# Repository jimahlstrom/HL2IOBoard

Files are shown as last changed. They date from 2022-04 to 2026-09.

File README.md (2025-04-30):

# IO Board for the Hermes Lite 2 by N2ADR
**January 6, 2024**

**Please click the left button "-  ----" above for a navigation menu.**

**Register names are now fixed, but there may be additions. Further documentation is coming, stay tuned.
Please provide feedback, especially if you see a problem.**

This project is a 5 by 10 cm printed circuit board and related firmware. The board mounts in the same box as the Hermes Lite 2.
It mounts above the N2ADR filter board if one is installed.
The filter board and the IO board are independent of each other.
The PC running the SDR software sends the transmit frequency to the board.
The microcontroller on the board then uses the board's switches to control an amplifier, switch antenns or transverters, etc.
There are a variety of IO resources available and there will be different microcontroller software for each application.
The IO board is meant to be a general purpose solution to control hardware attached to the HL2.

The IO board could also be connected to the I2C bus on a single board computer to provide station control.

The board has a Pico microcontroller and IO resources including
5 volt gates, low side switches, a fan controller, and a UART. There are two SMA connectors for a separate Rx input and a Pure Signal input.
The board plugs into the [Hermes Lite 2](http://www.hermeslite.com) main board and replaces the 2x20
jumper that connects to the N2ADR filter board.
The board sits directly above the filter board (if any) as shown in the photos below.

To use the board it will be necessary to choose which switches you need and solder wire jumpers from the switches to the DB9 connector.
Then you must write or download firmware for the Pico that will operate the switches based on the transmit frequency.

#### IO board mounted above the filter board
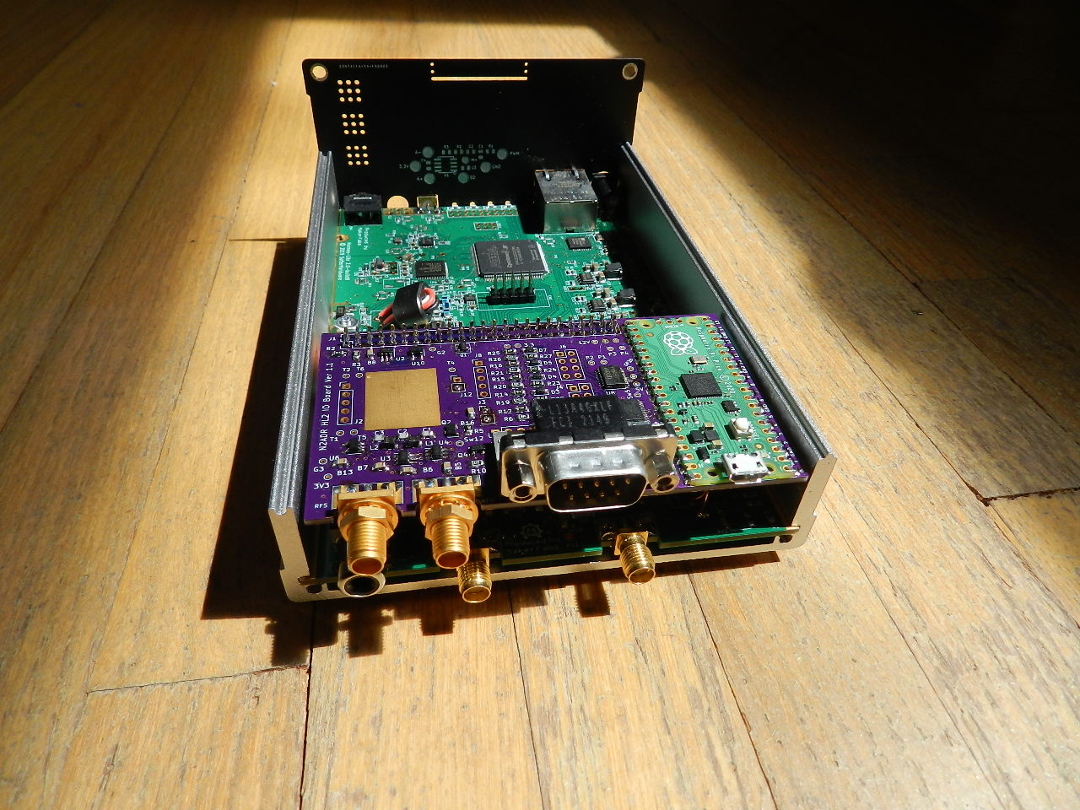
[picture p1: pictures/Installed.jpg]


#### Top view of the board
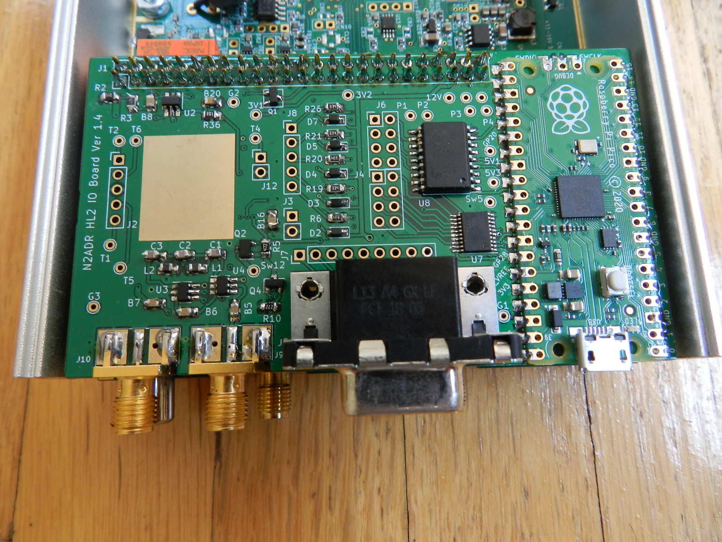
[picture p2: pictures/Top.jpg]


#### Bottom view of the board
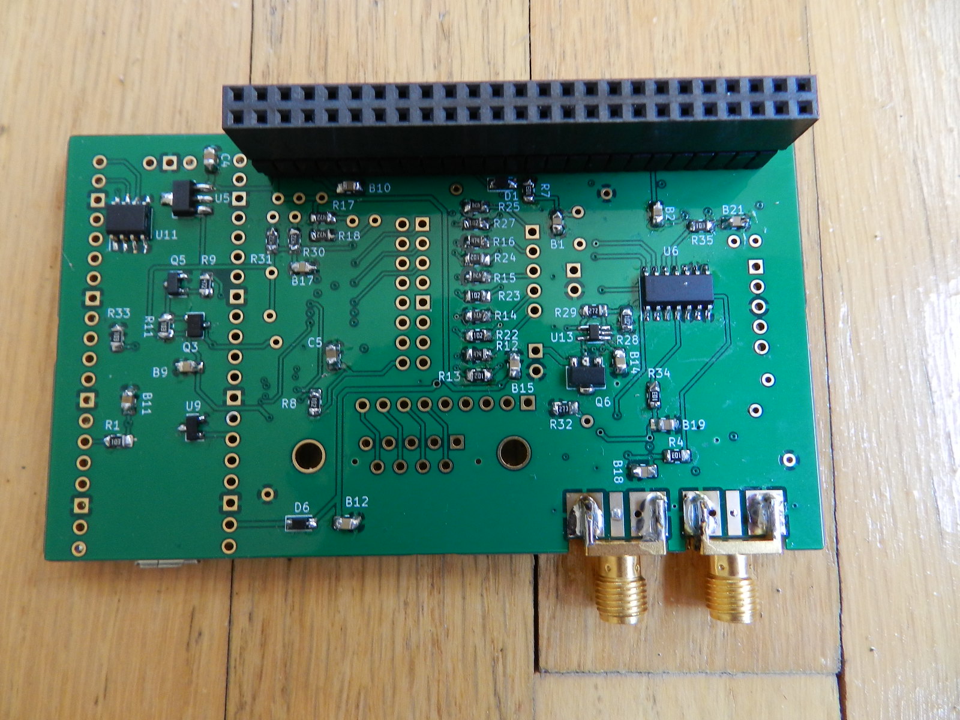
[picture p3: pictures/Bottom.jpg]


## Modification to the HL2 Main Board
The HL2 main board must be modified by adding three extra header pins. In the picture below, look at the normal 20 pin
header at the back edge of the board. Following that, two holes are skipped, and then a 1x3 header is added. This changes the
20 pin header to a 25 pin header with two unused pins. The extra pins provide 3.3 volts, ground and VSUP.
VSUP is the 12 volt HL2 input supply taken after the fuse.
It is convenient to place the 2x20 pin header across the existing pins and the three added pins to provide
alignment when soldering. The IO board has a 2x25 pin header. When installed, this connects the HL2 to the filter board as usual.

For the three-pin header you need the same size as the 1x20 header on the main HL2 board. The pin pitch is 2.54 mm.
On my HL2, the total height is 11.43 mm with 3.05 mm below the PCB. The pins are square and 0.64 mm on a side.
But my HL2 is an old one, so check what size your pins are. The exact height is not too critical.

#### Added three-pin header
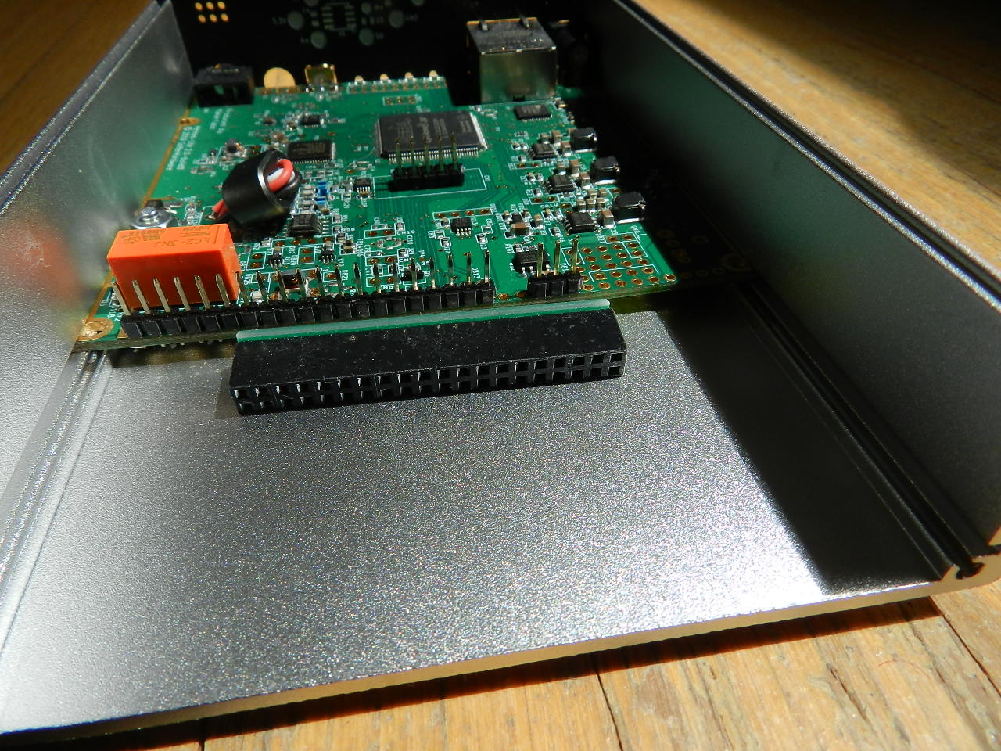
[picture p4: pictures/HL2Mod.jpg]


## Initial Testing of the IO Board
Please test the IO board when you get it.
First program the Pico with the test program.
Power off the HL2 and connect a USB cable to the IO Board.
Push the button on the Pico and then plug the USB cable into your PC.
The Pico will appear as a flash drive on the PC. Then copy the file n2adr_test/build/main.uf2 to the Pico. The Pico will reboot and the Pico LED will flash slowly.

Now apply power to the HL2. Use an oscilloscope to see the test signals.
  * Look for pulses of 1,2,3,4,5,6,7 milliseconds on J4 pins 1 to 7.
  * Look for 3.0 volts DC on J4 pin 8.
  * Look for 0.5 * supply voltage at J3 pin 1.
  * Look for a 5.0 volt 500 Hz square wave at Sw5.
  * Look for a supply voltage 250 Hz square wave at Sw12.

Connector J6 has MOSFETs that short the pin to ground.
To test, connect a DC voltage of 3.3 to 16 volts to one end of a resister of a few thousand ohms.
Connect the other end to an oscilloscpe, and use this end to probe J6 pins 1 to 7.
You should see the same signal as on J4 but with reverse polarity.

The test program can generate a test pattern for the antenna tuner protocol. Write a "1" to REG_ANTENNA_TUNER. SDR authors can use this to help write code for this feature. 

## Design of the IO Board Hardware
The IO board is a four-layer PCB. Rather large parts are used, with none smaller than 0805 (2012 metric). It is designed to be easy to solder at home. It is only necessary to mount the parts you plan to use.

Please refer to the [schematic](KiCad/HL2IOBoard.pdf).
The IO board has two I2C addresses. Address 0x41 register 0 is a read only register that returns the hardware version number
in bits 3 to 0, and 0xF in bits 7 to 4. So for this hardware version, it returns 0xF1. If other IO boards become available,
they will return different version numbers. This is the hardware version and will be returned even if the firmware is not running.
Reading this register can test whether the filter board is installed.

The Pico microcontroller listens to I2C address 0x1D. This is distinct from the filter board I2C address, and the IO board will
not conflict with or control the filter board. The IO board has these resources controlled by the Pico:

 * Eight 5 volt CMOS outputs and eight low-side switches (mosfets to ground). Both are controlled by the same Pico pin,
so they can be used in any combination, but only up to eight total. They are high speed except for output 8. This has an RC filter and is intended for
optional zero to five volt PWM DC output. The DC output can be programmed to change according to the band in use, and is used to
change bands in external amplifiers. If not needed, output 8 can still be an output, but at slow speed.
 * Five logic inputs that are protected, and work from plus 3.3 to 20 volts.
 * A source of switched 12 volt power.
 * A source of switched 5 volt power.
 * A variable DC voltage from zero to about 12 volts. This is intended to drive a fan.
 * A logic input that reads the state of EXTTR from the HL2.
 * An SMA receive input.
 * Control for a switched high pass filter in the receive input.
 * An SMA Pure Signal input.
 * Pico GPIO 5 is unused.
 * Pico GPIO 26, 27 and 28 are unused. They can be used for 3.3 volt logic or for ADC inputs. The ADC reference is 3.00 volts.
 * Any Pico pins can be used directly at 3.3 volt logic.

These resources can be used for various purposes. The Pico has two UARTs. Output 1 and Input 1 can be used for UART Tx and Rx.
Note that the signal voltages are zero and five volts. This is common for communication between microcontrollers.
But the standard RS232 levels are more like plus and minus eight volts, so a connection to a PC will require an interface IC.

A "low-side switch" is a mosfet to ground. They are commonly used to switch relays. But they can also implement a wired-or bus
such as a one-wire bus or an I2C bus. The Icom AH-4 antenna tuner can be controlled this way. The switches are implemented
in a TBD62381AFWG,EL integrated circuit. This has an absolute maximum rating of 50 volts and 500 ma per channel.

**These low-side switches are NOT protected against inductive loads. Always place a diode across relay coils and any other inductive load.**

There is a 15x18 mm bare copper area for prototyping. There is a 1x5 header J2 and a 1x2 header J12 to plug in a perf board for additional area.

The board has a DB9 connector and the pins are wired to a 1x9 pin header. The outputs go to two 2x4 headers, and the inputs go to a 1x5 header.
Other IO goes to small pads. The headers are not installed. Wire everything up as desired with hookup
wire to the pads and to the DB9 pads. Of course, you can add headers if desired.

### Table of IO Resources

|Software Pin Name |Usage|Connector Reference|
|---|-----|---|
|GPIO00_HPF|Control HPF in Rx path||
|GPIO01_Sw12|Switched VSUP (usually 12 volts)|Sw12|
|GPIO02_RF3|Control Pure Signal input||
|GPIO03_INTTR|Control HL2 T/R relay||
|GPIO04_Fan|Zero to 11.5 fan voltage|J3|
|GPIO05_xxx|not connected||
|GPIO06_In5|Protected logic input|J8 pin 5|
|GPIO07_In4|Protected logic input|J8 pin 4|
|GPIO08_Out8|5V logic ; low side switch|J4 pin 8 ; J6 pin 8|
|GPIO09_Out7|5V logic ; low side switch|J4 pin 7 ; J6 pin 7|
|GPIO10_Out5|5V logic ; low side switch|J4 pin 5 ; J6 pin 5|
|GPIO11_Out4|5V logic ; low side switch|J4 pin 4 ; J6 pin 4|
|GPIO12_Sw5|Switched 5 volts|Sw5|
|GPIO13_EXTTR|Logic input EXTTR, High for Rx, low for Tx||
|GPIO14_I2C1_SDA|HL2 I2C bus||
|GPIO15_I2C1_SCL|HL2 I2C bus||
|GPIO16_Out1|5V logic ; low side switch|J4 pin 1 ; J6 pin 1|
|GPIO17_In1|Protected logic input|J8 pin 1|
|GPIO18_In2|Protected logic input|J8 pin 2|
|GPIO19_Out2|5V logic ; low side switch|J4 pin 2 ; J6 pin 2|
|GPIO20_Out3|5V logic ; low side switch|J4 pin 3 ; J6 pin 3|
|GPIO21_In3|Protected logic input|J8 pin 3|
|GPIO22_Out6|5V logic ; low side switch|J4 pin 6 ; J6 pin 6|
|GPIO25_LED|Pico on-board LED||
|GPIO26_ADC0|not connected||
|GPIO27_ADC1|not connected||
|GPIO28_ADC2|not connected||

## IO Board Pico Firmware
### Installing Firmware
Firmwares for the Pico are in subdirectories of HL2IOBoard. Look in the source files to see what they do.

- n2adr_test   Test program to toggle the 5 volt outputs.
- n2adr_basic  Very basic example.
- n2adr_lib    Library of useful subroutines used in the above.
- n1adj_hr50   Control the [Hardrock-50](https://hobbypcb.com/products/hardrock-50-hf-power-amp-kit) amplifier.

To create your own firmware, install the Pico SDK and create a directory for your code.
You may want to clone my github project to get you started.
Export the location of your SDK: export PICO_SDK_PATH=/home/jim/etc/pico-sdk.
Copy the file pico-sdk/external/pico_sdk_import.cmake to your directory.
Copy my CMakeLists.txt and main.c to your directory and edit them as desired.
Make a "build" subdirectory.
Change directories to the build directory and enter "cmake .." and "make".
See the Pico documentation for more detail.
Be careful with i2c_slave_handler(), as it is an interrupt service routine. Return quickly and do not put printf's here! Just set a flag and look for it in the loop at the end of main().

To install the firmware, power off the HL2 and connect a USB cable to the IO Board.
Push the button on the Pico and then plug the USB cable into your PC.
The Pico will appear as a flash drive on the PC. Then copy the file build/main.uf2 to the Pico. 

There is an LED on the Pico. When the firmware is running, it flashes slowly. When the Pico receives I2C traffic directed to its address, it flashes faster.

### Firmware Design

The Pico listens to I2C address 0x1D and you can read and write to registers at this I2C address. Writes always send a one-byte address and one byte of data. Since the address is one byte, the data item is stored in a 256 byte array named "Registers".
All registers are initialized to zero at power on and after a software reset.
You can write to any register, not just the ones in the table below.
So a write to register REG_ANTENNA_TUNER (equal to 7) looks like this:

Registers[REG_ANTENNA_TUNER] = datum;

Reads always send a one byte address and return four bytes of data.
A read from register REG_ANTENNA_TUNER returns Registers[REG_ANTENNA_TUNER] and the next three registers.

There are some exceptions to this general pattern and all are noted below.

The Pico is an I2C slave device, so reads and writes result in a call to the interrupt service routine
in i2c_slave_handler.c. This routine must return fast to avoid hanging the bus. So a typical program would
not alter i2c_slave_handler.c. It would have a polling loop in main.c to check for changes in any registers
it cares about and would perform needed actions there.

#### Frequency Codes

The files n2adr_lib/frequency_code.c and frequency_code.py contain functions to convert a frequency in hertz to a one-byte code,
and to convert a code back to a frequency. The code is a useful one-byte approximation of the frequency
which is sufficient to recognize the band and to select antennas.
The codes are monotonic in frequency. The special code zero means the frequency was not entered and is unspecified.
A table of all the codes is at [frequencycodes.html](http://james.ahlstrom.name/frequencycodes.html).
Run the Python file "python frequency_code.py" to print your own table of codes.

#### Band Codes

A band code is a single frequency code for each band.
The band code is chosen to be as close to the band frequency as possible. All other frequency codes are assigned to the closest band code.
A table of band codes is in hl2ioboard.h.
You can use the band code to select antennas, or you can use the frequency code directly.

The band code is convenient because some bands have multiple frequency codes. And since all frequency codes resolve to the
closest band code, there are no gaps in coverage. If you tune outside the band, the closest band antenna is chosen.

#### Global Variables

These global variables are set in i2c_slave_handler() when data is received:

  * extern uint64_t new_tx_freq;
  * extern uint8_t new_tx_fcode;

The Tx frequency and Tx frequency code are set when the Tx frequency changes.

  * extern bool rx_freq_changed;
  * extern uint8_t rx_freq_high;
  * extern uint8_t rx_freq_low;

These are set when any of the twelve Rx frequencies change. If all Rx frequencies are zero, rx_freq_high and low are both zero.

  * extern uint8_t Registers[256];

This is the array of all register data.

  * extern uint8_t firmware_version_major;
  * extern uint8_t firmware_version_minor;

You must set the version in your main routine so it can be returned to software.

#### Library Functions

The directory n2adr_lib contains utility functions to make writing Pico software easier.

  * void configure_led_flasher(void)

Call this once near the start of your Pico program. It controls flashing the Pico LED.

  * void configure_pins(bool use_uart1, bool use_pwm4a)

This sets the configuration of the Pico GPIO pins, and you must call this once near the start of your program.
If use_uart1, J8 pin 1 and J4 pin 1 are UART pins; otherwise they are regular logic.
If use_pwm4a, J4 pin 8 is used for a variable 0 to 5 volt band voltage; otherwise it is regular logic.

  * uint8_t hertz2fcode(uint64_t hertz)
  * uint64_t fcode2hertz(uint8_t code)

These functions convert between a 5-byte frequency and a 1-byte frequency code. They are in frequencycode.c.
The file frequencycode.py is the same code in Python, and it is not used here. It is included for convenience.

  * uint8_t fcode2band(uint8_t fcode)

This converts a frequency code to a band code. A band code is a single frequency code for each band. See below.

  * void ft817_band_volts(uint8_t band_code)
  * void xiegu_band_volts(uint8_t band_code)

These are used to generate a zero to five volt band voltage on J4 pin 8.

  * i2c_slave_handler.c

This contains the I2C interrupt handler that is called for I2C reads and writes. Since it must return quickly,
it mostly sets registers and global variables that you can test in a loop in your Pico program.
When it receives the Tx frequency, it sets new_tx_freq to the frequency and new_tx_fcode to the corresponding frequency code.
It also uses firmware_version_major and firmware_version_minor, and you must set these in your Pico program.

  * icom_ah4.c

This contains code to control the Icom AH4 antenna tuner. It is untested.

#### Table of I2C Registers

When you write code, please use the register names shown. The names are in i2c_registers.h.

|Register|Name|Description|
|---|----|---|
|0|REG_TX_FREQ_BYTE4|Most significant byte of the 5-byte Tx frequency in Hertz|
|1|REG_TX_FREQ_BYTE3|Next Tx frequency byte|
|2|REG_TX_FREQ_BYTE2|Next Tx frequency byte|
|3|REG_TX_FREQ_BYTE1|Next Tx frequency byte|
|4|REG_TX_FREQ_BYTE0|The least significant byte of the Tx frequency.|

The transmit frequency is a five-byte integer number in hertz. You can send BYTE1 to BYTE4 in any order.
When BYTE0 is sent, the Pico will update the global 64-bit integer new_tx_freq and the 8-bit frequency code new_tx_fcode.
This happens in an interrupt service routine in n2adr_lib/i2c_slave_handler.c.
Use a polling routine in your main.c to look for changes. See the example in n2adr_basic.
If a transverter is in use, the Tx frequency includes the transverter offset.

|Register|Name|Description|
|---|----|---|
|5|REG_CONTROL|Write 1 to reset all the registers to zero.|
|6|REG_INPUT_PINS|Read only. The input pin bits: In5, In4, In3, In2, In1, Exttr|
|7|REG_ANTENNA_TUNER|Control an antenna tuner|

A write to register REG_ANTENNA_TUNER is a command to the tuner. I am modeling this on the Icom AH-4 but I want it to work in general.
See the code in n2adr_lib/icom_ah4.c.
A write of 1 starts a tune request.
A write of 2 is a bypass command. Other tuners may have more commands. The Pico will talk to the ATU and change the register to higher numbers to indicate progress.
The PC must read this register while tuning progresses. If the register reads as 0xEE the PC must send RF to the ATU, and stop RF when 0xEE stops.
A final value of zero indicates a successful tune. Values of 0xF0 and higher indicate that tuning failed.
Note that the IO board can not initiate RF and so the need for 0xEE.
SDR software is not required to implement this command. In the future there may be an external program to do this.

|Register|Name|Description|
|---|----|---|
|8|REG_FAULT|Read only. Zero for no fault. The meaning of non-zero codes is not currently defined.|
|9|REG_FIRMWARE_MAJOR|Read only. Firmware major version|
|10|REG_FIRMWARE_MINOR|Read only. Firmware minor version|
|11|REG_RF_INPUTS|The receive input usage, 0, 1 or 2.|

REG_RF_INPUTS determines how the SMA receive input J9 and the Pure Signal input J10 are used.
Mode 0 means that J9 is not used, and the usual HL2 input is the receive input.
In mode 0 the Pure Signal input J10 is mixed with the receive signal.
For modes 1 and 2, J9 is used instead of the usual HL2 receive input.
Mode 1 means that J9 is used for the receive signal and the Pure Signal input is not available.
Mode 2 means that for receive, J9 is used for the receive signal;
and that for transmit, the Pure Signal input is passed to the HL2 instead of a receive signal.

|Register|Name|Description|
|---|----|---|
|12|REG_FAN_SPEED|The fan voltage as a number from 0 to 255|
|13|REG_FCODE_RX1|The frequency code for the first receiver RX1|
|14-24|REG_FCODE_RX2 to RX12|The frequency code for receiver RX2 to RX12|

The HL2 can have from one to twelve independent receivers. SDR software can use this feature
to scan multiple bands for digital or CW signals. Choosing an antenna requires knowing all the Rx frequencies.
The Rx frequencies are sent as a one-byte frequency code to registers 13 to 24 with names REG_FCODE_RX1 to RX12.
The HL2 always has RX1, but if it is unspecified (zero) it is the same as the Tx frequency.
If any Rx frequency is changed, the global boolean rx_freq_changed is set to true.
If a transverter is in use, the Rx frequency includes the transverter offset.

|Register|Name|Description|
|---|----|---|
|25|REG_ADC0_MSB|The most significant byte of ADC0|
|26|REG_ADC0_LSB|The least significant byte of ADC0|
|27|REG_ADC1_MSB|The most significant byte of ADC1|
|28|REG_ADC1_LSB|The least significant byte of ADC1|
|29|REG_ADC2_MSB|The most significant byte of ADC2|
|30|REG_ADC2_LSB|The least significant byte of ADC2|

The Pico has one 12-bit ADC that can read from ADC0, ADC1 and ADC2 on pins GPIO26, GPIO27 and GPIO28.
Always read the most significant byte first because that triggers the conversion.
A read from ADC0 returns the value of ADC0 and ADC1 in the four byte response.
A read from ADC1 returns the value of ADC1 and ADC2.
Reading the two values in quick succession can be used to calculate SWR from forward and reverse power.

|Register|Name|Description|
|---|----|---|
|31|REG_ANTENNA|Choose among multiple antennas|

Normally, the antenna choice is calculated by the Pico based on the Tx and Rx frequencies.
But there may be multiple antennas available for a single band.
The high four bits of REG_ANTENNA is the Tx antenna, and the low four bits is the Rx antenna for the current band.
A zero means the first (default) antenna.

|Register|Name|Description|
|---|----|---|
|32|REG_OP_MODE|Set the operating Mode|

||Mode|Value|Mode|Value|Mode|Value|Mode|Value|
|---|---|---|---|---|---|---|---|---|
||LSB|0|USB|1|DSB|2|CWL|3|
||CWU|4|FM|5|AM|6|DIGU|7|
||SPEC|8|DIGL|9|SAM|10|DRM|11|
||AM_LSB|12|AM_USB|13|

Operating mode values are based on Thetis internal definitions.
Note that value zero does not mean "unspecified".

|Register|Name|Description|
|---|----|---|
|167|REG_STATUS|Read or write to Sw5 and Sw12. Read the In1 configuration.|
|168|REG_IN_PINS|Same as REG_INPUT_PINS plus Out1 and Out8 configuration.|
|169|REG_OUT_PINS|Read or write to GPIO Out8 to Out1 directly.|
|170|GPIO_DIRECT_BASE|Map this register to GPIO 0|
|171-198||GPIO 1 to 28|

A read or write to registers GPIO_DIRECT_BASE to GPIO_DIRECT_BASE + 28 reads or writes to the Pico GPIO pins 0 to 28.
This supports using Steve's hermeslite.py or similar to control the Pico registers directly.
A user could write a program to switch antennas without adding C code to the Pico.
Since the SDR program writes Tx and Rx frequencies to the Pico, a third party program could read them back to select the antenna.
For C programmers, it would still be easier to write the code into the Pico.

The other registers add further support. Bits are numbered from 7 to zero and the most significant bit is 7.

  * REG_STATUS

Bit 0 is Sw5, bit 1 is Sw12, bit 2 is 1 if In1 is configured as a UART.

  * REG_IN_PINS

This is read-only. It is the same as REG_INPUT_PINS, and adds two bits. Bit 6 is 1 if Out1 is configured as UART.
Bit 7 is 1 if Out8 is configured as band volts.

  * REG_OUT_PINS

This reads and writes Out1 to Out8 directly. Bit 0 is Out1 and bit 7 is Out8.

|Register|Name|Description|
|---|----|---|
|200-255||Reserved for SDR authors. If you use them, please document them.|

## Modifications to SDR PC Software

The IO board connects to the I2C interface in the Hermes Lite 2.
The [HL2 protocol](https://github.com/softerhardware/Hermes-Lite2/wiki/Protocol)
provides a way to send and receive I2C messages from host SDR software to the IO board to control its operation.
Quisk uses the ACK bit with I2C commands. As described in the protocol, these commands should
be sent at intervals so they don't disrupt normal protocol commands.

Since the PC can read and write the I2C bus to communicate with the IO board, it would be possible for SDR software
authors (Quisk, Spark, Power SDR, etc.) to write extensive logic to control IO. This is NOT the desired result. Instead
users should write new Pico firmware to provide the services they require. It is easy to write firmware for the Pico.
Ideally, an owner of a given power amp, for example HR50, would write a custom firmware and provide a wiring diagram for that amp.

**Do NOT ask authors to modify SDR software! Write new firmware instead!**

### Reset

The IO board registers are static and may have old data.
When your SDR program starts, write 1 to REG_CONTROL to set all registers back to zero.

### Transmit Frequency

The only required SDR modification is sending the transmit frequency.
SDR software must send the transmit frequency to provide band information to power amps, transverters and loop antennas.
You can wait for the band to change, and then just send a frequency in the band. For example, if the
user presses the 40 meter button, send 7.0 MHz. This is enough to determine the band, but not enough to tune a loop antenna.
You can send the exact Tx frequency, but since the user is probably doing a lot of tuning, it is best to limit the I2C
traffic. Quisk sends the Tx frequency at a maximum rate of once every 0.5 seconds, and only if it changes. The frequency
data in registers BYTE1 to BYTE4 are static, and are only used when register BYTE0 is written. So you don't need to re-send them unless
they change.

### Receive Frequencies

You may need to send the twelve receive frequencies if your SDR software supports multiple receivers.
The Pico will use this to select a receive antenna, probably by finding the highest frequency and
setting low pass filters to that band. If all Rx frequencies are zero, the Rx band is the same as Tx.

### RF Receive Input

The mode control REG_RF_INPUTS is 0, 1 or 2, and is a user setting. There needs to be an option to set this.

### Fan Control

The fan speed control can be an internal calculation based on temperature, as is currently the case for the fan control
in the HL2 gateware. I don't see the need for a user option for this. Quisk does not implement the fan.

## IO Board Control Software

The software directory contains the Python program n2adr_ioboard.pyw which can be used to control the IO board.
It uses Steve's hermeslite.py software, and a copy is included. To use it, copy the two files to a convenient directory.
You will need to install the netifaces package as follows:

python -m pip install netifaces

Then run the program:

python n2adr_ioboard.pyw

#### Control Program
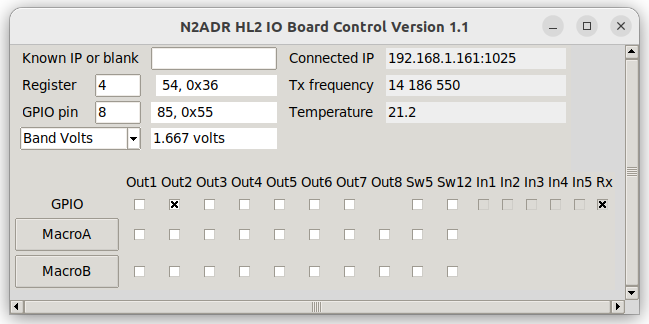
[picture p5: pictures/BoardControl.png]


#### Reduced to a Tool Bar


The program will report the IO board status. You can change the status from the program, and this
may reduce the need to modify SDR programs. It provides a way to control the IO board from Python
rather that write code for the Pico.

Normally the program will search for the HL2. If you need to select one of several HL2's or if searching doesn't work,
enter the IP address and press Enter.

Some fields just report status. Click on the fan voltage or band voltage to change the values.
Click on the GPIO boxes to change the values.
The Macro buttons copy their values to the GPIO row all at once.

The N2ADR control program is not "finished" (does any program ever get finished?) and I invite
a discussion about what it should do.

**End of Documentation**

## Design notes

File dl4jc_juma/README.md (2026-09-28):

# JUMA firmware for the Hermes Lite 2 IO board

Band switching and status readback for a **JUMA PA-100D** (and its RS-928
clone) from a [Hermes Lite 2](http://www.hermeslite.com) through N2ADR's
[IO board](https://github.com/jimahlstrom/HL2IOBoard). The SDR software sends
the transmit frequency to the board over I2C, the Pico turns it into a `=Bn`
band command on the serial port, and the PA's status comes back into I2C
registers the host can read.

This is the same path M0HPF's `m0hpf_spe` firmware takes for an SPE Expert —
Pico UART, a MAX3232 for RS-232 levels, the amplifier's own command set. Only
the commands differ. The parser and the band table are the ones the ESP32
firmware in this repository uses, not a copy, so a corrected band edge is
corrected in both.

> **No warranty.** This switches the band filters of an amplifier, and the
> wrong filter can destroy the output stage. Before the first serious use,
> check the wiring with the PA's built-in RS-232 loopback test and rehearse the
> band switching in STANDBY.

## What you need

| For | |
|---|---|
| Building the firmware | the Pico SDK, ARM's own toolchain (**not** Homebrew's `arm-none-eabi-gcc`, it ships without newlib), and a built `n2adr_lib` from the HL2IOBoard project |
| The hardware | an IO board with a Pico, a **MAX3232** level shifter, and three wires to the amplifier |
| The window | Python 3.8 or newer with **Tk 8.6 or newer**, and `pyserial` only for the USB route |
| Packaging the window | `pyinstaller`, and `pillow` if you want to redraw the icon |

**Tk 8.6 is not a formality.** Apple still ships Tk 8.5 with `/usr/bin/python3`,
and on current macOS it lays this window out correctly and then paints neither
the labels nor the meters — you get a window with three checkboxes in it and
nothing else. `juma_gui.py` checks the version and says so; the packaged
application carries its own Tk and cannot run into it at all.

On Debian and Ubuntu, `python3-tk`. On Fedora, `python3-tkinter`. On macOS,
either a Homebrew `python3` with `python-tk`, or the packaged application.

## What the JUMA needs that the SPE does not

Three properties of the JUMA protocol shape the firmware:

- **It only speaks when asked.** The SPE polls the transceiver; the JUMA
  answers `=R` and is silent otherwise. The Pico is the master here and polls.
- **Remote mode times out.** 5 s after the last command the PA leaves remote
  mode and falls back to STANDBY. The 500 ms `=R` poll is what keeps it alive —
  it is not there for the display.
- **`=Bn` is a *manual* band selection.** It moves the PA from A to M, and a
  band change can knock it out of OPERATE.

Because of the last point the firmware leaves OPERATE alone by default: it
follows the band and touches nothing else. If you want it held in OPERATE, ask
for it — see `JUMA_MODE_HOLD_OPERATE` below.

## Hardware

An IO board, a Pico, and a **MAX3232** level shifter — the PA has true RS-232
levels, and TTL on its input destroys it. The small blue "HW-027" board M0HPF
uses is one option; any MAX3232 breakout works.

**MAX232 is the wrong part**: 5 V only, and its receiver output swings to 5 V.

The plan below puts a **standard RS-232 DTE pinout on the board's own Sub-D
connector**, so a plain Sub-D-to-jack cable goes straight from the board to the
amplifier and nothing is wired inside the box.

### The whole signal chain

```
                      TTL side                      RS-232 side       cable
                      ────────                      ───────────       ─────

 TX   Pico GP16 ──┬─► 74HCT541 ─► J4.1 ══► T1IN            (MAX3232)
                  └──────────────────────► T1IN    T1OUT ══► J7.3 = Sub-D 3 ──► tip
 RX   Pico GP17 ◄─┬── 1K ◄─ divider ◄─ J8.1 ◄══ R1OUT
                  └◄─────────────────────────── R1OUT    R1IN  ◄══ J7.2 = Sub-D 2 ◄── ring

      5 V module:  5V1 pad ═══════════════════► VCC
      3.3 V module: Pico pin 36 or 3V1 pad ═══► VCC
      both:        G1/G2/G3 pad ═════════════► GND   ═══► J7.5 = Sub-D 5 ─── sleeve
```

For each direction take **one** of the two lines: through the board (a 5 V
module) or straight to the Pico pin (a 3.3 V module). Left of the MAX3232
everything is TTL, right of it true RS-232, and the Sub-D ends up with the
pinout of a normal serial port — so the cable to the amplifier is an ordinary
one with nothing clever in it.

### Board side, either way

`configure_pins(true, false)` is what turns J4 pin 1 and J8 pin 1 into the UART,
so those two are not available as a switch output and a logic input — whether or
not you use them for the shifter.

The firmware switches **Sw5** on at start-up, so a 5 V shifter fed from Sw5
comes up with the board rather than looking like a dead amplifier. Wired to 5V1
or to 3.3 V this changes nothing.

Ground: `G1`, `G2` and `G3` are the pads meant for it. M0HPF's instructions use
J12 pin 2, which is ground as well.

### Two ways to wire the TTL side

The board's TTL side is 5 V: J4 pin 1 is the Pico's TX through a 74HCT541
buffer, and J8 pin 1 is a protected input — a divider straight out of the
schematic:

```
J8 pin 1 ──┬── 330K ──┬── 1K ── GPIO17
           │          └── Schottky to +3V3 (clamp)
          470K
           │
          GND
```

The Pico therefore sees `Vin × 470/(330+470) = Vin × 0.59`. Which of the two
routes below you take depends on what your MAX3232 module wants.

#### A 5 V module: J4 pin 1 and J8 pin 1

The straightforward route, the one `m0hpf_spe` uses. A 5 V receiver output
arrives at the Pico as **2.9 V** — a clean logic high — and the buffered output
gives the module the 5 V TTL it expects.

| MAX3232 | IO board |
|---|---|
| `T1IN` — TTL input (`TX`, `TXD`, `<-`) | **J4 pin 1** |
| `R1OUT` — TTL output (`RX`, `RXD`, `->`) | **J8 pin 1** |
| **+** | **5V1** or **5V3** |
| **−** | **G1**, **G2** or **G3** |

One thing to keep an eye on at 115200: the divider's source impedance is
330K∥470K ≈ 194 kΩ, and with the clamp diode and stray capacitance (~15 pF)
that is a time constant of roughly 3 µs against a bit time of 8.7 µs. It works,
but without much to spare — and it explains why the SPE and Hardrock firmwares
never meet this: at 19200 a bit lasts 52 µs. `REG_JUMA_BADLINES` measures it.
If it climbs steadily, replace **R25 (470K)** and **R26 (330K)** with the same
ratio two decades lower, 4.7K and 3.3K: same division, same protection, time
constant down to about 30 ns.

#### A 3.3 V module: straight to the Pico's pins

Going round the board's own input and output needs a reason, so here it is,
twice over. Both come out of the schematic, not out of preference.

**The level does not survive the divider.** In1 divides by 330K/(330K+470K) =
0.59. A 5 V receiver output arrives as 2.9 V, a clean high — but a 3.3 V one
arrives as **1.9 V**, below the RP2040's specified input high threshold. The
Schmitt trigger may well take it; it is not designed to.

**And at 115200 the divider is tight even when the level is right.** Its source
impedance is 330K∥470K ≈ 194 kΩ, and with the clamp diode and stray capacitance
(~15 pF) that is a time constant of roughly 3 µs against a bit time of 8.7 µs.
That is why the SPE and Hardrock firmwares in this project never meet it: at
19200 a bit lasts 52 µs and 3 µs is nothing. At 115200 it is a quarter of the
eye.

Wired straight to the pin, both problems go at once. The full 3.3 V swing
arrives, and the divider network — still hanging off GP17 through R27, 1 kΩ —
now charges its 15 pF through that 1 kΩ instead of 194 kΩ: about 15 ns. The
parasitic load is 3.3 V across roughly 470 kΩ, some 7 µA.

The Pico is mounted with through-hole pads for every pin (`RPi_Pico_SMD_TH`), so
this is a wire, not a rework. Nothing on the board is modified and the firmware
does not change — it is still UART0 on GPIO16/17. A 5 V module has neither
problem and should use J4 pin 1 and J8 pin 1 as every other firmware here does.

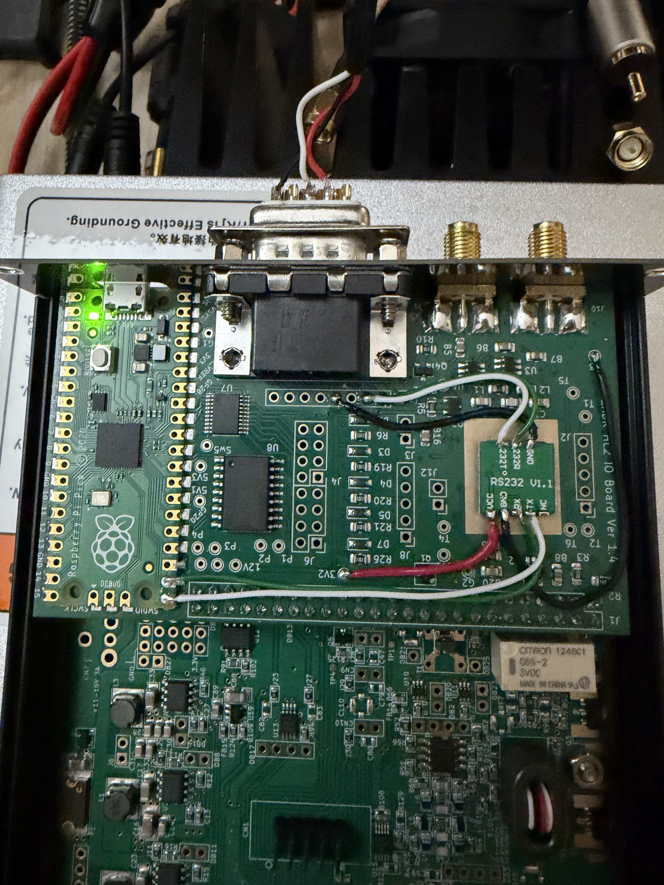
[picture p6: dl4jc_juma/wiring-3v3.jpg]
A 3.3 V module wired this way


Built that way it looks like this: the shifter sits on the free copper in the
middle, red from its `VCC` to the **3V2** pad, the three RS-232 wires off to the
Sub-D on the left, and the two TTL wires down to the Pico's own pins. Nothing is
soldered to J4 or J8 at all.

| MAX3232 | Pico pin | |
|---|---|---|
| `T1IN` — TTL input (`TX`, `TXD`, `<-`) | **21** (GP16) | 3.3 V, ahead of the 74HCT541 |
| `R1OUT` — TTL output (`RX`, `RXD`, `->`) | **22** (GP17) | 3.3 V, past the divider |
| **+** | **36** (3V3 OUT) | or the board's **3V1** / **3V2** pad |
| **−** | GND | **G1** / **G2** / **G3**, or Pico pin 38 |

GP16 is safe to tap: its only other nodes are `U7.8` and `U8.7`, and both are
*inputs* of driver ICs — the 74HCT541 that feeds J4 pin 1 and the TBD62381 low
side switch that feeds J6 pin 1. They never drive back, so one Pico output ends
up driving three inputs. GP17 has exactly one other node, `R27`, the 1 kΩ into
the protection network.

That does have a consequence. The 541's two output enables are hard-wired to
ground, so it is never off, and the TBD62381 input is driven unconditionally:

- **J4 pin 1** carries the transmit data as 5 V logic, and **J6 pin 1**
  switches its MOSFET with every serial bit. Unconnected both are harmless — but
  a relay on J6 pin 1 would chatter at 115200.
- **J8 pin 1** must stay unconnected too: anything driven into it would fight
  the module for GP17.

### Sub-D pinout on the board

Wire the three RS-232 signals to **J7**, the 1x9 header, whose pins go 1:1 to
the Sub-D **J5**. So J7 pin *n* is Sub-D pin *n*.

| Sub-D / J7 pin | Signal | Direction | From |
|---|---|---|---|
| **3** | TxD | board → PA | `T1OUT`, the driver output (`RS232T`, `<-`) |
| **2** | RxD | PA → board | `R1IN`, the receiver input (`RS232R`, `->`) |
| **5** | GND | — | G1 / G2 / G3 |

That is the normal DTE assignment, the same as a PC serial port. **The board's
Sub-D is male** (`DSUB-9_Male_Horizontal` in the schematic), so the cable needs a
**female** Sub-D.

> This deliberately differs from `m0hpf_spe`, which puts the output on pin 2 and
> the input on pin 3. That suits the cable the SPE expects; here the point is a
> connector that behaves the way every RS-232 port does, so the cable is an
> ordinary one.

### The cable

Sub-D 9 female → 3.5 mm stereo jack plug, three wires:

| Sub-D | | JUMA **PA-100D** | **RS-928** |
|---|---|---|---|
| pin 3 | TxD, into the PA | **tip** | **ring** |
| pin 2 | RxD, out of the PA | **ring** | **tip** |
| pin 5 | GND | **sleeve** | **sleeve** |

**The RS-928 has tip and ring the other way round** — that is the one wiring
trap on the clone. Sleeve stays ground on both.

Screened cable, screen on pin 5. Keep it short and away from the coax: this runs
beside a transmitter.

### Which pin on the module is which?

Breakout boards label these differently, and one of the labels is not
trustworthy. On the RS-232 side it is unambiguous: `RS232T` is the driver output
`T1OUT`, `RS232R` the receiver input `R1IN`. On the TTL side a pin marked `TX`
is usually the driver *input* — named from the point of view of the
microcontroller you attach, so it goes to the Pico's TX. Some boards name it
from their own point of view instead, and then it is the other way round.

Getting that wrong puts the Pico's GP16 output against the module's `R1OUT`
output. Two measurements settle it without risk:

1. **Module unpowered**, ohmmeter from each RS-232 pin to GND. The MAX3232's
   receiver input has about 5 kΩ to ground internally, so the pin reading
   **3–7 kΩ** is `R1IN` (`RS232R`). The high-impedance one is `T1OUT`
   (`RS232T`).
2. **Module on 3.3 V, nothing else attached.** Tie the TTL pin you believe is
   the input to GND and measure `T1OUT` against ground: about **+5.5 V**. Tie it
   to 3.3 V instead: about **−5.5 V**, because the driver inverts. If it does
   that, it is the driver input and belongs on GP16.

For the first try a **1 kΩ in series** in the GP16 line costs nothing at 115200
into a high-impedance input, and limits a wrong guess to a few milliamps.

### The whole thing as one table

Seven wires on the board, three in the cable. `→` is the direction the data
travels.

**TTL side** — pick one column for your module.

| MAX3232 module | 3.3 V module | 5 V module |
|---|---|---|
| `T1IN` — TTL **input** (`TX`, `TXD`, `TTL-IN`, `<-`) | **Pico pin 21** (GP16) | **J4 pin 1** |
| `R1OUT` — TTL **output** (`RX`, `RXD`, `TTL-OUT`, `->`) | **Pico pin 22** (GP17) | **J8 pin 1** |
| **+** | **3V2** pad (or Pico pin 36) | **5V1** pad (or 5V3) |
| **−** | **G1** / **G2** / **G3** pad | **G1** / **G2** / **G3** pad |

**RS-232 side** — the same either way. J7 is the 1x9 header; its pin *n* is
Sub-D pin *n* on J5.

| MAX3232 module | Board | Sub-D pin | Signal |
|---|---|---|---|
| `T1OUT` — RS-232 **output** (`RS232T`, `<-`) | **J7 pin 3** | 3 | TxD, board → PA |
| `R1IN` — RS-232 **input** (`RS232R`, `->`) | **J7 pin 2** | 2 | RxD, PA → board |
| **−** | **J7 pin 5** | 5 | GND |

**Cable** — Sub-D 9 **female** (the board's is male) to a 3.5 mm stereo plug.

| Sub-D pin | | PA-100D | RS-928 |
|---|---|---|---|
| 3 | TxD, into the PA | **tip** | **ring** |
| 2 | RxD, out of the PA | **ring** | **tip** |
| 5 | GND | **sleeve** | **sleeve** |

**Leave unconnected**

| | Why |
|---|---|
| **J4 pin 1**, **J6 pin 1** | on a 3.3 V module these still carry the transmit data — 5 V logic and a MOSFET switching at 115200 |
| **J8 pin 1** | on a 3.3 V module it would fight the module for GP17 |
| **Sw5** | the firmware switches it on; only of interest if a 5 V module is fed from there |

**Not part of this** — PTT. The PA is keyed from the HL2 to its own PTT jack,
or through a low-side switch on J6 that the host drives via `REG_OUT_PINS`. See
below.

### Before the first transmission

1. Amplifier in **STANDBY**, no RF.
2. Run the PA's built-in **RS-232 loopback test** (its own menu) with the cable
   plugged in. That checks the cable and the shifter without the Pico having to
   be right.
3. Flash a `JUMA_DEBUG` image (see below) and watch the USB port. A status line
   every 500 ms means the whole chain works. Rubbish instead of readable lines is
   a baud rate or a swapped tip/ring.
4. Read `REG_JUMA_LINK` and `REG_JUMA_BADLINES`. Link 1 and bad lines that stay
   put is what a healthy link looks like.
5. Only then rehearse the band switching, still in STANDBY, and check that the
   band on the PA's display follows the SDR.

### If bad lines keep climbing

`REG_JUMA_BADLINES` is the number to watch, and a steadily climbing one on a
5 V module points at the input divider — see above for the two resistors that
fix it. On a 3.3 V module wired straight to the Pico's pins the divider is out
of the path, so look elsewhere: a swapped tip and ring, a missing ground, or the
cable running alongside the coax.

The JUMA's baud rate is not adjustable, so 115200 is not negotiable either.

### PTT

This firmware does serial control only. The PA is still keyed the normal way —
from the HL2 to the PA's own PTT jack, or through one of the board's low-side
switches on J6 driven by the host via `REG_OUT_PINS`. Nothing here asserts PTT,
and nothing here needs to: the band is set between transmissions.

## Building and installing

### Toolchain

**Do not use Homebrew's `arm-none-eabi-gcc`.** That formula is a freestanding
compiler with no newlib — it has no `libc.a`, and the SDK's very first link
fails with `cannot find -lc`. Take ARM's own build instead:

```sh
cd ~
curl -fLO https://developer.arm.com/-/media/Files/downloads/gnu/14.2.rel1/binrel/arm-gnu-toolchain-14.2.rel1-darwin-arm64-arm-none-eabi.tar.xz
tar xf arm-gnu-toolchain-14.2.rel1-darwin-arm64-arm-none-eabi.tar.xz
ln -s ~/arm-gnu-toolchain-14.2.rel1-darwin-arm64-arm-none-eabi ~/arm-none-eabi
```

The Homebrew cask `gcc-arm-embedded` is the same toolchain, but it installs a
`.pkg` and wants an administrator password. The tarball does not.

### SDK and board library

```sh
git clone -b master --depth 1 https://github.com/raspberrypi/pico-sdk.git ~/pico-sdk
cd ~/pico-sdk && git submodule update --init --depth 1 lib/tinyusb   # for USB stdio

export PICO_SDK_PATH=~/pico-sdk
export PICO_TOOLCHAIN_PATH=~/arm-none-eabi

git clone --depth 1 https://github.com/jimahlstrom/HL2IOBoard        # next to this repo
cd HL2IOBoard/n2adr_lib && mkdir -p build && cd build && cmake .. && make
```

### This firmware

```sh
cd .../esp32-juma/hl2io/juma_pa
mkdir -p build && cd build
cmake ..            # add -DHL2IOBOARD=/path/to/HL2IOBoard if it is not the sibling
make
```

The first run fetches `picotool`, which the SDK builds for itself — that is
normal and takes a minute.

Then power off the HL2, hold the button on the Pico while plugging in USB, and
copy `build/main.uf2` to the drive that appears.

Built here with SDK 2.3.1 and the toolchain above: no warnings, 63.8 kB of
flash and 5.8 kB of RAM.

### Which image to build

Every mode bit can be written at runtime, over I2C or over the USB console, so
the only thing that really needs its own image is the trace. The options below
just decide what a board comes up with, which is what matters when nothing on
the host knows the registers.

| Build | For |
|---|---|
| `cmake ..` | out of the box: follows the band, holds the PA in OPERATE, and says once a second on USB what it and the amplifier are doing |
| `… -DJUMA_HOLD_OPERATE=OFF` | leave a STANDBY standing — for a board that is only meant to watch and follow |
| `… -DJUMA_PROXY=ON -DJUMA_TELEMETRY=OFF` | the USB port is the PA's serial port from power-up, for software that already speaks JUMA |
| `… -DJUMA_DEBUG=ON` as well | the bench: every line, every command, every state change |

| Option | Default | |
|---|---|---|
| `JUMA_TELEMETRY` | **ON** | one status line per second on USB. On by default because it answers "is this thing running" with a terminal and nothing else, which is the first question anybody has — and because `juma_gui.py` reads that line over USB |
| `JUMA_HOLD_OPERATE` | **ON** | put the PA back into OPERATE when it drops to STANDBY — three tries, 5 s apart, never while an alarm is latched, and the counter is reset by every band command, because a band change knocking it out is expected |
| `JUMA_PROXY` | OFF | the USB port carries the PA's serial traffic verbatim. It suppresses the telemetry line, and everything typed at the port reaches the amplifier, so it is something to ask for rather than to be given |
| `JUMA_DEBUG` | OFF | the trace, and leave it off together with `JUMA_PROXY` — a trace line is something the PA would never say |

The same defaults are restored when the host resets the board (a write of 1 to
`REG_CONTROL`), along with the firmware's own retry counters and the frequency it
was following — after such a reset no band command goes out until a new frequency
arrives.

### The USB console

Type into it with any terminal; USB CDC ignores the baud rate.

```sh
pio device monitor -p /dev/cu.usbmodem*        # or: screen /dev/cu.usbmodem* 115200
```

| What you type | |
|---|---|
| `=R`, `=O`, `=C`, `=G2`, … | goes to the PA. `=Bn` only with band following off; `=A` switches following off as it goes |
| `mode=0E` | set `REG_JUMA_MODE` |
| `mode+04` / `mode-08` | set or clear those bits, leaving the rest of the byte alone |
| `bootsel` | reboot into the bootloader. The button needs a RESET to be sampled, and plugging in USB does not reset a Pico already powered from the radio — so with the HL2 switched on the button does nothing and this is the way in |
| `reg=51:02` | write any register — `REG_JUMA_SET_GAIN` = 2 here |

`mode+` and `mode-` are what a program uses: switching the telemetry feed on
should not force it to decide, blindly, what happens to the OPERATE hold.

Anything longer than the PA's own commands is refused rather than truncated —
half of a mistyped command is worse than none of it.

With no terminal attached, printing costs nothing: the SDK discards the output as
soon as it sees the port is not open. A terminal that is attached and then stops
reading does cost something, so these builds lower
`PICO_STDIO_USB_STDOUT_TIMEOUT_US` from 500 ms to **10 ms** — a stalled reader
loses output rather than costing the PA its remote mode.

## What it does

- **Follows the transmit frequency.** `new_tx_freq` from the I2C handler goes
  through the shared band table, and `=Bn` goes out once the frequency has held
  still for 150 ms. No band command is ever sent while either the HL2 (EXTTR)
  or the PA (status field 3) says transmit.
- **Stays off bands the PA has no filter for.** 6 m, 60 m, out-of-band: no
  command goes out at all, and the PA keeps the band it had. Same when the HL2
  has not sent a frequency yet — it is not given a guessed default.
- **Keeps the PA on M while it is doing the selecting.** If the PA reports A it
  gets a `=Bn` for the band it is already on, which moves it to M and changes
  nothing else. Three attempts, then it gives up and says so, so a choice made
  at the front panel is not overridden for ever.
- **Polls every 500 ms** and publishes the 13 status fields into I2C registers.
- **Keeps the band it last set** when the host stops sending. There is no
  "connection lost" on this bus — a write to `REG_CONTROL` clears the frequency,
  and the PA is then left where it is rather than moved somewhere. Write
  `JUMA_CMD_AUTO_BAND` to hand band selection back to the PA.
- **Leaves OPERATE alone**, unless asked to hold it. Even then it will not
  argue with an alarm — a protective shutdown stays shut down until somebody
  clears it deliberately.

## I2C registers

The board's own registers are unchanged (see the
[HL2IOBoard README](https://github.com/jimahlstrom/HL2IOBoard#table-of-i2c-registers)).
This firmware adds a block at 0x40, clear of the upstream range, and defines
`REG_FAULT`. Names are in `juma_regs.h`. A read returns four bytes from the
address given, so related values sit next to each other.

| Reg | Name | |
|---|---|---|
| 0x40 | `REG_JUMA_MODE` | rw — standing behaviour, see below |
| 0x41 | `REG_JUMA_CMD` | rw — one-shot command, cleared once sent |
| 0x42 | `REG_JUMA_LINK` | 1 = the values below are fresh |
| 0x43 | `REG_JUMA_FLAGS` | state bits, see below |
| 0x44 | `REG_JUMA_BAND` | band the PA reports, 1 (160 m) … 9 (10 m), 10 = unknown |
| 0x45 | `REG_JUMA_WANT_BAND` | band this firmware wants, 0 = none or not covered |
| 0x46 | `REG_JUMA_GAIN` | attenuator 1…4 (G1 = 6 dB … G4 = 0 dB) |
| 0x47 | `REG_JUMA_ALARMS` | alarm bits as the PA reports them |
| 0x48 | `REG_JUMA_SWR` | VSWR × 10 — 14 is 1.4 |
| 0x49 | `REG_JUMA_VOLTS` | supply volts × 10 |
| 0x4A | `REG_JUMA_AMPS` | current, amps × 10 |
| 0x4B | `REG_JUMA_TEMP` | temperature, two's complement, scale per `FLAGS` bit 3 |
| 0x4C | `REG_JUMA_WATTS_MSB` | output power in watts, 16 bit |
| 0x4D | `REG_JUMA_WATTS_LSB` | |
| 0x4E | `REG_JUMA_FAN` | 0 off, 1 slow, 2 medium, 3 fast |
| 0x4F | `REG_JUMA_REPLIES` | status replies, low byte — counts up while the link lives |
| 0x50 | `REG_JUMA_BADLINES` | lines that were no status reply, low byte |
| 0x51 | `REG_JUMA_SET_GAIN` | rw — write 1…4 for `=Gn`, cleared once sent |
| 0x52 | `REG_JUMA_SET_BAND` | rw — write 1…9 for `=Bn`, cleared once sent; only while `NO_BAND` is set |
| 0x53 | `REG_JUMA_LOST` | bytes dropped by a full receive buffer, low byte |
| 0x54–0x55 | `REG_JUMA_VOLTS100_*` | supply volts × 100, 16 bit — for a display that wants 13.66 V, not 13.6 |
| 0x56–0x57 | `REG_JUMA_AMPS100_*` | current × 100, 16 bit |
| 0x58–0x59 | `REG_JUMA_WATTS10_*` | output power × 10, 16 bit |
| 0x5A–0x5B | `REG_JUMA_SWR100_*` | VSWR × 100, 16 bit |
| 0x5C | `REG_JUMA_BANNER_IDX` | rw — which character of the PA's power-up banner to look at; 0 asks for its length |
| 0x5D | `REG_JUMA_BANNER_CH` | that character, or the length at index 0 |
| 0x5F | `REG_JUMA_SNAP` | wo — write anything to take a snapshot, see below |
| 0x60–0x7B | snapshot | seven stamped groups of four, see below |

`REG_JUMA_MODE`, all bits clear at power-on and that is the intended normal
case:

| Bit | |
|---|---|
| 0 `JUMA_MODE_NO_BAND` | do **not** send `=Bn` on a frequency change |
| 1 `JUMA_MODE_HOLD_OPERATE` | put the PA back into OPERATE when it drops to STANDBY — three attempts, 5 s apart, never while an alarm is latched |
| 2 `JUMA_MODE_TELEMETRY` | one status line per second on the USB port, see below |
| 3 `JUMA_MODE_PROXY` | the USB port carries the PA's serial traffic verbatim |

`REG_JUMA_CMD` — write, and the firmware clears it once the command has gone
out to the PA. The two power-off codes sit far from the small numbers on
purpose, so a host walking through register values cannot switch the amplifier
off by accident.

| Code | | |
|---|---|---|
| 1 | `JUMA_CMD_OPERATE` | `=O` |
| 2 | `JUMA_CMD_STANDBY` | `=S`, and clears the OPERATE hold |
| 3 | `JUMA_CMD_AUTO_BAND` | `=A`, and sets `NO_BAND` — the PA selects for itself from here. Clear bit 0 of `REG_JUMA_MODE` to take over again |
| 4 | `JUMA_CMD_CLR_ALARM` | `=C` |
| 0xA0 | `JUMA_CMD_POWER_OFF` | `=P0` — switches the PA off, state discarded |
| 0xA1 | `JUMA_CMD_POWER_SAVE` | `=P1` — switches the PA off, state saved |

`REG_JUMA_FLAGS`: bit 0 OPERATE · 1 the PA selects bands itself · 2 the PA says
transmit · 3 temperature in °C, else °F · 4 band following is on · 5 EXTTR from
the HL2 says transmit.

`REG_JUMA_SET_BAND` is refused, with `JUMA_FAULT_BAD_CMD`, while band following
is on: a follower and a host both moving the filter would be a filter that moves
on its own. Switch `JUMA_MODE_NO_BAND` on first, then set the band.

`REG_FAULT` (register 8) as a bit field: bit 0 no status reply from the PA ·
1 an alarm is latched · 2 a register was written with a value it cannot take.

The measurements always hold the last values received, whether or not the link
is still alive. `REG_JUMA_LINK` is what says how far to trust them; a
`REG_JUMA_REPLIES` that has stopped counting is the other sign.

Alarm bits, from the PA: 0 high SWR · 1 over-current · 2 high temperature ·
3 high voltage · 4 low voltage pre-limit · 5 low voltage final limit.

## Being found by the SDR software

The board only follows the band if the SDR software sends it the transmit
frequency, and some software will not do that until it has recognised the
board. deskHPSDR looks for the PCA9536 at I2C **0x41** and expects four bytes
of `0xF1`; an N2ADR IO board answers that in hardware, with or without firmware
running. Failing that it reads **register 33** from the Pico at 0x1D and expects
**0xEF**, and that is the path for a board built without the PCA9536 — the
comment beside that code says it is there

> so you can use N2ADRs firmware code base for your own projects without buying
> the IO Board for the HL2

So this firmware answers register 33 with `0xEF`. On a real IO board it changes
nothing, because 0x41 has already done the job; it is there for the home-built
case. Register 34 is read afterwards as a low-pass filter bitmask and stays
zero, which deskHPSDR shows as "OFF". That is correct and not a gap: the
low-pass filter board is switched by the HL2's own gateware, and the board
documentation is explicit that "the IO board will not conflict with or control
the filter board". The Pico cannot read its state, so it reports none rather
than deriving a plausible-looking guess and passing it off as a measurement.

deskHPSDR also has **Radio → HL2 Force IO Board**, which skips detection
altogether.

### If the band does not follow

Check which frequency the software is actually sending. deskHPSDR sends
`vfo[txvfo]` — the **transmit** VFO, not the one being listened to. In split, or
after changing band on the receiving VFO alone, the transmit frequency does not
move, so neither does the filter, and everything downstream is behaving
correctly while appearing not to.

That is worth knowing before suspecting anything else: it cost an evening here.
The register held one unchanging value through 150 s of watching with not a
single failed read, and the reason was on screen the whole time — 14.074 above,
7.170 below.

## Never two commands in a row

This is the one thing to know about the HL2's I2C bridge, and it cost two days
to find: **commands sent back to back stop it.** Not too many commands — too
close together.

Measured with `tools/stress_bridge.py`, same 26 commands a second both times,
one variable changed:

| Shape | Result |
|---|---|
| one at a time | 30 minutes, **47 355 commands**, not a blink |
| bursts of 24 | dead after **19 454 commands**, 15.3 minutes |

When it goes, it goes completely: SDA is held low, no register write arrives,
and the bridge stops answering on **both** command addresses — `0x3d` for the
expansion bus and `0x3c` for the internal clock bus. So it is not the
`i2c_bus2` state machine, it is the command path itself. The radio still answers
discovery, so from the network it looks alive.

Nothing gets it back but a power cycle of the radio. Clocking the bus free from
the Pico does release SDA — the firmware does this, and `rec=` in the telemetry
counts it — but the master never resumes, and SDA is pulled down again within
the minute. It was tried, it is measured, and it is not a cure.

What this means for anything talking to the board:

- **A window polls with one command per tick.** `Hl2Link.poll()` advances a
  snapshot by exactly one command and hands back a reading when a whole set has
  arrived; `juma_gui.py` ticks it every 150 ms.
- **A script that needs an answer now pays for it in time.** `read_status()`
  drives `poll()` with `Hl2Link.PACE` between commands and takes about a second.
  `alive()` is one command, for the common case of only wanting to know whether
  the radio is there.
- **Nothing in `juma_link.py` sends two in a row any more**, including the paths
  that used to: the old register-by-register read, the banner reader, and the
  connection check that ran on every start.

It also explains the earlier history here. A window polling in bursts of eight
killed the bus in 31 minutes; the same window at one command per 150 ms ran for
6 h 33 before the last bursts left in it — a connect-time snapshot — caught up
with it.

## One program at a time on the bridge

The HL2's I2C bridge serves one caller. While SDR software holds the radio's
data stream, a second program gets no answers at all: discovery still works,
`ping` still works, and every command packet goes unanswered. The same applies
between two copies of the window, or a window and a script.

That is a property of the radio, not of this firmware, and it has a practical
consequence worth stating plainly: **the band switching does not depend on any
of it.** The firmware follows the frequency, holds OPERATE and handles alarms
on its own, with no host involved. What the bridge is needed for is watching and
hand control — and while the radio is transmitting for somebody else, that has
to go over the Pico's USB port instead. The window says so when it happens,
rather than showing a timeout.

## Reading it without being lied to

The HL2's I2C bridge drops a command that arrives while it is busy. The gateware
says so plainly — `i2c_bus2.v`, `// Missed` — and then `cmd_resp_data` still holds
the **previous** read's four bytes. Worse, `hermeslite_core.v` does not even wire
up the bridge's acknowledge line (`.cmd_ack() // No need for ack`), so the host
has no way of being told.

Measured against a real HL2: about **one round in 25** came back shifted. A
temperature that was really a reply counter, an alarm that was really a band
number. Waiting longer does not help — 0.2 s gave one bad round in 25, 0.35 s
gave none, 0.5 s gave one again. The drops are random, not a timing threshold.

So the data carries its own proof. Write anything to `REG_JUMA_SNAP`; the
firmware copies the current values into seven groups of four and stamps each
group's first byte with

```
stamp = (generation << 3) | group number
```

The host reads the groups and checks that every one carries its own number, that
all generations agree, and that the generation has moved on since last time.
Both halves are needed: the generation catches a group left over from an earlier
snapshot, the group number catches a dropped read handing back a *different*
group of the same snapshot — which a single shared tag would wave through. That
was not theory; the first design had one tag and a test with simulated drops
caught it.

| Group | | | |
|---|---|---|---|
| 0x60 | stamp | link | flags | band |
| 0x64 | stamp | want band | gain | alarms |
| 0x68 | stamp | volts ×100 MSB | LSB | temp |
| 0x6C | stamp | amps ×100 MSB | LSB | fan |
| 0x70 | stamp | watts ×10 MSB | LSB | mode |
| 0x74 | stamp | VSWR ×100 MSB | LSB | fault |
| 0x78 | stamp | replies | bad lines | lost bytes |

Payloads are written before the stamps. The I2C interrupt can serve a read in
the middle of that, and then the group still carries its old stamp — which is
exactly the mismatch the host is watching for. The other way round would hand
out a group that looks coherent and is not.

`hl2io/tools/juma_link.py` does the checking and reads again on a mismatch.

Over an hour of continuous use: **3152 rounds, 97 of them retried** — 3.1 %,
which agrees with the one-in-25 seen in the short runs, and not one wrong value
reached the display. Under a simulated one-in-40 drop rate the tests deliver 25
of 25 rounds with none wrong, and under one-in-2 they report failure rather than
guessing.

The same hour is worth reading for what it says about the *other* link: **not a
single unparseable line from the PA and not a single lost byte**, at 115200 over
a shifter wired straight to the Pico's pins. The divider that would have sat in
that path is discussed under the wiring, and this is the measurement that says
avoiding it was worth the two extra wires.

## The one rule this firmware has to keep

**Never disable interrupts, and never write flash.**

The Pico is an I2C **slave** on the radio's expansion bus. A slave that cannot
answer in time does not simply fall behind — the hardware pulls SCL low and
holds it, which is exactly what I2C asks it to do. It means "wait", and the
master must. The line comes back up when the interrupt handler runs.

So anything that keeps that handler from running hands the whole bus a brake:

    save_and_disable_interrupts()   flash_range_erase()   flash_range_program()
    critical sections, long ISRs, anything busy-waiting with interrupts masked

And the master on the other end has nothing to get out with. The gateware drops
whatever arrives while it is busy (`i2c_bus2.v`, `// Missed`), does not even wire
up the bridge's acknowledge line (`hermeslite_core.v`, `.cmd_ack() // No need for
ack`), and has neither a timeout nor a bus recovery. Measured here: once that
master stops, it stays stopped for **hours** — 7.7 of them in one case — and only
a power cycle of the radio brings it back. The filter board sits on the same bus
with its own address, so its relays stop switching too. From the outside the
whole radio looks broken.

A flash write cost tens of milliseconds of that, which is why the mode is no
longer kept (below). As of this writing the firmware holds the rule: `sleep_ms(1)`
paces the loop and nothing masks an interrupt anywhere. `printf` to the USB port
can block the main loop for up to 10 ms, but interrupts stay on and the I2C
handler keeps running, so that is fine.

Worth checking before adding anything that touches flash, timing or a critical
section:

    grep -n 'save_and_disable_interrupts\|critical_section\|flash_range' main.cpp

Empty is the correct answer.

## The mode is not kept

`REG_JUMA_MODE` comes up as the compiled `JUMA_MODE_AT_BOOT` and stays in RAM. A
host that wants something else writes it after every start; a host reset
(`REG_CONTROL` = 1) puts the compiled value back.

It used to be written to the last flash sector, and that is out for one reason:
an erase runs with interrupts off for tens of milliseconds, and during that the
Pico cannot serve its I2C slave, so the RP2040 holds SCL low. The HL2's master
has no timeout and no bus recovery — `i2c_bus2.v`, and `hermeslite_core.v` does
not even wire up the acknowledge line — and the filter board sits on that same
expansion bus with its own address (`HL2IOBoard/README.md`: the Pico's 0x1D is
"distinct from the filter board I2C address"). One erase in the wrong moment can
take the whole bus down, filter relays included. Seen here: nothing on the
expansion bus answered any more, and only a power cycle of the HL2 brought it
back - the SDR software, the Pico and the PA were all innocent and all looked
guilty.

A mode that survives a power cycle is a convenience. A wedged I2C bus costs the
station. So the OPERATE hold, the proxy and the telemetry feed are build options
again, or something the host sets each time.

## Telemetry on the USB port

With `JUMA_MODE_TELEMETRY` set — by `cmake -DJUMA_TELEMETRY=ON ..`, or over I2C
at any time, in any image — the firmware puts one line per second on the USB
serial port:

```
JUMA up=312 link=1 mode=06 fault=00 want=5 rep=624 bad=0 lost=0 wr=91 idle=0 sda=1 scl=1 slow=0 clow=0 rec=0 raw=O:A:T:C:5:1:1.0:14.09:8.1:27.2:26:0:0
```

Space separated `key=value`, so a program reads it with a `split()`. The fields
before `raw=` are the firmware's own view:

| | |
|---|---|
| `up` | seconds since the board started |
| `link` | 1 while the status is fresh |
| `mode` | `REG_JUMA_MODE`, hex |
| `fault` | `REG_FAULT`, hex |
| `want` | the band the firmware wants, 0 = none or not covered |
| `rep` | status replies received |
| `bad` | lines that were no status reply |
| `lost` | bytes dropped by a full receive buffer |

Everything after `raw=` is **the PA's own status line**, with the blanks taken
out and nothing else changed. No value is rescaled on the way, so nothing is
lost to rounding — and it can be fed straight back into `jumaParseStatus()`, the
same parser both firmwares here use. `tests/run.sh` checks that removing the
blanks changes none of the 13 fields.

A consumer in Python is then about four lines:

```python
import serial
pa = serial.Serial('/dev/ttyACM0')
for line in pa:
    if line.startswith(b'JUMA '):
        f = dict(kv.split(b'=', 1) for kv in line.split()[1:])
        print(f[b'raw'].split(b':'))      # the 13 fields, as the PA sent them
```

USB CDC ignores the baud rate. The write blocks while a host is attached but not
reading, so this build lowers `PICO_STDIO_USB_STDOUT_TIMEOUT_US` from its default
500 ms to **10 ms**: a stalled reader loses output rather than costing the PA its
remote mode.

### Controlling it from the PC

The same three-line loop can go the other way. The SDR software already reaches
the board through the HL2's I2C bridge — that is how the transmit frequency
arrives — so anything that can speak to the HL2 (Steve's `hermeslite.py` and the
like) can write these registers too:

| Want to | Write |
|---|---|
| OPERATE / STANDBY | `REG_JUMA_CMD` = 1 / 2 |
| clear an alarm | `REG_JUMA_CMD` = 4 |
| hand band selection back to the PA | `REG_JUMA_CMD` = 3 |
| set the attenuator | `REG_JUMA_SET_GAIN` = 1…4 |
| pick a band by hand | `REG_JUMA_MODE` bit 0, then `REG_JUMA_SET_BAND` |
| hold OPERATE, switch the feed on | `REG_JUMA_MODE` = 0x02 / 0x04 |

Reading back is a single I2C read from 0x42 onward — four registers at a time,
which is why values that belong together sit next to each other.

`hl2io/tools/` has that written already.

| | |
|---|---|
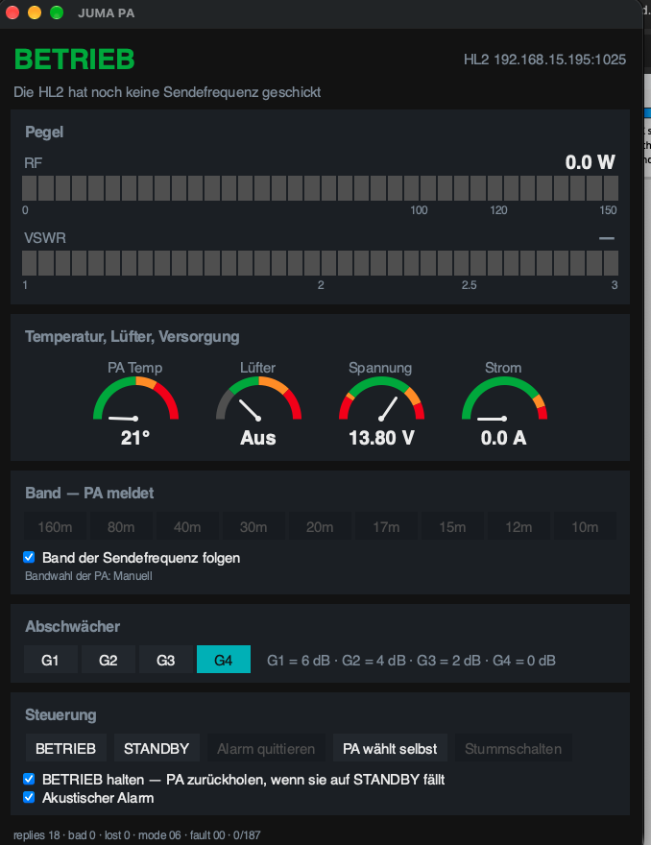
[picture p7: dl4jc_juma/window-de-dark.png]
German, dark
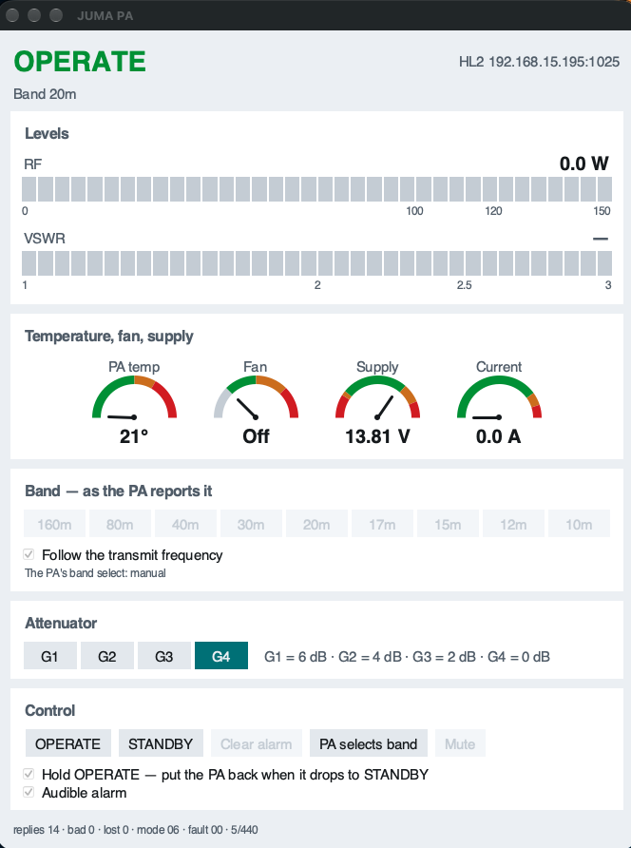
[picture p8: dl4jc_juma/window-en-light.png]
English, light
|  |  |

| | |
|---|---|
| `juma_gui.py` | the window above |
| `juma_link.py` | both routes behind one interface — `Hl2Link` over the HL2's I2C bridge (standard library only), `UsbLink` over the Pico (pyserial) |
| `juma_config.py` | remembers the connection, the language and the theme |
| `juma_theme.py` | the palettes, wording and the two meter widgets |
| `test_juma_link.py` | 44 checks against a fake HL2 and a fake Pico, no hardware needed |
| `make_icon.py` | draws the icon into every shape the three systems want |
| `make_app.py` | packs it into something you can double-click |

```sh
python3 hl2io/tools/juma_gui.py                     # find the HL2 on the network
python3 hl2io/tools/juma_gui.py --hl2 192.168.1.50
python3 hl2io/tools/juma_gui.py --usb /dev/cu.usbmodem11433301
```

Started with no arguments it tries, in order: what worked last time, a
broadcast, a knock on every address of the local /24, and then it asks. Several
radios are told apart by the MAC and gateware version out of their discovery
reply and offered as a list — picking the first of two would be picking at
random.

The colours, the zone boundaries and the wording are the ESP32 dashboard's, not
new ones: the same amplifier should not need a second set of colours learned.
German and English, light and dark, an alarm banner with a tone that repeats
every 5 s until it is silenced or the alarm goes.

### One click

```sh
cd hl2io/tools
python3 -m venv .venv
.venv/bin/pip install pyinstaller pyserial
.venv/bin/python make_app.py
```

Gives a `JUMA PA.app` on macOS, a folder with an `install.sh` for the
application menu on Linux, and a folder with a shortcut script on Windows.
PyInstaller does not cross-compile, so each is built on its own system —
`.github/workflows/juma-pa-app.yml` does all three on GitHub runners.

About 28 MB, because it carries its own Python and Tk. A shell script pointing
at the system Python would have been 316 kB and was tried first; it fails on
macOS for two reasons. The permission for the local network is tied to the
signed executable, and in a script bundle that is `python3`, not the
application — so it never appears under Privacy & Security and is never asked
about. And the Python it finds may be Apple's, with the Tk 8.5 that cannot draw
the window.

Started from an icon there is no terminal, so the window keeps a log:
`~/Library/Logs/JUMA-PA.log` on macOS, `~/.local/state/juma-pa.log` on Linux,
`%LOCALAPPDATA%\JUMA PA\juma-pa.log` on Windows. It names the Python and Tk
version, every connection attempt, and any exception with its traceback. Two
bugs in this code were found that way and no other.

The HL2 route reaches the Pico with command address **0x3d**, which the gateware
routes to the expansion I2C bus (`i2c_bus2.v`: `en_i2c2_next = cmd_addr ==
6'h3d`); 0x3c would be the internal clock bus. The device byte is `0x80 | 0x1D`,
the 0x80 telling the HL2 to finish with a stop. A read returns four bytes, the
first in `response_data` bits 7:0.

Which route to prefer: **USB** conflicts with nothing and carries the PA's own
status line, so the readings keep their full precision instead of the registers'
tenths. The **HL2** route needs no second cable, but its command packets go to
the same port the SDR software uses — expect the odd missed answer while the
radio is streaming.

## Notes

- The JUMA's serial port runs at **115200 8N1**, not the 19200 the SPE and
  Hardrock firmwares use.
- The line terminator is `\n\r` — LF before CR. On a PA-100D the replies
  measure three terminator bytes, `0D 0A 0D`; every CR and LF ends a line here
  and empty lines are dropped, so the surplus byte does not matter.
- Status field 13 is **hexadecimal**. Read as decimal it decodes wrongly from
  `0x0A` on. `tests/run.sh` in this repository checks exactly that.
- There is no inverted-TTL shortcut as there is in the ESP32 build: the RP2040
  UART cannot invert its signals, so the MAX3232 is not optional.
- The full protocol description is in the
  [main README](../../README.md#the-pas-protocol).

## Questions

For the board, the [Hermes-Lite group](https://groups.google.com/g/hermes-lite).
For the JUMA side, the issues of this repository.

Written by **DL4JC**, <mail@dl4jc.de>, on a PA-100D and a Hermes Lite 2.
---

## Where the parser and the band table came from

`juma_status.*` and `bands.*` started life in an ESP32 firmware for the same
amplifier and are free of Arduino, so they came across unchanged. They belong to
this project now and are edited here like everything else; `tests/run.sh` covers
them on the host, no hardware needed.

One thing worth knowing before touching a band edge: they describe the
**amplifier**, not this board, so the other controller carries the same table. A
correction made in only one of them leaves the two disagreeing about what band
the PA is on. Nothing checks that for you.

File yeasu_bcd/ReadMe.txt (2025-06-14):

This folder and software is an adaptation of software written by Jim Ahlstrom, N2ADR
for the Hermes Lite 2 IO board designed by Jim Ahlstrom, N2DDR.
Both are Copyright (c) 2022-2023 James C. Ahlstrom <jahlstr@gmail.com>.
And is licensed under the MIT license. See MIT.txt.

This adaptation is written by Dalton Williams, W5EIM to output BCD band code data
from the Hermes Lite 2 IO board to control amplifiers or tuners using the Yaesu
BCD band code protocol.

You should review the main.c file to understand how it works. Some knowledge of C++
is helpful but the code is well documented and explains how the BCD code is created.

The output is found on the J4 solder pads as follows:
     BCD Code A is on the J4 Pad 1 
     BCD Code B is on the J4 Pad 2 
     BCD Code C is on the J4 Pad 3 
     BCD Code D is on the J4 Pad 4
Solder jumper wires to the DB9 solder pads as appropriate for your equipment.

It is not necessary for you to compile the code.  You can simply copy the included
main.uf2 file to you IO board using these steps: 

     1. Power off the Hermes Lite 2 (HL2).
     2. Connect a USB cable to the I/O board's USB socket.
     3. Push and hold the button on the Pico microcontroller.
     4. Plug the USB cable into your PC while holding the Pico button. 
        The Pico will appear as a flash drive on your computer.
     5. Copy the main.uf2 file to the Pico drive.
     6. The Pico will reboot automatically after the file transfer.
     7. The Pico's LED should flash slowly indicating it is running correctly.
     8. You can then safely unplug the USB cable.
     9. Power on the HL2. 

If you wish to make modifications to the code, I used a Raspberry Pi 5, Pico SDK 
and pico development environment.

A description on how-to setup the pi pico development environment on a Raspberry Pi is here:
https://learn.arm.com/learning-paths/embedded-and-microcontrollers/rpi_pico/sdk/

After downloading the install script, follow the "Raspberry PIOS" instructions.

After you have verified the installation you can execute the following:
wget https://github.com/jimahlstrom/HL2IOBoard/archive/refs/heads/main.zip

Unzip:
unzip main.zip

Rename folder:
mv HL2IOBoard-main HL2IOBoard

Goto the w5eim_bcd folder:
cd /HL2IOBoard/yeasu_bcd

Delete the build folder
Create a new empty build folder

Goto build folder:
cd /HL2IOBoard/yeasu_bcd/build

Build application:
cmake ..
make

Copy main.uf2 to pico: [instructions above]

If you need help you can contact me by looking up my email address on QRZ
Best Wishes and 73
Dalton W5EIM

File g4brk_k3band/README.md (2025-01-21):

# IO Board K3 Band Data Emulation by G4BRK

This firmware provides binary band data in Elecraft K3 format to the IO Board ACC connector (DB-9).

// Pin details and wiring:
// K3 signal  HL2 GPIO      HL2IO    HL2 ACC
// band0 out  GPIO16_Out1   J4  1    1
// band1 out  GPIO19_Out2   J4  2    2
// band2 out  GPIO20_Out3   J4  3    3
// band3 out  GPIO11_Out4   J4  4    4
// digout0    GPIO10_Out5   J6  5    5
// Keyout-lp  GPIO22_Out6   J6  6    6

## Getting Started

### Wire your IO board signals to the ACC connector

* Solder a jumper from GND      to J7 pin 1.        GND is available at test point G2 or at the SMA connector J9
* Solder a jumper from J4 pin 1 to J7 pin 2.
* Solder a jumper from J4 pin 2 to J7 pin 3.
* Solder a jumper from J4 pin 3 to J7 pin 4.
* Solder a jumper from J4 pin 4 to J7 pin 5.
* Solder a jumper from J6 pin 5 to J7 pin 6.
* Solder a jumper from J6 pin 6 to J7 pin 7.

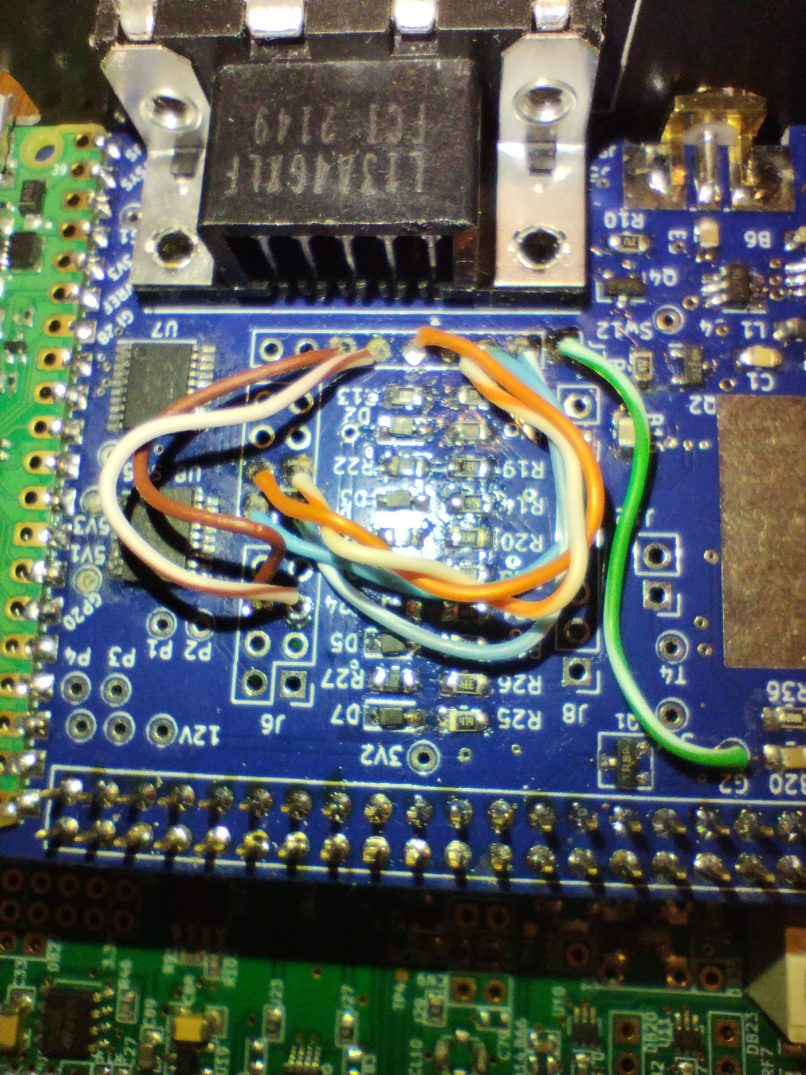
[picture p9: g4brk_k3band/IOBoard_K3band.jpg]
IO board wiring


### Install this firmware
* Power off the HL2 and connect a USB cable to the IO Board.
* Push the button on the Pico and then plug the USB cable into your PC.
* The Pico will appear as a flash drive on the PC. Then download the file [build/main.uf2](build/main.uf2) and copy it to the Pico.
* After the file is copied, the Pico will no longer show up as an external drive.
* Disconnect from the PC and power on the HL2.

For more detail, see the instructions in [Installing Firmware section of the main README](../README.md#installing-firmware).

### Wire up a cable

You need a DB-9 female connector to plug into the ACC socket. This differs from the K3 which needs a DB-15(HD) socket.  
A cable will need to be made up to suit your application.

## Operating 

Band data will be available on the ACC socket according to the TX frequency set in the SDR software.
This can be used to control an amplifier, select antenna by band, etc.

## Code modification

See [Installing Firmware section of the main README](../README.md#installing-firmware).

To debug using printf statements, install minicom, then connect to the pico using the
same USB lead as used for programming.

sudo apt install minicom

minicom -b 115200 -o -D /dev/ttyACM0

your tty port may vary!

## Questions?

Please post questions, issues, etc. to the [Hermes-Lite group](https://groups.google.com/g/hermes-lite).

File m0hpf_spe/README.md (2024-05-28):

# IO Board SPE Expert Amp Firmware by M0HPF

This firmware uses the SPE Expert amplifier serial interface(DB-15) to do band changes.
The firmware is inspired from the N1ADJ Hardrock-50 firmware.
The firmware requires a small pcb called Hw-027 which contains MAX3232 chip to convert TTL signal to RS232 signal and vice-versa so that the IO board firmware can communicate with SPE Expert Amp directly.

## Getting Started

### Wire your IO board for serial input/output
* Solder a jumper from J4 pin 1 to TTL-IN(i.e <- marked on TTL side of HW-027 board).
* Solder a jumper from J8 pin 1 to TTL-OUT(i.e -> marked on TTL side of HW-027 board).
* Solder a jumper from J12 pin 2 to Negative pin of HW-027 board on either RS232 side or TTL side.
* Solder a jumper from 5V1 of the IO Board to Positive pin of HW-027 board on either RS232 side or TTL side.
* Solder a jumper from RS232-Out(i.e <- marked on RTS232 side of HW-027 board) to J7 pin 2.  
* Solder a jumper from RS232-IN(i.e -> marked on RTS232 side of HW-027 board) to J7 pin 3.
* Solder a jumper from Negative pin of HW-027 board on either RS232 side or TTL side to J7 pin 5.

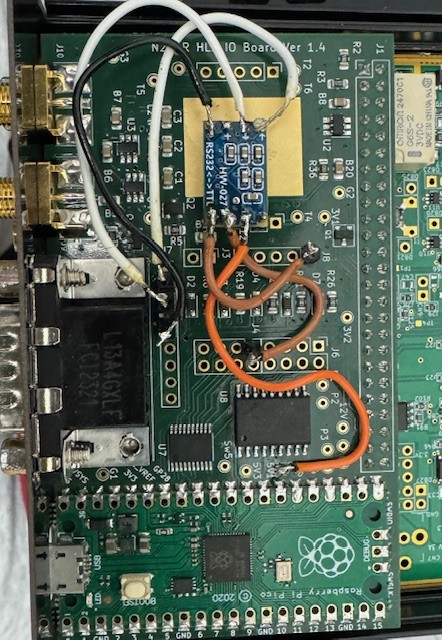
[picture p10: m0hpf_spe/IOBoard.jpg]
IO board wiring

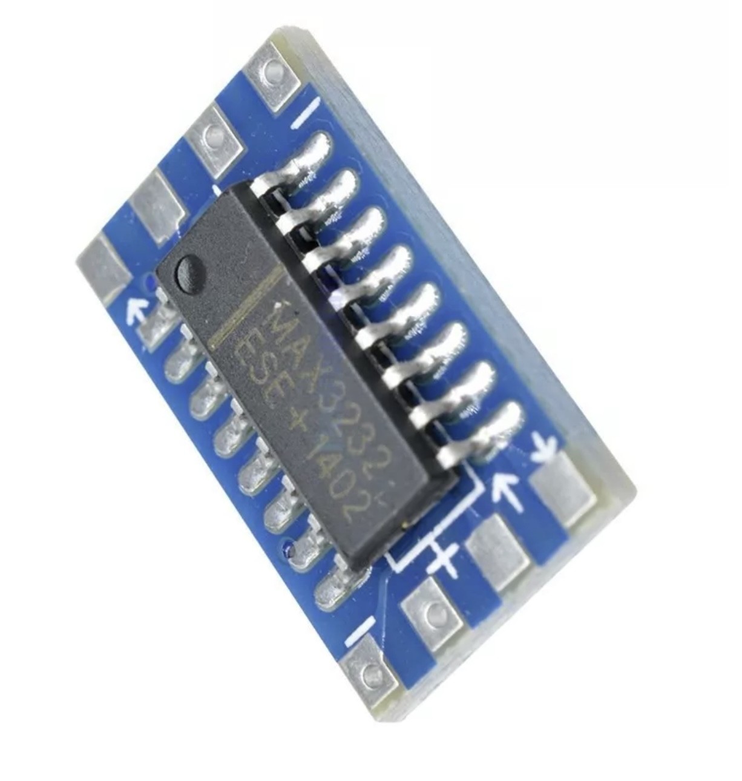
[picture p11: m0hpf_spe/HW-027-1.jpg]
HW-027 - 1

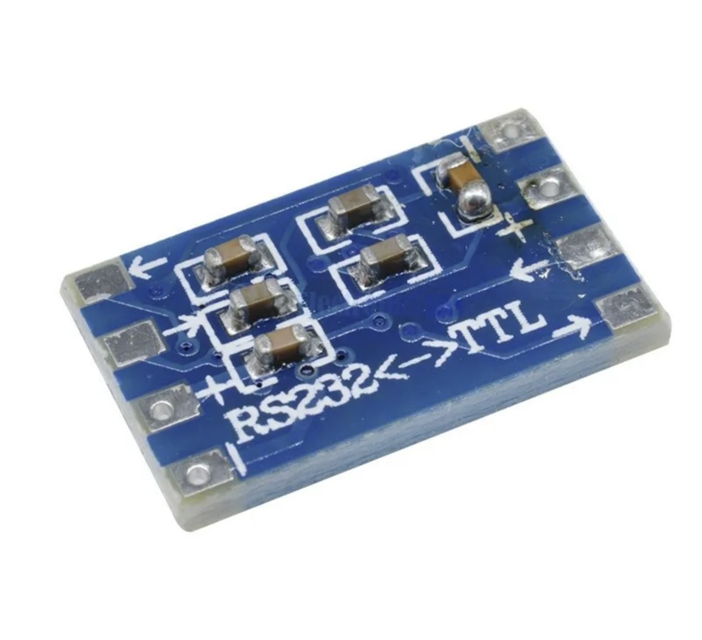
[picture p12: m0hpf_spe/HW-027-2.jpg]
HW-027 - 2


### Install this firmware
* Power off the HL2 and connect a USB cable to the IO Board.
* Push the button on the Pico and then plug the USB cable into your PC.
* The Pico will appear as a flash drive on the PC. Then download the file [build/main.uf2](build/main.uf2) and copy it to the Pico.
* After the file is copied, the Pico will no longer show up as an external drive.
* Disconnect from the PC and power on the HL2.

For more detail, see the instructions in [Installing Firmware section of the main README](../README.md#installing-firmware).

### Amplifier setup
The SPE amplifier CAT is set to either FLEX or YAESU [FTxxxx 2007+] and Baud rate to 19200.

### Wire up a cable
You need a DB-15 male to DB-9 female cable with tconnection as follows
* DB-15 pin 1 to DB-9 pin 2
* DB-15 pin 9 to DB-9 pin 3
* DB-15 pin 4 to DB-9 pin 5

If you are not building the cable you could use SPE Expert to Yaesu CAT control cable , essentially its the same pin connections mentioned in the manual of SPE Expert for interfacing Yaesu rigs. 

## Operating
Once the cable is hooked between the IO Board and the SPE Expert Amp, changing frequencies in SDR software that supports the IO Board should cause the amplifier to change bands. As you switch band in your software either Thetis or piHPSDR (latest compile from source), you should see the amplifier change bands as well.

## Questions?
Please post questions, issues, etc. to the [Hermes-Lite group](https://groups.google.com/g/hermes-lite).

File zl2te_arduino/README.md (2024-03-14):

# Arduino code conversion from Pico SDK

This firmware is the modification of the original Pico SDK firmware so that it will compile and install from the Arduino IDE. It is assumed that the user will have the Pico extension to the Arduino environment installed and is familiar with how to compile and upload. If this is not the case, there is plenty of information available on the internet and I recommend that you set it up and become familiar with it before proceeding.

## The General Concept

Apart from the i2c_slave_handler.c there is very little to change in the code. The Arduino IDE adds all the .ino files in the sketchbook directory into a single file and builds that so it is simply a matter of changing the name of the files xxx.c to xxx.ino, commenting out the hl2ioboard.h and i2c_registers.h includes and placing these slightly modified files into the sketchbook folder. Full details follow:

## The firmware example used

This is almostidentical to that used by Jim N2ADR in his n2adr_test example and uses the same libraries. There is a slight difference where Jim only switches 3 filters to show how to do the operation whereas this Arduino example switches five filters.

### The hardware and wiring required

The filter to be switched is a 1 KW capable home brew filter built as an outboard unit with four of its possible six filters installed. Ten metres is covered with an external 10 metre roofing filter in line so the ten metre position is simply a bridge although the future plan is to build the filter into that position. The 160 metre filter is not installed. The relays are activated by grounding the matching pin on the DB_9M plug on the front of the filter. The DB_9M plug connects to the DB_9M plug on the N2ADR IO Board via a DB_9F to DB_9F cable which is broken by inserting a ULN2003 to isolate the Pico IO Board and provide the drive current for the filter switching relays.

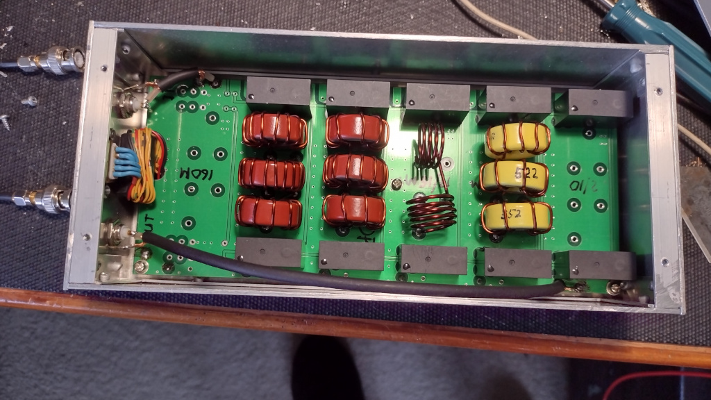
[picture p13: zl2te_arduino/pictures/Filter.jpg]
My outboard LP Filter


The picture below shows the DB9_F to DB9_F lead with the small cast aluminium box containing the ULN2003 and the 12 volt input which is used to power the filter switching relays in the filoter box. At present the I/O lines are connected one to one so each filter switch is driven by one output from J4 on the IO Board but my future plan is to use a 3 of 8 decoder to use 3 IO lines to switch up to 8 filters which will free up enough pins on J7 (the DB9 connector) to allow me to add facilities like RS232 output as well as tuner start and tune complete signals.

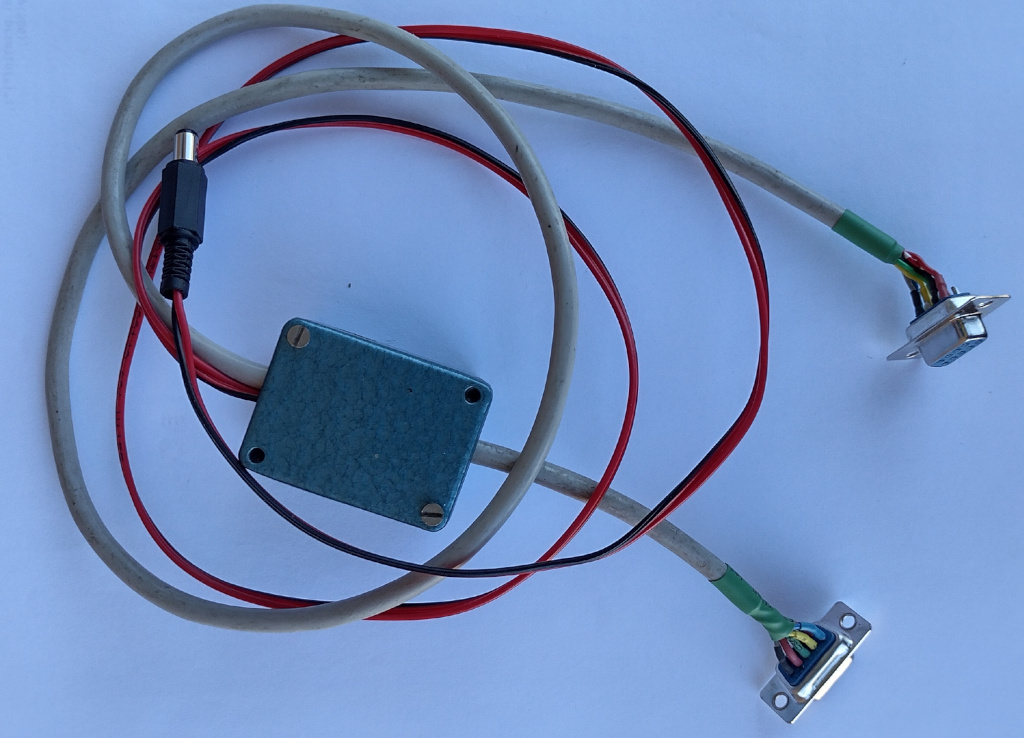
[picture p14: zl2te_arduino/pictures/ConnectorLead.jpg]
My Filter interconnecting Lead


### Wiring on the HL2IOBoard

As this board is highly experimantal I did not wish to hard wire the connections as these are expected to be altered several times while I test various scenarios so I elected to solder low profile header sockets into J4 and J7 (the DB9 connector) and joined them with short jumpers cut from the matching pin headers. I am using the 50mm case for my HL2 installation which gives me plenty of room above the HL2 IO Board for clearance of the headers. Shown below is a view of the board showing the header setup.

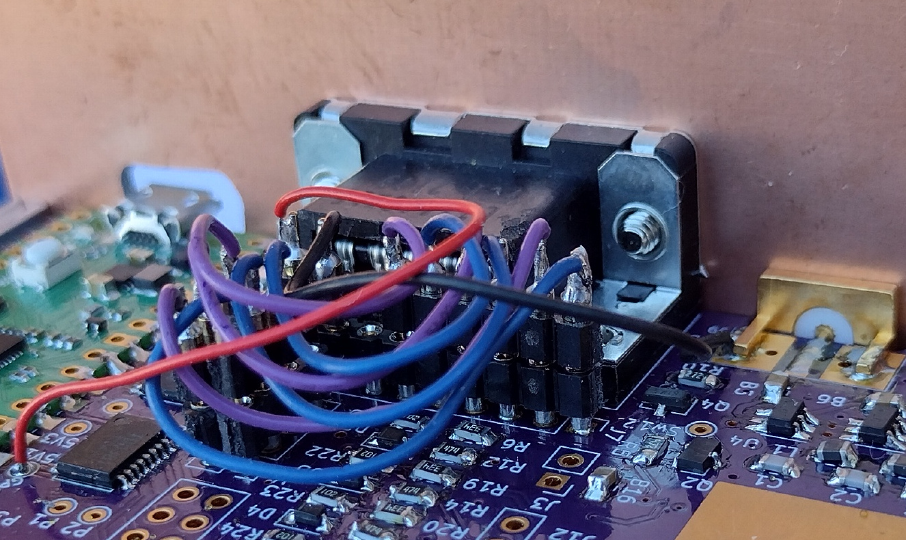
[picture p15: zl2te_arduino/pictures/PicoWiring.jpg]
My HL2IOBoard inter-wiring


Using the header pin jumpers:
* jumper from J4 pin 1 to J7 pin 1.
* jumper from J4 pin 2 to J7 pin 2.
* jumper from J4 pin 3 to J7 pin 3.
* jumper from J4 pin 4 to J7 pin 4.
* jumper from J4 pin 5 to J7 pin 5.
* jumper from J4 pin 6 to J7 pin 6.
* Solder a wire from +5V on the Pico board to J7 pin 9. (Not used in this case but done to provide 5 volts to peripherals in future experiments)

:warning: Note:

I have used J4 pin 6 for filter switching. This had been previously assigned to the IcomAh4 START line. To avoid a clash, the IcomAh4 START line has now been assigned to GPIO09_Out7.

## Converting the files:

It is a Quirk of the Arduino IDE that software must be compiled from a folder within the sketchbook directory and that the "main" code name must be the same as this directory within the sketchbook directory so in this case I have Jim's n2adr_basic/main.c file to my zl2te_arduino directory and renamed it to zl2te_arduino.ino - Note that all .c or .cpp files are renamed to .ino for the Arduino IDE environment.

### Included files:

The CMakeLists.txt files tell the SDK compiler which files to include and also references the library files. The ones used in the n2adr_basic example are ...
* main.c
* hl2ioboard.h
* i2cregisters.h
and from the library:
* configure_pins.c
* led_flasher.c
* i2c_slave_handler.c
* ft817_band_volts.c
* icom_ah4.c
* frequency_code.c
* fcode2bcode.c

In the arduino IDE, rather than having a C Make List file you simply place the files to be used into the sketchbook sub directory that you have created for the project and at compile time they will be picked up by the compiler and compiled as though they were a single file. This means that many #include s will be redundant and are best commented out or deleted and I will go through this file by file as this document proceeds. The final file list in the sketchbook sub directory will be like this ...

* main.c                  becomes	 zl2te_arduino.ino
* hl2ioboard.h            remains	 hl2ioboard.h
* i2cregisters.h          remains	 i2cregisters.h
* configure_pins.c        becomes	 configure_pins.c
* fcode2bcode.c           becomes	 fcode2bcode.c
* frequency_code.c        becomes	 frequency_code.c
* ft817_band_volts.c      becomes	 ft817_band_volts.c
* i2c_slave_handler.c     becomes	 i2c_slave_handler.c
* icom_ah4.c              becomes	 icom_ah4.c
* led_flasher.c           becomes	 led_flasher.c

The picture below shows how this file arrangement will appear in the Arduino IDE

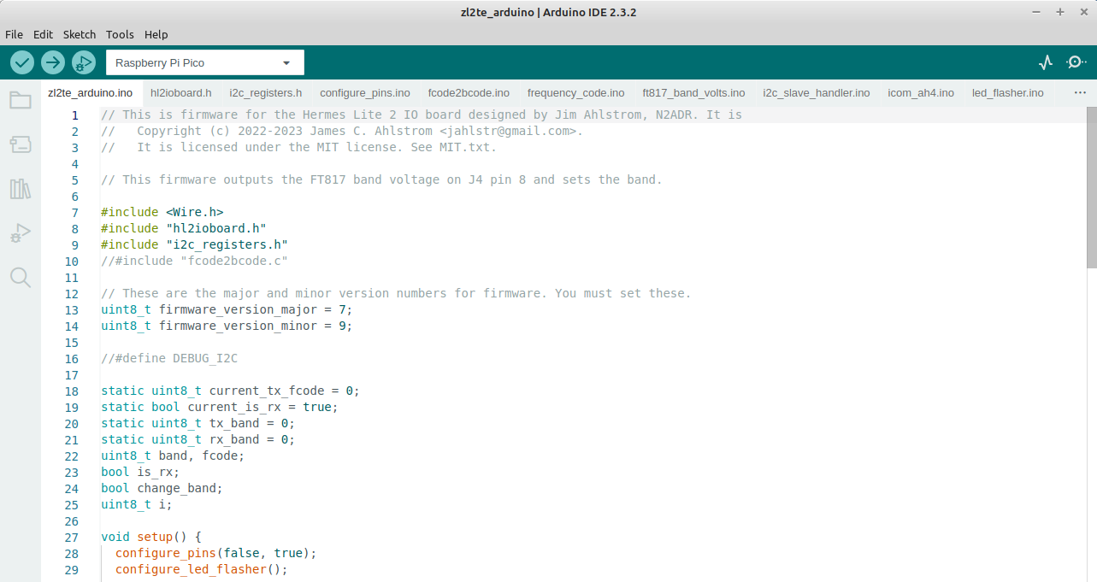
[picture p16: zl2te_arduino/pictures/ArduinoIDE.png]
Arduino IDE source files


### Changes to the source files
#### 1. zl2te_arduino.ino (was old main.c)
This file has the most extensive changes in function as the Pico SDK I2C functions are completely replaced by the wire library which needs to be included and its callback functions declared but in terms of lines of code it is fairly minimal. It works pretty much the same as the SDK except that the events and their stop procedures are more transparent with the wire library handling all this.
No changes to the functionality of main.c were made in the zl2te_arduino.ino code but some re arranging to accomodate using the wire library and the format that Arduino IDE uses for its layout took place.
For the Arduino IDE the format of the code is like this:
<pre>
#includes and globals

void setup() {
  // put your setup code here, to run once:
}

void loop() {
  // put your main code here, to run repeatedly:
}
</pre>
In the global space wire.h was added
#include <Wire.h>
and a debug was created to monitor the traffic on the I2C port to the HL2 which can be commented out on the final compile. All the debug stuff is enclosed in #ifdef's and is in addition to Jim's main.c code.

All the initialisation code was shifted into the "void setup()" space but is mostly unchanged from the original. stdio is not used as the Arduino IDE has built in print functions etc. and the wire library needs to be invoked along with the function callbacks to deal with the i2c traffic.

The running code that is contained in the "while (1) {	// Wait for something to happen" statement is shifted into the "void loop() {" procedure in the Arduino IDE and is unchanged from the original apart from the fact that I have expanded the "switch (band) {  // Set some GPIO pins according to the band" statement to accomodate 6 bands for my purposes rather than the original 3 bands that Jim used in his example.

#### 2.hl2ioboard.h
Changes were quite minimal here and simply consisted of commenting out 3 lines associated with the Pico SDK i2c handling which has been replaced by the Arduino IDE wire library. I have also declared a 30 character buffer to hold my debug messages which probably shouild have been enclosed in an #ifdef DEBUG_I2C

#### 3. i2c_registers.h
No changes occurred in this file

#### 4. configure_pins.ino
The only changes in this file are for the conversion of Pico SDK i2c initialisation where lines 16 & 17 are changed:<br/>
<pre>
from
    gpio_init(GPIO14_I2C1_SDA);	gpio_set_function(GPIO14_I2C1_SDA, GPIO_FUNC_I2C);
    gpio_init(GPIO15_I2C1_SCL);	gpio_set_function(GPIO15_I2C1_SCL, GPIO_FUNC_I2C);
to
    Wire1.setSDA(GPIO14_I2C1_SDA);
    Wire1.setSCL(GPIO15_I2C1_SCL);
and lines 18 & 19 are commented out
    // i2c_init(i2c1, I2C1_BAUDRATE);
    // i2c_slave_init(i2c1, I2C1_ADDRESS, &i2c_slave_handler);
</pre>
#### 5. fcode2bcode.ino
Simply commenting out the redundant #include "hl2ioboard.h" in line 8 is all that is required here.

#### 6. frequency_code.ino
No changes to this file at all.

#### 7. ft817_band_volts.ino
Commenting out #include "hl2ioboard.h" and #include "i2c_registers.h" in lines 8 & 9 is all that is required on this file.

#### 8. i2c_slave_handler.ino
This file is the most complex as it receives the i2c signals and processes them. The original SDK code used the raw data from i2c interrupts which are hidden in the wire library and requires some code changes.

The first signal sent in from the i2c master (the HL2) to the slave (IO Board) is an event to describe what kind of event it is which is processed in a switch ... case statement as in this psuedo code ...
<pre>
switch (event) {
    case I2C_SLAVE_RECEIVE: // master has written data and this slave receives it
        Process this data;
    case I2C_SLAVE_REQUEST: // master is requesting data
        Process this data;
    case I2C_SLAVE_FINISH: // master has signalled Stop or Restart
        Stop the I2C_SLAVE_RECEIVE or I2C_SLAVE_REQUEST procedure
</pre>
The above code is handled by callback functions declared in zl2te_arduino.ino as "receiveEvent" and "requestEvent" and these replace I2C_SLAVE_RECEIVE and I2C_SLAVE_REQUEST respectively. There is no need to handle I2C_SLAVE_FINISH as this is built into the wire library.

The code inside the "receiveEvent" callback function handles the incoming data from the HL2 i2c master a little differently from the I2C_SLAVE_RECEIVE which handles each incoming byte one by one whereas the wire library keeps reading data in a stream until the (hidden) stop is sent. This requires a buffer to hold the stream which is declared as "uint8_t inward[6];". The first character received into the buffer will be the Control Register and subsequent bytes, the data to be processed referred to the control register. The HL2 master will only send either one or two bytes with the first byte being the control register and if there is a second byte, the data. In the case of a single byte, the control register is being nominated for a "requestEvent" and the callback can be terminated at that point. The receiveEvent also receives a byte count of the bytes being sent from the master and this can be used to discriminate between a receiveEvent requiring further processing and setting a the control register for a requestEvent. The "inward[6]" buffer really only needs to be 3 bytes long but when experimenting initially I made the buffer bigger in case the HL2 was sending control register plus 4 data bytes which is not the case but I left the buffer size at 6 as memory is not an issue with the Pico.

In addition in the early stages I was debugging and created a buffer to hold the string sent from the HL2 and display it as the callback and the data received formatted as a decimal number. I have put all these in a #ifdef DEBUG_I2C to remove them on final compile by commenting out the line "#define DEBUG_I2C" in zl2te_arduino.ino in order to skip all this. You can remove all these statements from the code if you do not wish to have the debug facility available.

The callbacks process the commands from the HL2 in exactly the same manner as Jim does in his n2adr_basic software and there are no changes to the code around this.

#### 9. icom_ah4.ino
Commenting out #include "hl2ioboard.h" and #include "i2c_registers.h" in lines 13 & 14 is all that is required on this file.

#### 10. led_flasher.ino
Commenting out #include "hl2ioboard.h" on line 7 is the only change required on this file.

### Installing the firmware
The firmware needs to be compiled for a Raspberry Pi Pico in the Arduino IDE which means that the files used need to be in your sketchbook directory. The easiest way to achieve this is to clone the repository (git clone https://github.com/jimahlstrom/HL2IOBoard.git) into a suitable directory - maybe a "Programs" directory and copy the directory "zl2te_arduino" into your sketchbook. There is no need to stay with the name zl2te_arduino but if you change it then you need to rename the zl2te_arduino.ino to the same name as the parent directory.<br />
If you are a linux user, make sure that you are a member of the dialout and tty groups.

* Power off the HL2 and connect a USB cable to the IO Board.
* Plug the USB cable into your PC.
* The Pico will appear as a USB connection on the Arduino which needs to be selected as the port.
* Compile the code and check for errors and if clean upload. It should automatically make the Pico appear as a flash drive and upload the code but in some cases you may need to unplug the USB cable, push the button on the Pico and plug the cable back in.
* Disconnect from the PC and power on the HL2.

#### This is what a good compile looke like.
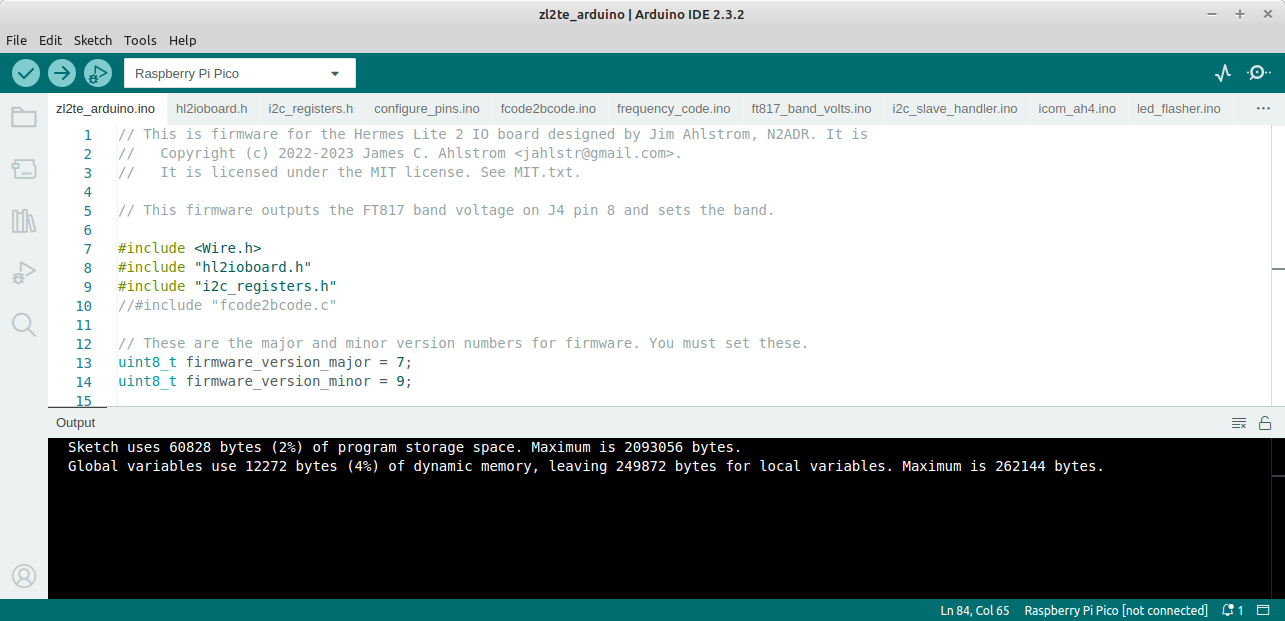
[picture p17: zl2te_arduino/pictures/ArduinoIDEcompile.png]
Arduino IDE good compile

### Post installation testing
Check that when switching bands the correct voltage occurs on the associated pin on J4. Yo can see from the code in the zl2te_arduino.ino file which pin belongs to which band. The same test can be applied to the band voltage on J4 pin 8. This will prove that everything is working and you can customize from there.

## Looking ahead
It is unlikely that the basic environment is what you will be looking for in your final installation but this at least is a foundation to build your code on. In my case I will be writing code to talk to my antenna tuner which at present has a single input line to prime it to start tuning on the arrival or more than 1 watt signal and when it has stopped tuning I stop the spot button. Very manual, so using the potential of the IO board I may send serial commands like frequency in use and receive back responses including the L and C used and tune finished. The potential is big here and I am looking at monitoring for my linear and perhaps sending data to an external application for remote access as I run my HL2 on remote mode all the time even on my home QTH

## Questions?

Please post questions, issues, etc. to the [Hermes-Lite group](https://groups.google.com/g/hermes-lite).

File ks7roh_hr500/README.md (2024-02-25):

# IO Board Hardrock-500 Firmware by KS7ROH

This firmware uses the [Hardrock-500](https://sites.google.com/site/hobbypcbhardrock500/hardrock-500-power-amplifier-project) amplifier serial interface to do band changes, facilitate PTT, and to trigger the built-in antenna tuner. The HR-500 serial protocol is described in Chapter 6 of the [Hardrock-500 Manual](https://drive.google.com/file/d/1avSVrf3zBE5ctz3W49rhoNwpsqH4gvXD/view). The IO Board antenna tuning protocol is described in the [main README](../README.md#table-of-i2c-registers).

This firmware is based on the work of N1ADJ and N2ADR. 

## Getting Started

### Wire your IO board for serial input/output and PTT

* Solder a jumper from J4 pin 1 to J7 pin 2.
* Solder a jumper from J8 pin 1 to J7 pin 3.
* Solder a jumper from J12 pin 2 to J7 pin 5.
* Solder a jumper from J6 pin 5 to J7 pin 4.

The Hardrock-50 shuts off its serial port while it's in transmit mode, which means there's no way to find out when it's done tuning. initially N1ADJ used a timed transmit approach, but that had to allow for the longest possible tune cycle, so the transmitter stayed on longer than necessay. On the HR-50 mailing list, Patrick AC1KM suggested that it might be possible to use the transmitter's SWR reporting to monitor tuning state and Jim N2ADR suggested wiring that makes that possible. with the following connections, the firmware can monitor forward and reverse power and detect when tuning is complete. The only downside is that there aren't dedicated pads on the board, so you have to solder directly to pins on the 50-pin header and the Pico daughterboard. If you don't feel comfortable doing that, you can omit those connections. Tuning will still work, but the transmitter will stay on for a fixed period rather than shutting off when SWR has stopped changing.

NOTE: The Hardrock-500 does not shut off its serial port when transmitting but the above method is still used to gauge the status of the tuner as it is very effective and the programming was already completed by N1ADJ.

### SWR monitoring connections

* Solder a jumper from J1 pin 37 to U1 pin 31.
* Solder a jumper from J1 pin 39 to U1 pin 32.

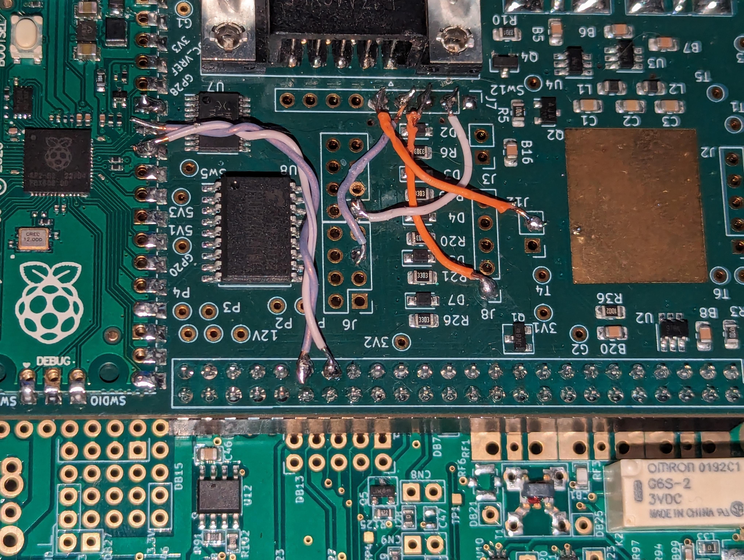
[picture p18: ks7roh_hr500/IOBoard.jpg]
IO board wiring


### Install this firmware
* Power off the HL2 and connect a USB cable to the IO Board.
* Push the button on the Pico and then plug the USB cable into your PC.
* The Pico will appear as a flash drive on the PC. Then download the file [build/main.uf2](build/main.uf2) and copy it to the Pico.
* After the file is copied, the Pico will no longer show up as an external drive.
* Disconnect from the PC and power on the HL2.

For more detail, see the instructions in [Installing Firmware section of the main README](../README.md#installing-firmware).

### Amplifier setup

In the amplifier setup menu, set option `4. Transceiver` to `None` and option `2. ACC Baud Rate` to 19200.

### Wire up a cable

You need a DB-9 male to DB-9 female cable with pins 2, 3, 4 and 5 connected straight through, that is pin 2 to pin 2, pin 3 to pin 3, pin 4 to pin 4, and pin 5 to pin 5.

## Operating

Once the cable is connected between the IO Board and the HR-500, changing frequencies in SDR software that supports the IO Board should cause the amplifier to change bands. As you switch band in your software, you should see the amplifier change bands as well. It does _not_ trigger the antenna tuner&mdash;you must do that manually if needed.

As far as I'm aware, the only software that implements the antenna tuning protocol is [Reid's HL2-specific Thetis fork](https://github.com/mi0bot/OpenHPSDR-Thetis/releases), starting in version v2.10.3.4-beta1. To trigger automatic tuning, click the `TUNE` button while pressing the `Ctrl` key. (Be sure the `Setup|General|Ant/Filters|Antenna|Disable on Tune Pwr <35W` box is checked, or transmit may stop before tuning is complete.)

## Questions?

Please post questions, issues, etc. to the [Hermes-Lite group](https://groups.google.com/g/hermes-lite).

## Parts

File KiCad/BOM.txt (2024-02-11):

Capacitor C4
Value 0.33u, 0805_2012Metric
Part Number AVX, 08055C334K4T2A
Substitute X7R, 10%, 16 V

Capacitor (18) B9 B1 B8 B7 B6 B10 B15 B17 B12 B5 B2 B11 B14 B16 B18 B21 B20 B19
Value 100n, 0805_2012Metric
Part Number AVX, 08055C104JAT2A
Substitute X7R 50 volt

Capacitor C1 C3
Value 1500p, 0805_2012Metric
Part Number AVX, 08055A152JAT2A
Substitute C0G 50 volt

Capacitor C2
Value 680p, 0805_2012Metric
Part Number AVX, 08055A681JAT2A
Substitute C0G 50 volt

Capacitor C5
Value 1u, 0805_2012Metric
Part Number AVX, 0805YC105KAT2A
Substitute X7R, 10%, 16 V

Connector J10 J9
Value 142-0701-851, BNCEDGE
Manufacturer Cinch
Substitute SMA end launch; consider panel mount

Connector J5
Value LD09P13A4GX00LF, DSUB-9 Male Horizontal
Manufacturer Amphenol

Connector J1
Value Conn_02x25_Odd_Even, Socket 2x25, 2.54 mm
55mm enclosure:	13.59 mm insulation height
		Oupiin 2047-2X25G00S3U
		Samtec ESW-125-48-G-D
40mm enclosure:	11.05 mm insulation height
		Oupiin 2047-2X25G00S1U
		Samtec ESW-125-12-G-D
Insulation height determines back panel hole height.

Diode D6
Value B0530WS-7-F, SOD-323
Manufacturer Diodes Incorporated
Substitute schottky rectifier, minimum 10 V, 300 ma

Diode D2 D3 D4 D5 D7 D1
Value RB751V40T1G, SOD-323
Manufacturer ON Semiconductor
Substitute schottky switching diode, low forward drop, low reverse leakage, minimum 20 V, 5 ma

IC U1
Value Pico, RPi_Pico_SMD_TH

IC U6
Value MC74HCT04ADR2G, SO-14_3.9x8.65mm_P1.27mm

IC U11
Value PCA9536DR, SOIC-8_3.9x4.9mm_P1.27mm

IC U9
Value LM4040DIM3X-3.0/NOPB, SOT-23

IC U2 U3 U4
Value MASWSS0179TR-3000, SOT-23-6

IC U13
Value TLV9351IDCKR, SOT-353_SC-70-5

IC U5
Value AS78L05RTR-E1, SOT-89-3
Substitute MC78L05ACHT1G or similar

IC U8
Value TBD62381AFWG,EL, SOIC-18 7.5mm wide

IC U7
Value 74HCT541PW,118, TSSOP-20_4.4x6.5mm_P0.65mm

Inductor L1 L2
Value 1.8u, 0805_2012Metric
Part Number TDK, MLF2012A1R8JT000
Substitute ferrite inductor low power, good Q

Resistor R7 R11 R33 R1 R34 R4 R35 R36
Value 10K, 0805_2012Metric
Part Number Yageo, RC0805JR-0710KL
Substitute resistor 5%

Resistor R8 R13 R22 R23 R24 R27 R28
Value 1K, 0805_2012Metric
Part Number Yageo, RC0805JR-071KL
Substitute resistor 5%

Resistor R32
Value 27K, 0805_2012Metric
Part Number Yageo, RC0805JR-0727KL
Substitute resistor 5%

Resistor R10 R29
Value 2K7, 0805_2012Metric
Part Number Yageo, RC0805JR-072K7L
Substitute resistor 5%

Resistor R6 R19 R20 R21 R26
Value 330K, 0805_2012Metric
Part Number Yageo, RC0805JR-07330KL
Substitute resistor 5%

Resistor R3
Value 470, 0805_2012Metric
Part Number Yageo, RC0805JR-07470RL
Substitute resistor 5%

Resistor R12 R14 R15 R16 R25
Value 470K, 0805_2012Metric
Part Number Yageo, RC0805JR-07470KL
Substitute resistor 5%

Resistor R5 R17 R18 R9 R30 R31
Value 4K7, 0805_2012Metric
Part Number Yageo, RC0805JR-074K7L
Substitute resistor 5%

Resistor R2
Value 51, 0805_2012Metric
Part Number Yageo, RC0805JR-0751RL
Substitute resistor 5%

Transistor Q4 Q5
Value BC847C-13-F, SOT-23
Manufacturer Diodes Incorporated
Substitute NPN, minimum 20 V, 10 ma

Transistor Q2 Q3
Value SSM3J374R,LF, SOT-23
Manufacturer Toshiba
Substitute MOSFET, P-ch, minimum 20 V, 300 ma

Transistor Q6
Value FCX491ATA, SOT-89-3
Manufacturer Diodes Incorporated
Substitute NPN, minimum 20 V, 300 ma

Transistor Q1
Value NUD3160LT1G, SOT23_3
Manufacturer On Semiconductor
Substitute DRDC3105F-7

Connectors J2, J3, J4, J6, J7, J8, J12
These pin headers are not installed.

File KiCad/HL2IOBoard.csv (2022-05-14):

Reference | Quantity | Value | Footprint | Datasheet | P/N
G1 P1 T1 G2 P2 T2 G3 P3 P4 T4 Sw5 T5 T6 Sw12 3V1 3V2 5V1 5V3 12V1 12V2 12V3 | 21 | TestPoint | TestPoint:TestPoint_THTPad_D1.5mm_Drill0.7mm | ~
B1 B2 B5 B6 B7 B8 B9 B10 B11 B12 B14 B15 B16 B17 B18 B19 B20 B21 | 18 | 100n | Capacitor_SMD:C_0805_2012Metric_Pad1.18x1.45mm_HandSolder | ~
C1 C2 C3 | 3 | 1500p | Capacitor_SMD:C_0805_2012Metric_Pad1.18x1.45mm_HandSolder | ~
C4 | 1 | 0.33u | Capacitor_SMD:C_0805_2012Metric_Pad1.18x1.45mm_HandSolder | ~ | 08055C333K4T2A
C5 | 1 | 1u | Capacitor_SMD:C_0805_2012Metric_Pad1.18x1.45mm_HandSolder | ~ | 0805YC105KAT2A
D1 D2 D3 D4 D5 D7 | 6 | RB751V40T1G | Diode_SMD:D_SOD-323_HandSoldering | www.st.com/resource/en/datasheet/bat48.pdf
D6 | 1 | B0530WS-7-F | Diode_SMD:D_SOD-323_HandSoldering | www.st.com/resource/en/datasheet/bat48.pdf
J1 | 1 | Conn_02x25_Odd_Even | Connector_PinHeader_2.54mm:PinHeader_2x25_P2.54mm_Vertical | ~ | 2047-2X25G00S3U
J9 J10 | 2 | 142-0701-871 | Local:BNCEDGE | ~
J12 | 1 | Conn_02x01 | Connector_PinHeader_2.54mm:PinHeader_1x02_P2.54mm_Vertical | ~ | DNI
J3 | 1 | FAN | Connector_PinHeader_2.54mm:PinHeader_1x02_P2.54mm_Vertical | ~ | DNI
J4 J6 | 2 | Conn_02x04_Odd_Even | Connector_PinHeader_2.54mm:PinHeader_2x04_P2.54mm_Vertical | ~ | DNI
J5 | 1 | LD09P13A4GX00LF | Connector_Dsub:DSUB-9_Male_Horizontal_P2.77x2.84mm_EdgePinOffset9.90mm_Housed_MountingHolesOffset11.32mm | ~
J7 | 1 | Conn_01x09 | Connector_PinHeader_2.54mm:PinHeader_1x09_P2.54mm_Vertical | ~ | DNI
J2 J8 | 2 | Conn_01x05 | Connector_PinHeader_2.54mm:PinHeader_1x05_P2.54mm_Vertical | ~ | DNI
L1 L2 | 2 | 1.8u | Inductor_SMD:L_0805_2012Metric_Pad1.15x1.40mm_HandSolder | ~ | LBM2016T1R8J
Q1 | 1 | NUD3160LT1G | hermeslite:SOT23_3
Q2 Q3 | 2 | SSM3J374R,LF | Package_TO_SOT_SMD:SOT-23 | https://www.infineon.com/dgdl/irlml6402pbf.pdf?fileId=5546d462533600a401535668d5c2263c
Q4 Q5 | 2 | BC847C-13-F | Package_TO_SOT_SMD:SOT-23 | http://www.infineon.com/dgdl/Infineon-BC847SERIES_BC848SERIES_BC849SERIES_BC850SERIES-DS-v01_01-en.pdf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
Q6 | 1 | FCX491ATA | Package_TO_SOT_SMD:SOT-89-3 | http://cache.nxp.com/documents/data_sheet/BCP56_BCX56_BC56PA.pdf?pspll=1
R10 R29 | 2 | 2K7 | Resistor_SMD:R_0805_2012Metric_Pad1.20x1.40mm_HandSolder | ~
R12 R14 R15 R16 R25 | 5 | 470K | Resistor_SMD:R_0805_2012Metric_Pad1.20x1.40mm_HandSolder | ~
R2 | 1 | 51 | Resistor_SMD:R_0805_2012Metric_Pad1.20x1.40mm_HandSolder | ~
R3 | 1 | 470 | Resistor_SMD:R_0805_2012Metric_Pad1.20x1.40mm_HandSolder | ~
R32 | 1 | 27K | Resistor_SMD:R_0805_2012Metric_Pad1.20x1.40mm_HandSolder | ~
R5 R9 R17 R18 R30 R31 | 6 | 4K7 | Resistor_SMD:R_0805_2012Metric_Pad1.20x1.40mm_HandSolder | ~
R6 R19 R20 R21 R26 | 5 | 330K | Resistor_SMD:R_0805_2012Metric_Pad1.20x1.40mm_HandSolder | ~
R1 R4 R7 R11 R33 R34 R35 R36 | 8 | 10K | Resistor_SMD:R_0805_2012Metric_Pad1.20x1.40mm_HandSolder | ~
R8 R13 R22 R23 R24 R27 R28 | 7 | 1K | Resistor_SMD:R_0805_2012Metric_Pad1.20x1.40mm_HandSolder | ~
U1 | 1 | Pico | Local:RPi_Pico_SMD_TH
U11 | 1 | PCA9536D | Package_SO:SOIC-8_3.9x4.9mm_P1.27mm | http://www.nxp.com/documents/data_sheet/PCA9536.pdf
U13 | 1 | TLV9351IDCKR | Package_TO_SOT_SMD:SOT-353_SC-70-5_Handsoldering | http://www.ti.com/lit/ds/symlink/lmv324.pdf
U2 U3 U4 | 3 | MASWSS0179TR-3000 | Package_TO_SOT_SMD:SOT-23-6_Handsoldering
U5 | 1 | AS78L05RTR-E1 | Package_TO_SOT_SMD:SOT-89-3_Handsoldering | https://www.onsemi.com/pub/Collateral/MC78M00-D.PDF
U6 | 1 | MC74HCT04ADR2G | Package_SO:SO-14_3.9x8.65mm_P1.27mm | http://www.ti.com/lit/gpn/sn74HC14
U7 | 1 | 74HCT541PW,118 | Package_SO:TSSOP-20_4.4x6.5mm_P0.65mm
U8 | 1 | TBD62381AFNG,EL | Package_SO:SSOP-18_4.4x6.5mm_P0.65mm
U9 | 1 | LM4040DIM3X-3.0/NOPB | Package_TO_SOT_SMD:SOT-23 | http://www.ti.com/lit/ds/symlink/lm4040-n.pdf

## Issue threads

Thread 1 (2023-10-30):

IO Board Firmware Sharing

jancona, 2023-10-30:
Hi,
I've been working on some firmware mods for my own use that might also be useful to others. Has you thought about the model for sharing firmware?

So far, I've cloned this repo, then copied and renamed n2adr_basic. All my changes are in my subdirectory, but I use functions from n2adr_lib. When I'm ready to share my firmware, I could:

* Send a pull request to this repo, which you could review and merge (or not).
* Just publish it to my fork and post info about it to the HL2 mailing list, wiki, etc.
* Something else?

Do you have any thoughts or preferences about this?

Thanks,

Jim
N1ADJ

jimahlstrom, 2023-11-01:
Hello Jim,

I think you should have a subdirectory next to n2adr_basic for your code.
So a pull request seems best, although if our gits are different in other
places there may be a problem. I am not sure if I can pull just a single
directory. Or a zipfile with your directory works too.

Jim
N2ADR

On Mon, Oct 30, 2023 at 11:06 AM Jim Ancona ***@***.***>
wrote:

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

jancona, 2023-11-01:
I can control which files are in the pull request. My firmware is to control the Hardrock-50 amplifier, so I'll put all my changes in a directory named `n1adj_hr50`, if that sounds good to you.

I still have some cleanup to do, but I should have a PR put together soon.

Jim
N1ADJ

TechMindsYT, 2023-11-01:
@jancona I would most definitely be interested in your FW for the HR50 as I have one on it's way to me now. Where is the best place to keep an eye out for your release? thanks, Matt M0DQW

jancona, 2023-11-01:
@TechMindsYT When it's ready I will submit a pull request and when Jim N2ADR merges it it will show up in this repository.

jimahlstrom, 2023-12-08:
I have a new Quisk version 4.2.27 for the antenna tuner. Please test.

Jim
N2ADR

On Mon, Oct 30, 2023 at 11:06 AM Jim Ancona ***@***.***>
wrote:

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

Closed 2023-11-06.

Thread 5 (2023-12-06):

Icom Tuner

fabltd, 2023-12-06:
Hi

I have seen some mentioned of controling an Icom AH4 with this board but I cannot find any example code?

Is there some more examples some where?

Thanks

jimahlstrom, 2023-12-06:
This IO board works with the Hermes-Lite2. It is controlled by the SDR software connected to the HL2.

fabltd, 2023-12-06:
Hi

Yes I realise that. What I want to know is how to connect this to an external antenna Tuner. There is talk but I was asking if there's are any software examples of operating with the Icom Tuner?

jimahlstrom, 2023-12-06:
Please see this thread https://groups.google.com/g/hermes-lite/c/vwYOZGPLUPE/m/cQVS2pyGAQAJ. All discussion of how to use the hardware is on the group https://groups.google.com/g/hermes-lite.

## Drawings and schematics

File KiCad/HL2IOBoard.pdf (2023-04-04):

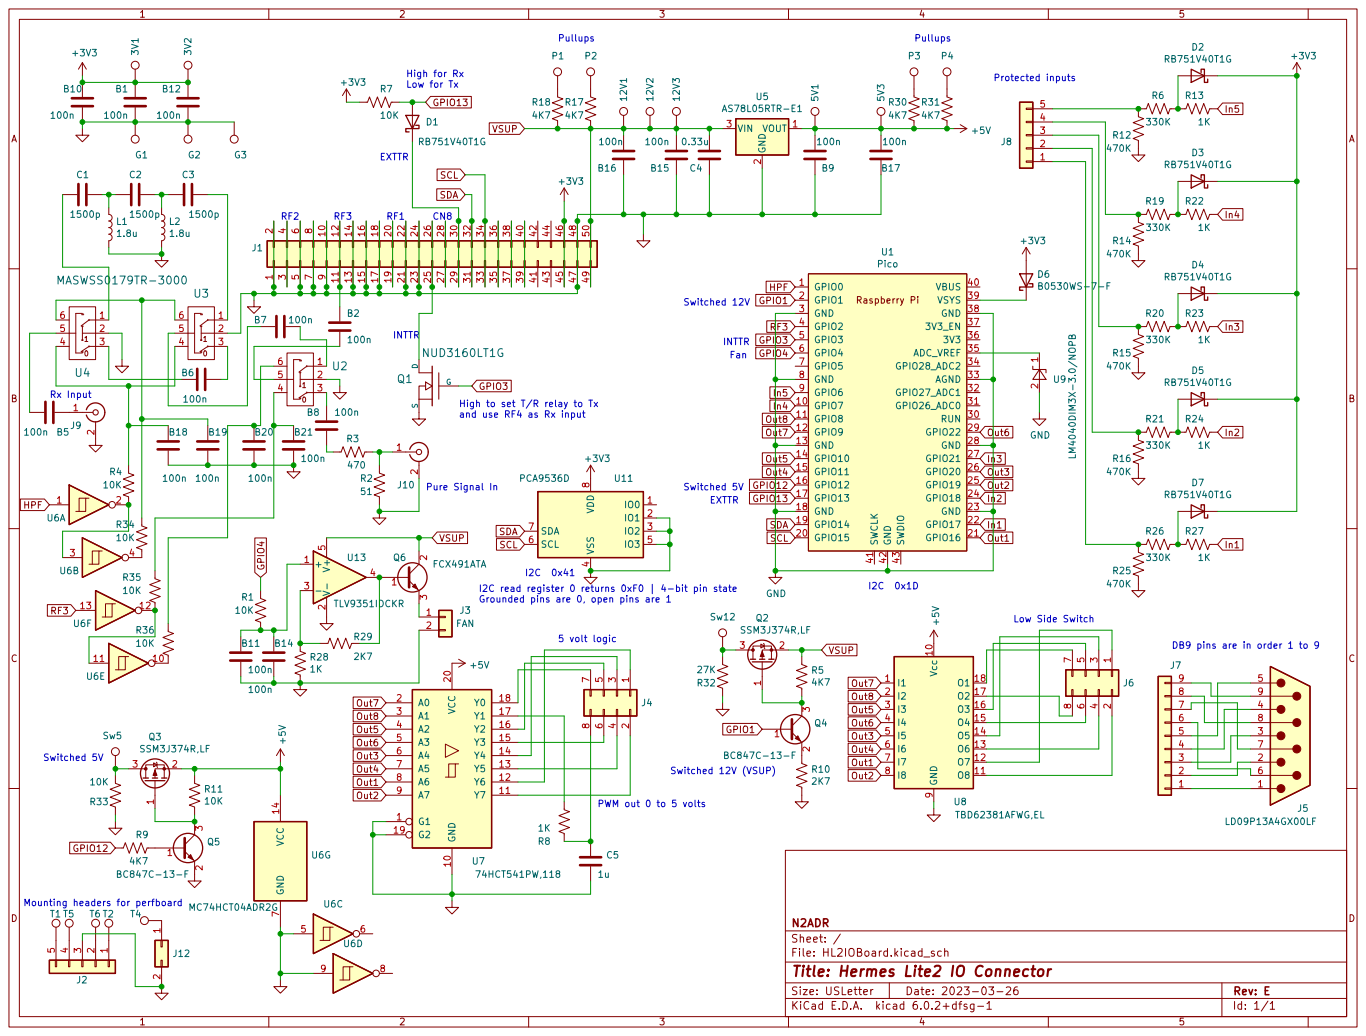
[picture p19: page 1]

I2C 0x41 High to set T/R relay to Tx
and use RF4 as Rx input

In2 Out5 GPIO12 SDA GPIO13 Out4 Pure Signal In

I2C read register 0 returns 0xF0 | 4-bit pin state
Grounded pins are 0, open pins are 1
J3 FAN

Low Side Switch Mounting headers for perfboard

Switched 12V (VSUP) PWM out 0 to 5 volts 5 volt logic

DB9 pins are in order 1 to 9 Switched 5V

Id: 1/1 Title: Hermes Lite2 IO Connector

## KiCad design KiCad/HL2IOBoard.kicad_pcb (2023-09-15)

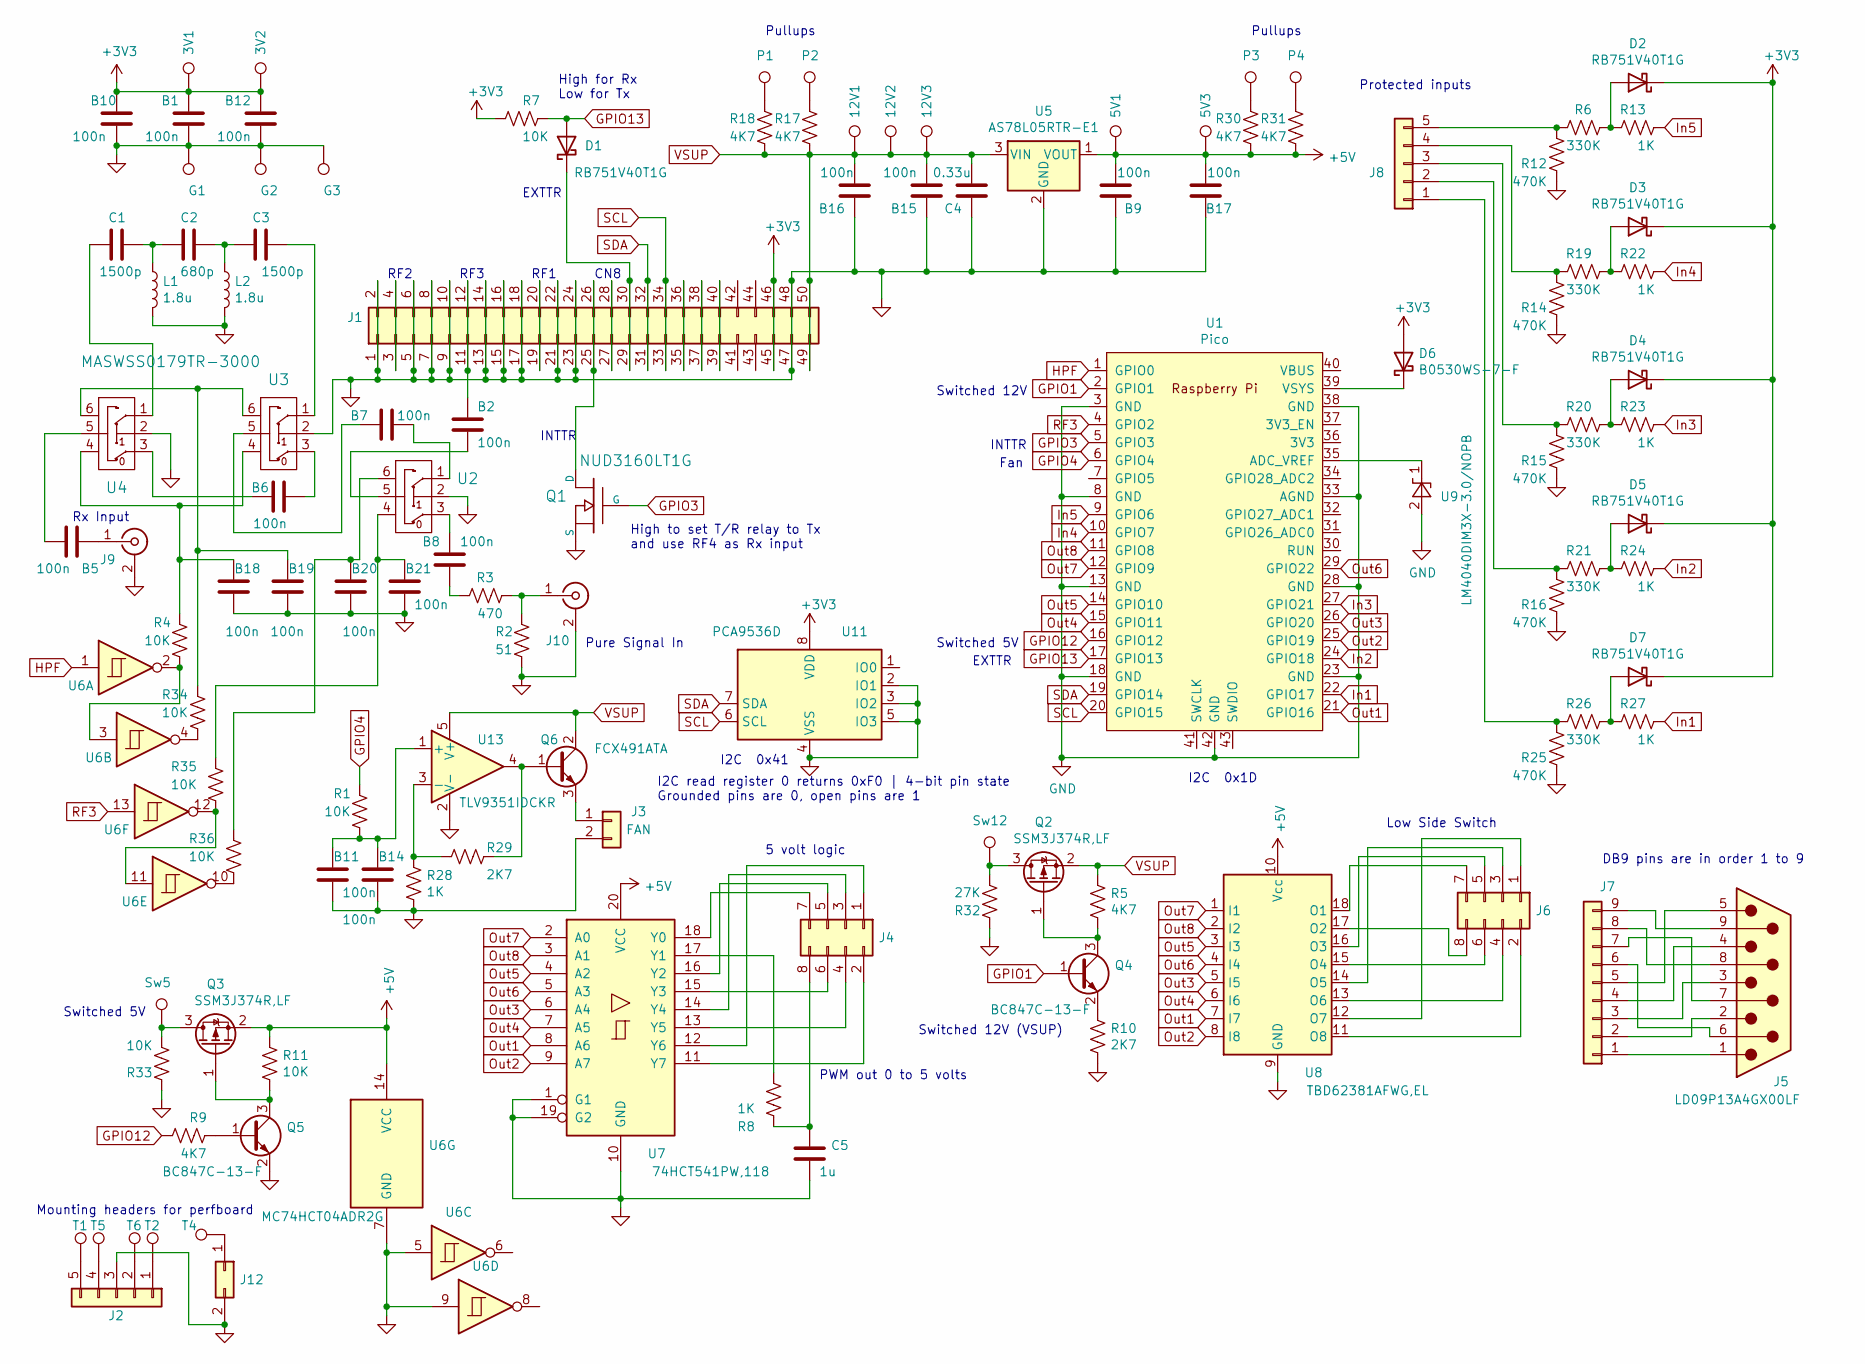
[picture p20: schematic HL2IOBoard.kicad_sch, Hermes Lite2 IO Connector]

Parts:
3V1, 3V2, 5V1, 5V3, 12V1, 12V2, 12V3: TestPoint; TestPoint_THTPad_D1.5mm_Drill0.7mm
B1, B2, B5, B6, B7, B8, B9, B10, B11, B12, B14, B15, B16, B17, B18, B19, B20, B21: 100n; C_0805_2012Metric_Pad1.18x1.45mm_HandSolder
C1, C3: 1500p; C_0805_2012Metric_Pad1.18x1.45mm_HandSolder
C2: 680p; C_0805_2012Metric_Pad1.18x1.45mm_HandSolder
C4: 0.33u; C_0805_2012Metric_Pad1.18x1.45mm_HandSolder
C5: 1u; C_0805_2012Metric_Pad1.18x1.45mm_HandSolder
D1, D2, D3, D4, D5, D7: RB751V40T1G; D_SOD-323_HandSoldering
D6: B0530WS-7-F; D_SOD-323_HandSoldering
G1, G2, G3: TestPoint; TestPoint_THTPad_D1.5mm_Drill0.7mm
J1: Conn_02x25_Odd_Even; PinHeader_2x25_P2.54mm_Vertical
J2, J8: Conn_01x05; PinHeader_1x05_P2.54mm_Vertical
J3: FAN; PinHeader_1x02_P2.54mm_Vertical
J4, J6: Conn_02x04_Odd_Even; PinHeader_2x04_P2.54mm_Vertical
J5: LD09P13A4GX00LF; DSUB-9_Male_Horizontal_P2.77x2.84mm_EdgePinOffset9.90mm_Hou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
J7: Conn_01x09; PinHeader_1x09_P2.54mm_Vertical
J9, J10: 142-0701-851; BNCEDGE
J12: Conn_02x01; PinHeader_1x02_P2.54mm_Vertical
L1, L2: 1.8u; L_0805_2012Metric_Pad1.15x1.40mm_HandSolder
P1, P2, P3, P4: TestPoint; TestPoint_THTPad_D1.5mm_Drill0.7mm
Q1: NUD3160LT1G; SOT23_3
Q2, Q3: SSM3J374R,LF; SOT-23
Q4, Q5: BC847C-13-F; SOT-23
Q6: FCX491ATA; SOT-89-3
R1, R4, R7, R11, R33, R34, R35, R36: 10K; R_0805_2012Metric_Pad1.20x1.40mm_HandSolder
R2: 51; R_0805_2012Metric_Pad1.20x1.40mm_HandSolder
R3: 470; R_0805_2012Metric_Pad1.20x1.40mm_HandSolder
R5, R9, R17, R18, R30, R31: 4K7; R_0805_2012Metric_Pad1.20x1.40mm_HandSolder
R6, R19, R20, R21, R26: 330K; R_0805_2012Metric_Pad1.20x1.40mm_HandSolder
R8, R13, R22, R23, R24, R27, R28: 1K; R_0805_2012Metric_Pad1.20x1.40mm_HandSolder
R10, R29: 2K7; R_0805_2012Metric_Pad1.20x1.40mm_HandSolder
R12, R14, R15, R16, R25: 470K; R_0805_2012Metric_Pad1.20x1.40mm_HandSolder
R32: 27K; R_0805_2012Metric_Pad1.20x1.40mm_HandSolder
Sw5, Sw12: TestPoint; TestPoint_THTPad_D1.5mm_Drill0.7mm
T1, T2, T4, T5, T6: TestPoint; TestPoint_THTPad_D1.5mm_Drill0.7mm
U1: Pico; RPi_Pico_SMD_TH
U2, U3, U4: MASWSS0179TR-3000; SOT-23-6_Handsoldering
U5: AS78L05RTR-E1; SOT-89-3_Handsoldering
U6: MC74HCT04ADR2G; SO-14_3.9x8.65mm_P1.27mm
U7: 74HCT541PW,118; TSSOP-20_4.4x6.5mm_P0.65mm
U8: TBD62381AFWG,EL; SOIC-18W_7.5x11.6mm_P1.27mm
U9: LM4040DIM3X-3.0/NOPB; SOT-23
U11: PCA9536D; SOIC-8_3.9x4.9mm_P1.27mm
U13: TLV9351IDCKR; SOT-353_SC-70-5_Handsoldering

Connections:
+3V3: 3V1.1, 3V2.1, B1.2, B10.1, B12.2, D2.1 (K), D3.1 (K), D4.1 (K), D5.1 (K), D6.2 (A), D7.1 (K), J1.45, J1.46, R7.2, U11.8 (VDD)
+5V: 5V1.1, 5V3.1, B9.2, B17.2, Q3.2 (S), R11.1, R30.2, R31.2, U5.1 (VOUT), U6.14 (VCC), U7.20 (VCC), U8.10 (Vcc)
GND: B1.1, B9.1, B10.2, B11.2, B12.1, B14.2, B15.1, B16.1, B17.1, B18.2, B19.2, B20.2, B21.2, C4.1, C5.2, G1.1, G2.1, G3.1, J1.1, J1.2, J1.5, J1.6, J1.7, J1.8, J1.9, J1.10, J1.13, J1.14, J1.15, J1.16, J1.17, J1.18, J1.21, J1.22, J1.23, J1.24, J1.47, J1.48, J2.3, J3.2, J9.2 (Ext), J10.2 (Ext), J12.2, L1.2, L2.2, Q1.2 (S), Q5.2 (E), R2.2, R10.2, R12.1, R14.1, R15.1, R16.1, R25.1, R28.2, R32.2, R33.2, U1.3 (GND), U1.8 (GND), U1.13 (GND), U1.18 (GND), U1.23 (GND), U1.28 (GND), U1.33 (AGND), U1.38 (GND), U1.42 (GND), U2.2, U3.2, U4.2, U5.2 (GND), U6.5, U6.7 (GND), U6.9, U7.1 (G1), U7.10 (GND), U7.19 (G2), U8.9 (GND), U9.2 (A), U11.2 (IO1), U11.3 (IO2), U11.4 (VSS), U11.5 (IO3), U13.2 (V-)
GPIO1: Q4.1 (B), U1.2 (GPIO1)
GPIO3: Q1.1 (G), U1.5 (GPIO3)
GPIO4: R1.1, U1.6 (GPIO4)
GPIO12: R9.2, U1.16 (GPIO12)
GPIO13: D1.2 (A), R7.1, U1.17 (GPIO13)
HPF: U1.1 (GPIO0), U6.1
In1: R27.2, U1.22 (GPIO17)
In2: R24.2, U1.24 (GPIO18)
In3: R23.2, U1.27 (GPIO21)
In4: R22.2, U1.10 (GPIO7)
In5: R13.2, U1.9 (GPIO6)
unnamed: B2.1, J1.11, J1.12
unnamed: B2.2, U2.5
unnamed: B5.1, J9.1 (In)
unnamed: B5.2, U4.5
unnamed: B6.1, U4.3
unnamed: B6.2, U3.3
unnamed: B7.1, U3.5
unnamed: B7.2, U2.1
unnamed: B8.1, R3.1
unnamed: B8.2, U2.3
unnamed: B11.1, B14.1, R1.2, U13.1 (+)
unnamed: B18.1, R4.1, U3.4, U4.4
unnamed: B19.1, R34.2, U3.6, U4.6
unnamed: B20.1, R36.2, U2.6
unnamed: B21.1, R35.2, U2.4
unnamed: C1.1, C2.2, L1.1
unnamed: C1.2, U4.1
unnamed: C2.1, C3.2, L2.1
unnamed: C3.1, U3.1
unnamed: C5.1, J4.8, R8.1
unnamed: D1.1 (K), J1.29, J1.30
unnamed: D2.2 (A), R6.2, R13.1
unnamed: D3.2 (A), R19.2, R22.1
unnamed: D4.2 (A), R20.2, R23.1
unnamed: D5.2 (A), R21.2, R24.1
unnamed: D6.1 (K), U1.39 (VSYS)
unnamed: D7.2 (A), R26.2, R27.1
unnamed: J1.3, J1.4
unnamed: J1.19, J1.20
unnamed: J1.25, J1.26, Q1.3 (D)
unnamed: J1.27, J1.28
unnamed: J1.35, J1.36
unnamed: J1.37, J1.38
unnamed: J1.39, J1.40
unnamed: J2.1, T2.1
unnamed: J2.2, T6.1
unnamed: J2.4, T5.1
unnamed: J2.5, T1.1
unnamed: J3.1, Q6.3 (E)
unnamed: J4.1, U7.12 (Y6)
unnamed: J4.2, U7.11 (Y7)
unnamed: J4.3, U7.14 (Y4)
unnamed: J4.4, U7.13 (Y5)
unnamed: J4.5, U7.16 (Y2)
unnamed: J4.6, U7.15 (Y3)
unnamed: J4.7, U7.18 (Y0)
unnamed: J5.1, J7.1
unnamed: J5.2, J7.2
unnamed: J5.3, J7.3
unnamed: J5.4, J7.4
unnamed: J5.5, J7.5
unnamed: J5.6, J7.6
unnamed: J5.7, J7.7
unnamed: J5.8, J7.8
unnamed: J5.9, J7.9
unnamed: J6.1, U8.12 (O7)
unnamed: J6.2, U8.11 (O8)
unnamed: J6.3, U8.14 (O5)
unnamed: J6.4, U8.13 (O6)
unnamed: J6.5, U8.16 (O3)
unnamed: J6.6, U8.15 (O4)
unnamed: J6.7, U8.18 (O1)
unnamed: J6.8, U8.17 (O2)
unnamed: J8.1, R25.2, R26.1
unnamed: J8.2, R16.2, R21.1
unnamed: J8.3, R15.2, R20.1
unnamed: J8.4, R14.2, R19.1
unnamed: J8.5, R6.1, R12.2
unnamed: J10.1 (In), R2.1, R3.2
unnamed: J12.1, T4.1
unnamed: P1.1, R18.1
unnamed: P2.1, R17.1
unnamed: P3.1, R30.1
unnamed: P4.1, R31.1
unnamed: Q2.1 (G), Q4.3 (C), R5.2
unnamed: Q2.3 (D), R32.1, Sw12.1
unnamed: Q3.1 (G), Q5.3 (C), R11.2
unnamed: Q3.3 (D), R33.1, Sw5.1
unnamed: Q4.2 (E), R10.1
unnamed: Q5.1 (B), R9.1
unnamed: Q6.1 (B), R29.1, U13.4
unnamed: R4.2, U6.2, U6.3
unnamed: R8.2, U7.17 (Y1)
unnamed: R28.1, R29.2, U13.3 (-)
unnamed: R34.1, U6.4
unnamed: R35.1, U6.11, U6.12
unnamed: R36.1, U6.10
unnamed: U1.35 (ADC_VREF), U9.1 (K)
Out1: U1.21 (GPIO16), U7.8 (A6), U8.7 (I7)
Out2: U1.25 (GPIO19), U7.9 (A7), U8.8 (I8)
Out3: U1.26 (GPIO20), U7.6 (A4), U8.5 (I5)
Out4: U1.15 (GPIO11), U7.7 (A5), U8.6 (I6)
Out5: U1.14 (GPIO10), U7.4 (A2), U8.3 (I3)
Out6: U1.29 (GPIO22), U7.5 (A3), U8.4 (I4)
Out7: U1.12 (GPIO9), U7.2 (A0), U8.1 (I1)
Out8: U1.11 (GPIO8), U7.3 (A1), U8.2 (I2)
RF3: U1.4 (GPIO2), U6.13
SCL: J1.33, J1.34, U1.20 (GPIO15), U11.6 (SCL)
SDA: J1.31, J1.32, U1.19 (GPIO14), U11.7 (SDA)
VSUP: 12V1.1, 12V2.1, 12V3.1, B15.2, B16.2, C4.2, J1.49, J1.50, Q2.2 (S), Q6.2 (C), R5.1, R17.2, R18.2, U5.3 (VIN), U13.5 (V+)

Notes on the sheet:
CN8
Rx Input
Protected inputs
Pure Signal In
PWM out 0 to 5 volts
EXTTR
RF1
INTTR
RF3
High to set T/R relay to Tx and use RF4 as Rx input
Mounting headers for perfboard
Fan
Pullups
I2C 0x41
5 volt logic
Switched 12V
I2C 0x1D
I2C read register 0 returns 0xF0 | 4-bit pin state Grounded pins are 0, open pins are 1
Switched 5V
Switched 12V (VSUP)
Low Side Switch
DB9 pins are in order 1 to 9
RF2
High for Rx Low for Tx

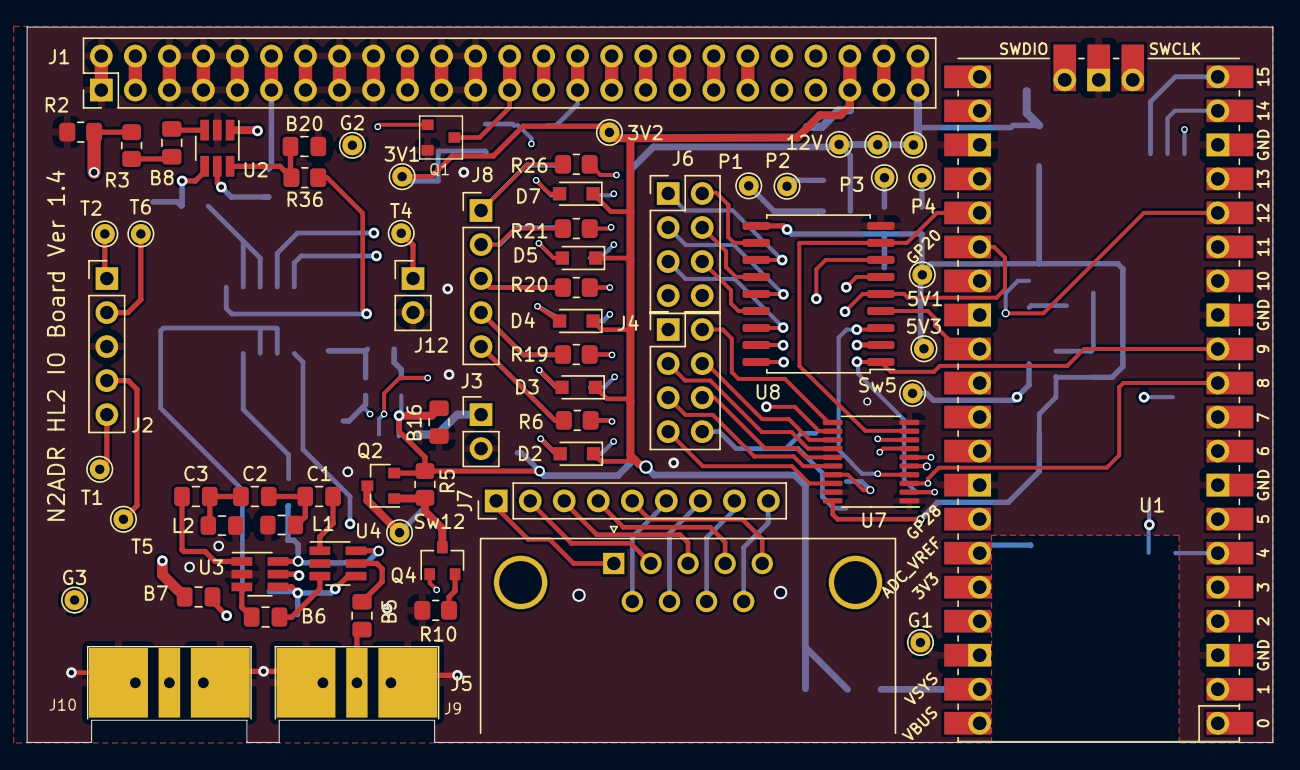
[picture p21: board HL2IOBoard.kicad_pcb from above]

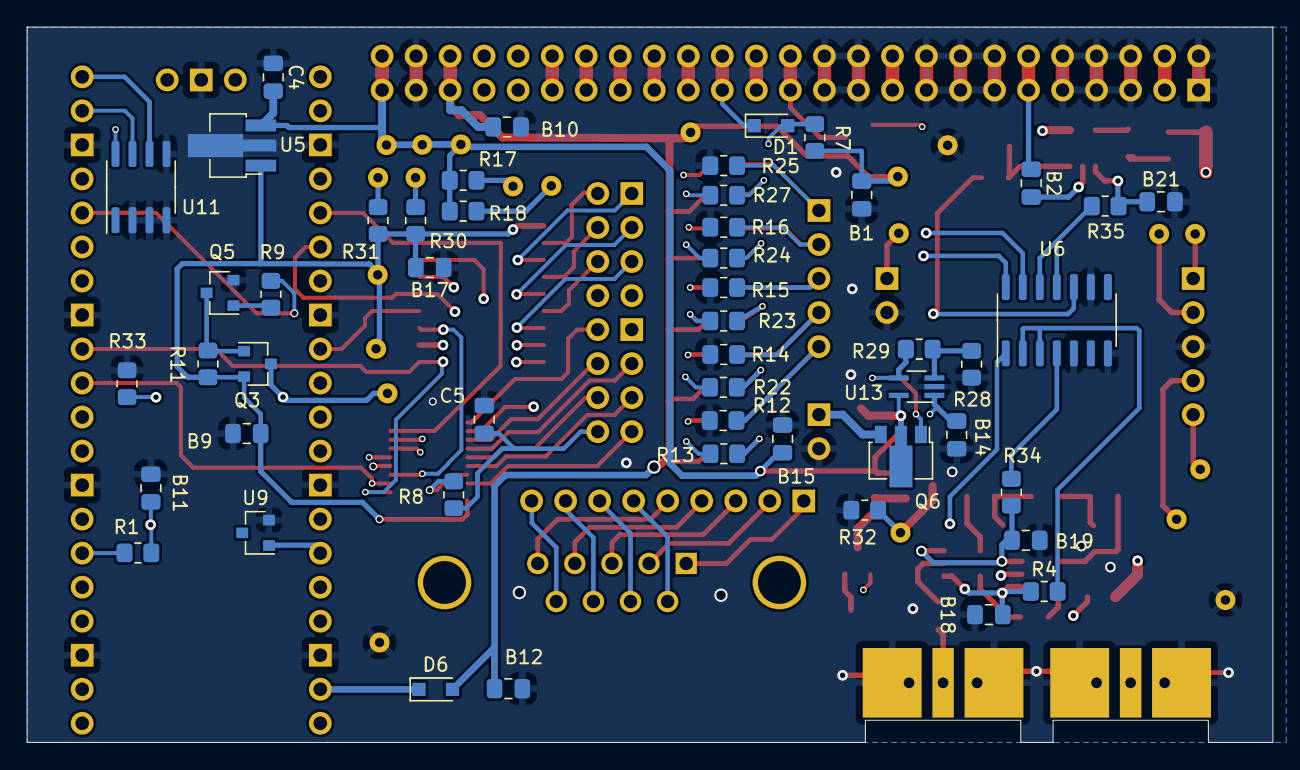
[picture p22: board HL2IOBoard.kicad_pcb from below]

Board: 4 copper layers, 93.0 x 53.4 mm, 117 parts (50 on the bottom side), 114 nets.

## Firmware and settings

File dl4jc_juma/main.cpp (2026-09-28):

// JUMA amplifier firmware for the Hermes Lite 2 IO board by N2ADR.
//
//   Copyright (c) 2022-2023 James C. Ahlstrom <jahlstr@gmail.com>  (the board
//     and its library; this file follows the structure of his examples)
//   Copyright (c) 2026 DL4JC <mail@dl4jc.de>  (the JUMA part)
//   MIT licence, both parts - see MIT.txt in the HL2IOBoard project and
//   LICENSE in this one.
//
// The board sends the transmit frequency to the Pico over I2C. This firmware
// turns that into a JUMA band command over the serial port, and reads the PA's
// status back into I2C registers so the SDR software can see what the
// amplifier is doing.
//
// The path is the same one M0HPF's SPE firmware uses - Pico UART, a MAX3232 to
// get RS-232 levels, and the amplifier's own serial command set. Only the
// commands differ, and the JUMA differs in three ways that shape this file:
//
//   1. It is silent until asked. The SPE polls the transceiver; the JUMA
//      answers '=R' and says nothing otherwise. So we are the master and must
//      poll, not wait.
//   2. Remote mode times out. 5 s after the last command the PA leaves remote
//      mode and drops to STANDBY (manual, annex D). The 500 ms poll is what
//      keeps it alive - it is not just there for the display.
//   3. '=Bn' is a *manual* band selection. It moves the PA from A to M, and it
//      can knock the PA out of OPERATE. See hold_operate() below.
//
// The status parser and the band table are not duplicated here: they are the
// same files the ESP32 firmware in this repository uses, so a corrected band
// edge or a corrected field is corrected for both. tests/run.sh covers them on
// the host.
// The board's library is C, this file is C++ - the parser and the band table
// are shared with the ESP32 firmware and that is C++. So hl2ioboard.h has to
// be declared with C linkage, or its functions would be looked up under
// mangled names and nothing would link. The SDK headers come first, before
// that wrapper: they carry their own linkage guards, and their include guards
// then turn the nested includes inside hl2ioboard.h into no-ops.
#include <hardware/gpio.h>
#include <hardware/i2c.h>
#include <hardware/pwm.h>
#include <hardware/adc.h>
#include <hardware/uart.h>
#include <pico/i2c_slave.h>
#include <pico/binary_info.h>
#include <pico/bootrom.h>
#include <pico/stdlib.h>
#include <stdio.h>
#include <string.h>

extern "C" {
#include <hl2ioboard.h>
}
#include <i2c_registers.h>

#include "juma_regs.h"
#include "juma_status.h"
#include "bands.h"

// The UART on J4 pin 1 (TX) and J8 pin 1 (RX). configure_pins(true, ...)
// switches those pins to the UART, which on the RP2040 is uart0.
#define UART_ID     uart0
#define BAUD_RATE   115200        // the PA-100D speaks 115200 8N1
#define DATA_BITS   8
#define STOP_BITS   1
#define PARITY      UART_PARITY_NONE

// Prints the traffic to the USB serial port and accepts typed commands there.
// Off for normal use. Unlike the other firmwares for this board this is not
// edited in the source but set at configure time:
//     cmake -DJUMA_DEBUG=ON ..
// so the quiet image and the talking one can be built from the same tree.
#ifndef JUMA_DEBUG
#define JUMA_DEBUG  0
#endif

// What REG_JUMA_MODE holds at power-up, and again after the host resets the
// registers. Every register comes up zero, which is right for band following
// but leaves the OPERATE hold off - and on a board with no software that knows
// these registers, nobody is there to switch it on. So it can be built in:
//     cmake -DJUMA_HOLD_OPERATE=ON ..
#ifndef JUMA_MODE_AT_BOOT
#define JUMA_MODE_AT_BOOT 0
#endif

// Major and minor firmware version, returned in REG_FIRMWARE_MAJOR/MINOR.
uint8_t firmware_version_major = 1;
uint8_t firmware_version_minor = 0;

// --- Timing ---------------------------------------------------------------
// Remote mode dies 5 s after the last command, so the poll has to be well
// inside that. The manual suggests about 1 s; 500 ms costs nothing here.
static const uint32_t POLL_INTERVAL_MS = 500;
// After this long without an understood status reply the link counts as dead.
static const uint32_t STALE_AFTER_MS   = 3000;
// Minimum spacing between two commands to the PA.
static const uint32_t CMD_GAP_MS       = 40;
// The frequency must hold still this long before a band command goes out.
// Tuning across a band edge would otherwise fire one command per step - and
// it is also what makes a torn read of the 64-bit new_tx_freq harmless: a
// value that the I2C interrupt was in the middle of writing is replaced on the
// next pass, 1 ms later, and so never survives to become a band command.
static const uint32_t BAND_SETTLE_MS   = 150;
// Do not repeat a band command faster than this.
static const uint32_t BAND_REPEAT_MS   = 1000;
// Spacing and count of the attempts to push the PA back where we want it.
// Bounded, so a choice somebody made at the front panel is not overridden for
// ever - it gives way after three tries and reports through REG_JUMA_FLAGS.
static const uint32_t RETRY_GAP_MS     = 5000;
static const uint8_t  RETRY_MAX        = 3;

static inline uint32_t now_ms(void)
{
	return to_ms_since_boot(get_absolute_time());
}

// --- The mode at power-up -------------------------------------------------
// It is not kept. Storing it meant erasing a flash sector, and an erase runs
// with interrupts off for tens of milliseconds - during which the I2C slave
// cannot be served, so the RP2040 holds SCL low. The HL2's master has no
// timeout and no bus recovery (i2c_bus2.v, and hermeslite_core.v does not even
// wire up the acknowledge line), and the filter board sits on that same
// expansion bus with its own address. One erase in the wrong moment can
// therefore take the whole bus down, filter relays included.
//
// A mode that survives a power cycle is a convenience; a wedged I2C bus costs
// the station. So the mode comes up as JUMA_MODE_AT_BOOT, which is a build
// option, and a host that wants something else writes REG_JUMA_MODE after
// every start.

// --- Is the bus still there? ----------------------------------------------
// The expansion bus has died twice here: no register answered, the band stopped
// following, the filter board stopped switching, and only a power cycle of the
// HL2 brought it back. From the outside those look identical, but they are two
// different faults and only one of them could ever be repaired from this side:
//
//   somebody holds a line down   - a classic jam. SCL or SDA stays low, and the
//                                  cure is to clock SCL until the stuck device
//                                  lets go. This board owns the pins, so it
//                                  could do that.
//   the master's state machine   - the gateware is waiting for something inside
//   has stopped                    itself. The lines are idle and high, nothing
//                                  is held, and no amount of clocking from out
//                                  here resets logic in an FPGA. Only a reset
//                                  of the radio helps.
//
// Telling them apart took a day of guessing, so measure it instead. What this
// reports is facts, not a verdict:
//
//   sda, scl   the pad levels. gpio_get() reads the input whatever the function
//              mux says, so this works while the pins belong to the I2C block.
//              Both high with no traffic is the second case; a line low for
//              hundreds of milliseconds is the first.
//   low        how long SCL has been continuously low, in ms. During traffic at
//              400 kHz it is never more than a couple of microseconds, so
//              anything the 1 ms loop can even see is already wrong.
//   wr, idle   register writes seen, and how long since the last one. Writes are
//              all this can count: IrqHandler fires on a write, and a read by
//              the host leaves no trace here. In principle that makes 'idle'
//              weaker than it looks - a station sitting on one frequency might
//              have nothing to write. Measured on a gateware 74.2 it does not
//              work out that way: the radio rewrites the transmit frequency
//              about 2.5 times a second whether it changed or not, with no
//              software on the bridge at all. So on this radio 'idle' does climb
//              when the bus dies. On another one, check 'wr' moves before
//              trusting it, and read sda/scl either way - those are never
//              ambiguous.
//
// None of it goes into a register. The whole point is to be readable when the
// bus is dead, and that means the USB port.
static volatile uint32_t i2c_writes  = 0;
static volatile uint32_t last_i2c_ms = 0;
static uint32_t scl_low_since = 0;      // 0 = the line is not low
static uint32_t scl_low_ms    = 0;
static uint32_t sda_low_since = 0;
static uint32_t sda_low_ms    = 0;
static uint32_t recoveries    = 0;      // times the bus was clocked free

// Hung on registers the two sides write in normal operation: the gateware puts
// the transmit frequency in REG_TX_FREQ_BYTE0 last, and a host asking for a
// snapshot writes REG_JUMA_SNAP.
static void note_i2c_write(uint8_t reg, uint8_t data)
{
	(void)reg;
	(void)data;
	i2c_writes++;
	last_i2c_ms = now_ms();
}

// Called once per pass. Two GPIO reads, no allocation, no branch worth counting.
//
// Both lines, because the first version watched only SCL and that was the wrong
// one. Caught in the act: with the bus dead for five and a half hours, SDA read
// low in 22 of 25 samples while SCL flickered, so scl_low_ms kept resetting to
// zero and reported nothing wrong. It is SDA that a stuck device holds - it is
// driving a data bit and waiting for a clock edge that never comes.
//
// A millisecond sampler is coarse for a 400 kHz bus, and that is exactly why it
// works: real traffic leaves both lines idle high between transactions, so a
// sample almost always lands on a high. Consecutive lows for more than a few
// milliseconds cannot be traffic.
static void watch_line(bool high, uint32_t *since, uint32_t *ms)
{
	if (high) {
		*since = 0;
		*ms = 0;
	} else {
		if (!*since)
			*since = now_ms();
		*ms = now_ms() - *since;
	}
}

static void watch_bus(void)
{
	watch_line(gpio_get(GPIO15_I2C1_SCL), &scl_low_since, &scl_low_ms);
	watch_line(gpio_get(GPIO14_I2C1_SDA), &sda_low_since, &sda_low_ms);
}

// --- Getting the bus back -------------------------------------------------
// Measured on a dead bus: SDA held low for five and a half hours, SCL free, no
// register write arriving, the Pico otherwise perfectly alive. That is the
// textbook I2C deadlock - some device is driving a data bit and waiting for a
// clock edge that will not come, because the master stopped mid-transaction.
//
// The textbook way out is to be the clock for a moment: pulse SCL until the
// stuck device has shifted its byte out and released SDA, then make a STOP so
// everybody agrees the bus is free again. Nine pulses, because a byte is eight
// bits and the ninth is the acknowledge.
//
// Two things are tried, cheapest first:
//
//   1. Re-initialise our own slave. If the Pico's peripheral is the one stuck
//      mid-byte, nothing outside needs touching at all.
//   2. Clock the bus free, if SDA is still low afterwards.
//
// Open drain: a line is pulled low by driving an output low, and released by
// turning the pin back into an input so the pull-up takes it high. Never drive
// either line high - another device may be holding it down, and two drivers
// fighting is how pins die.
//
// The rule at the top of this file still holds: interrupts stay on throughout.
// The pins leave the I2C block for about 200 us, during which this board cannot
// answer - which costs nothing on a bus that has been dead for minutes.
static const uint32_t RECOVER_AFTER_MS = 30000;  // no write for this long, and
static const uint32_t RECOVER_HELD_MS  = 50;     // a line held this long
static const uint32_t RECOVER_GAP_MS   = 60000;  // and not more often than this
// Once, not ten times. Measured while the bus was deliberately deadlocked:
// clocking it free does release SDA - it went from 0 to 1 every time - and the
// master never resumes, so SDA is pulled down again within the minute.
// Repeating that is noise on a bus that is already gone, from the only code here
// that drives it at all. One attempt still answers the question worth asking,
// which is whether the fault is the held-line kind; 'rec' reaching 1 with sda
// going 0 -> 1 says it is. A diagnosis, not a repair - only a power cycle of the
// radio is the latter.
static const uint8_t  RECOVER_MAX      = 1;

static void scl_pulse(void)
{
	// Release: input, pull-up takes it high. Then drive low. 100 kHz, slow
	// enough for anything on this bus to follow.
	gpio_set_dir(GPIO15_I2C1_SCL, GPIO_IN);
	busy_wait_us(5);
	gpio_put(GPIO15_I2C1_SCL, 0);
	gpio_set_dir(GPIO15_I2C1_SCL, GPIO_OUT);
	busy_wait_us(5);
}

static void bus_recover(void)
{
	// Step 1: our own peripheral, in case it is the one holding the bit.
	i2c_slave_deinit(i2c1);
	i2c_deinit(i2c1);
	i2c_init(i2c1, I2C1_BAUDRATE);
	i2c_slave_init(i2c1, I2C1_ADDRESS, &i2c_slave_handler);
	busy_wait_us(100);
	if (gpio_get(GPIO14_I2C1_SDA))
		goto done;              // that was enough

	// Step 2: be the clock. Pins out of the I2C block, both as open drain.
	gpio_set_function(GPIO15_I2C1_SCL, GPIO_FUNC_SIO);
	gpio_set_function(GPIO14_I2C1_SDA, GPIO_FUNC_SIO);
	gpio_put(GPIO15_I2C1_SCL, 0);
	gpio_put(GPIO14_I2C1_SDA, 0);
	gpio_set_dir(GPIO15_I2C1_SCL, GPIO_IN);
	gpio_set_dir(GPIO14_I2C1_SDA, GPIO_IN);

	for (int i = 0; i < 9 && !gpio_get(GPIO14_I2C1_SDA); i++)
		scl_pulse();

	// STOP: SDA low while SCL is high, then SDA released. Whoever was in the
	// middle of a transfer treats that as the end of one.
	gpio_set_dir(GPIO15_I2C1_SCL, GPIO_IN);
	busy_wait_us(5);
	gpio_set_dir(GPIO14_I2C1_SDA, GPIO_OUT);
	busy_wait_us(5);
	gpio_set_dir(GPIO14_I2C1_SDA, GPIO_IN);
	busy_wait_us(5);

	// And hand the pins back.
	gpio_set_function(GPIO14_I2C1_SDA, GPIO_FUNC_I2C);
	gpio_set_function(GPIO15_I2C1_SCL, GPIO_FUNC_I2C);
	i2c_slave_deinit(i2c1);
	i2c_deinit(i2c1);
	i2c_init(i2c1, I2C1_BAUDRATE);
	i2c_slave_init(i2c1, I2C1_ADDRESS, &i2c_slave_handler);

done:
	recoveries++;
	sda_low_since = scl_low_since = 0;
	sda_low_ms = scl_low_ms = 0;
}

// Defined below, with the rest of the transmit handling.
static bool transmitting(void);

// Bounded, and never while the amplifier is transmitting: driving a bus is not
// something to do in the middle of a transmission, and a fault that only shows
// up on TX would be hidden by fixing it there.
static void maybe_recover(void)
{
	static uint32_t last_try = 0;
	static uint8_t  tries    = 0;

	if (tries >= RECOVER_MAX || transmitting())
		return;
	if (!last_i2c_ms || now_ms() - last_i2c_ms < RECOVER_AFTER_MS)
		return;
	if (sda_low_ms < RECOVER_HELD_MS && scl_low_ms < RECOVER_HELD_MS)
		return;                 // dead, but nothing is being held
	if (last_try && now_ms() - last_try < RECOVER_GAP_MS)
		return;

	last_try = now_ms();
	tries++;
	bus_recover();
}

// --- Receiving ------------------------------------------------------------
// The interrupt handler only moves bytes into a ring buffer; the lines are
// assembled and parsed in the main loop. Parsing in the handler would mean
// doing float conversions with interrupts off, and the board's rule is that
// an interrupt service routine returns quickly.
#define RX_RING 512
static volatile uint8_t  rx_ring[RX_RING];
static volatile uint16_t rx_head = 0, rx_tail = 0;   // head: handler, tail: loop
static volatile uint16_t rx_lost = 0;

static void on_uart_rx(void)
{
	while (uart_is_readable(UART_ID)) {
		uint8_t ch = uart_getc(UART_ID);
		uint16_t next = (uint16_t)((rx_head + 1) % RX_RING);
		if (next == rx_tail) {		// buffer full: drop, and say so
			rx_lost++;
			continue;
		}
		rx_ring[rx_head] = ch;
		rx_head = next;
	}
}

// --- State ----------------------------------------------------------------
static JumaStatus st;			// what the PA last told us
static uint32_t   last_rx_ms   = 0;	// when that was
static uint32_t   replies      = 0;	// understood status replies
static uint32_t   bad_lines    = 0;	// everything else, banner included
static char       line[128];
static uint8_t    line_len     = 0;
static char       banner[48]   = {0};   // what the PA called itself at power-up
static uint8_t    banner_len   = 0;

static uint64_t   tx_freq      = 0;	// transmit frequency we are acting on
static uint32_t   freq_set_at  = 0;	// when it last changed
static uint8_t    want_band    = 0;	// band that frequency asks for

static uint32_t   last_band_cmd = 0;
static uint8_t    force_m_tries = 0;	// attempts to pull the PA from A to M
static uint32_t   last_force_m  = 0;
static uint8_t    operate_tries = 0;	// attempts to get OPERATE back
static uint32_t   last_operate  = 0;

// REG_CONTROL == 1 resets the board to its power-up state. The library does that
// inside the I2C interrupt, so all we do here is note it and act in the loop -
// the register handler has to return quickly.
static volatile bool host_reset = false;

static void on_control_written(uint8_t reg, uint8_t data)
{
	(void)reg;
	if (data == 1)
		host_reset = true;
}

static bool online(void)
{
	return st.valid && (now_ms() - last_rx_ms) < STALE_AFTER_MS;
}

// Either side saying "transmit" is enough. EXTTR from the HL2 leads the RF and
// is the earlier of the two; the PA's own field 3 covers a transmission the
// HL2 knows nothing about, for instance during a tune-up from another rig.
static bool transmitting(void)
{
	return !gpio_get(GPIO13_EXTTR) || (online() && st.tx);
}

// --- Sending --------------------------------------------------------------
// A short queue rather than writing straight to the UART: a band change, an
// '=O' behind it and the running poll would otherwise arrive back to back, and
// the PA wants a gap between commands.
#define QN 8
#define QL 8
static char    q[QN][QL];
static uint8_t q_head = 0, q_tail = 0;
static uint32_t last_tx_ms = 0;
static char    last_sent[QL] = "";

// Commands and replies end with 0x0A 0x0D - LF before CR, not the usual way
// round. The manual writes it as "=[Command][Parameter]\n\r".
static const char *TERM = "\n\r";

static bool enqueue(const char *cmd)
{
	// Refuse rather than truncate. The longest thing the PA takes is '=P0',
	// so anything approaching QL is a typo on the console - and half of a
	// mistyped command is worse than none of it.
	if (strlen(cmd) >= QL)
		return false;
	uint8_t next = (uint8_t)((q_tail + 1) % QN);
	if (next == q_head)
		return false;			// full; the caller retries next pass
	strcpy(q[q_tail], cmd);
	q_tail = next;
	return true;
}

static void pump_queue(void)
{
	if (q_head == q_tail)
		return;
	if (now_ms() - last_tx_ms < CMD_GAP_MS)
		return;
	uart_puts(UART_ID, q[q_head]);
	uart_puts(UART_ID, TERM);
#if JUMA_DEBUG
	printf("-> %s\n", q[q_head]);
#endif
	snprintf(last_sent, sizeof(last_sent), "%s", q[q_head]);
	q_head = (uint8_t)((q_head + 1) % QN);
	last_tx_ms = now_ms();
}

static bool set_band(uint8_t n)
{
	if (n < 1 || n > 9)
		return false;
	char c[4] = { '=', 'B', (char)('0' + n), '\0' };
	return enqueue(c);
}

static bool set_gain(uint8_t n)
{
	if (n < 1 || n > 4)
		return false;
	char c[4] = { '=', 'G', (char)('0' + n), '\0' };
	return enqueue(c);
}
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
int main(void)
{
	uint32_t last_poll = 0;

	stdio_init_all();
	configure_pins(true, false);	// J4 pin 1 and J8 pin 1 become the UART
	configure_led_flasher();

	// Switched 5 V on, so a level shifter fed from Sw5 comes up with the
	// board. configure_pins() leaves it off, and a MAX3232 without power
	// looks exactly like a dead amplifier. If the shifter is wired to the
	// unswitched 5V1 pad instead this changes nothing.
	gpio_put(GPIO12_Sw5, 1);

	uart_init(UART_ID, BAUD_RATE);
	uart_set_hw_flow(UART_ID, false, false);
	uart_set_format(UART_ID, DATA_BITS, STOP_BITS, PARITY);
	uart_set_fifo_enabled(UART_ID, true);

	Registers[REG_JUMA_MODE] = JUMA_MODE_AT_BOOT;

	// Let the SDR software recognise the board, or it will not send the
	// transmit frequency at all and nothing downstream of it can work.
	Registers[REG_LPF_DETECT] = LPF_DETECT_MAGIC;
	Registers[REG_LPF_STATUS] = 0;
	IrqHandler[REG_CONTROL]  = on_control_written;
	// See 'Is the bus still there?' above: the two registers the gateway
	// and a host write in normal operation, used as a sign of life.
	IrqHandler[REG_TX_FREQ_BYTE0] = note_i2c_write;
	IrqHandler[REG_JUMA_SNAP]     = note_i2c_write;

	int UART_IRQ = UART_ID == uart0 ? UART0_IRQ : UART1_IRQ;
	irq_set_exclusive_handler(UART_IRQ, on_uart_rx);
	irq_set_enabled(UART_IRQ, true);
	uart_set_irq_enables(UART_ID, true, false);	// receive only

	while (1) {
		sleep_ms(1);			// this sets the polling frequency

		if (host_reset) {
			host_reset = false;
			// The library has just zeroed every register, new_tx_freq
			// included. Put our default back and start over, so the
			// retry counters do not carry a state that no longer exists.
			Registers[REG_LPF_DETECT] = LPF_DETECT_MAGIC;
			Registers[REG_JUMA_MODE] = JUMA_MODE_AT_BOOT;
			tx_freq = 0;
			want_band = 0;
			force_m_tries = 0;
			operate_tries = 0;
#if JUMA_DEBUG
			printf("host reset - mode back to 0x%02X\n", JUMA_MODE_AT_BOOT);
#endif
		}

		watch_bus();
		maybe_recover();
		drain_rx();
		run_command();
		run_setters();
		band_control();
		hold_operate();

		// The poll goes last so a command that came up in this pass is
		// ahead of it in the queue - and it is this poll that keeps the PA
		// in remote mode at all.
		if (now_ms() - last_poll >= POLL_INTERVAL_MS) {
			last_poll = now_ms();
			enqueue("=R");
		}

		pump_queue();
		publish();
		take_snapshot();		// after publish(), which fills what it copies
		telemetry();
		usb_console();
	}
}

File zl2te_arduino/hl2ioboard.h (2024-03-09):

// This is firmware for the Hermes Lite 2 IO board designed by Jim Ahlstrom, N2ADR. It is
//   Copyright (c) 2022-2023 James C. Ahlstrom <jahlstr@gmail.com>.
//   It is licensed under the MIT license. See MIT.txt.

#include <hardware/gpio.h>
#include <hardware/i2c.h>
//#include <pico/i2c_slave.h>
#include <hardware/pwm.h>
#include <hardware/adc.h>
#include <pico/binary_info.h>
#include <pico/stdlib.h>
#include <stdio.h>

#define I2C1_ADDRESS	0x1D
//#define I2C1_BAUDRATE	(400 * 1000)
#define FT817_SLICE	4
#define FT817_CHAN	PWM_CHAN_A
#define FT817_WRAP	1020
#define FAN_SLICE	2
#define FAN_CHAN	PWM_CHAN_A
#define FAN_WRAP	1020

#define GPIO00_HPF	0
#define GPIO01_Sw12	1
#define GPIO02_RF3	2
#define GPIO03_INTTR	3
#define GPIO04_Fan	4
#define GPIO05_xxx	5
#define GPIO06_In5	6
#define GPIO07_In4	7
#define GPIO08_Out8	8
#define GPIO09_Out7	9
#define GPIO10_Out5	10
#define GPIO11_Out4	11
#define GPIO12_Sw5	12
#define GPIO13_EXTTR	13
#define GPIO14_I2C1_SDA	14
#define GPIO15_I2C1_SCL	15
#define GPIO16_Out1	16
#define GPIO17_In1	17
#define GPIO18_In2	18
#define GPIO19_Out2	19
#define GPIO20_Out3	20
#define GPIO21_In3	21
#define GPIO22_Out6	22
#define GPIO25_LED	25
#define GPIO26_ADC0	26
#define GPIO27_ADC1	27
#define GPIO28_ADC2	28

#define BAND_137k	31	// Frequency 0.139 MHz
#define BAND_500k	50	// Frequency 0.475 MHz
#define BAND_160	71	// Frequency 1.846 MHz
#define BAND_80		82	// Frequency 3.758 MHz
#define BAND_60		88	// Frequency 5.539 MHz
#define BAND_40		92	// Frequency 7.173 MHz
#define BAND_30		97	// Frequency 9.910 MHz
#define BAND_20		103	// Frequency 14.605 MHz
#define BAND_17		106	// Frequency 17.731 MHz
#define BAND_15		109	// Frequency 21.525 MHz
#define BAND_12		111	// Frequency 24.496 MHz
#define BAND_10		114	// Frequency 29.738 MHz
#define BAND_6		123	// Frequency 53.208 MHz
#define BAND_4		127	// Frequency 68.908 MHz
#define BAND_2		139	// Frequency 149.676 MHz
#define BAND_125cm	145	// Frequency 220.592 MHz
#define BAND_70cm	155	// Frequency 421.041 MHz
#define BAND_33cm	167	// Frequency 914.543 MHz
#define BAND_23cm	172	// Frequency 1263.487 MHz
#define BAND_13cm	182	// Frequency 2411.594 MHz
#define BAND_9cm	187	// Frequency 3331.738 MHz
#define BAND_5cm	196	// Frequency 5961.160 MHz
#define BAND_3cm	204	// Frequency 9998.100 MHz

typedef void (*irq_handler)(uint8_t register_number, uint8_t register_datum);

void configure_pins(bool use_uart1, bool use_pwm4a);
void configure_led_flasher(void);
void fast_led_flasher(void);
//void i2c_slave_handler(i2c_inst_t *i2c, i2c_slave_event_t event);
void IrqRxTxChange(uint gpio, uint32_t events);
void J4Pin8_millivolts(uint16_t millivolts);
void ft817_band_volts(uint8_t band);
void xiegu_band_volts(uint8_t band);
uint8_t tx_freq_to_band(uint64_t freq);
void IcomAh4(uint8_t, uint8_t);
uint8_t hertz2fcode(uint64_t hertz);
uint64_t fcode2hertz(uint8_t fcode);
uint8_t fcode2band(uint8_t fcode);

extern char gvj[30];

extern uint8_t firmware_version_major;
extern uint8_t firmware_version_minor;
extern uint64_t new_tx_freq;
extern uint8_t new_tx_fcode;
extern bool rx_freq_changed;
extern uint8_t rx_freq_high;
extern uint8_t rx_freq_low;
extern uint8_t Registers[256];
extern irq_handler IrqHandler[256];

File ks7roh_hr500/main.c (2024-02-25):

// This is firmware for the Hermes Lite 2 IO board designed by Jim Ahlstrom, N2ADR. It is
//   Copyright (c) 2022-2023 James C. Ahlstrom <jahlstr@gmail.com>.
//   Copyright (c) 2023 James Ancona <jim@anconafamily.com>.
//   It is licensed under the MIT license. See MIT.txt.

// This firmware uses the Hardrock-500 serial port commands to do band changes
// and trigger the built-in antenna tuner.

#include "../hl2ioboard.h"
#include "../i2c_registers.h"
#include "hardware/uart.h"
#include <string.h>
#include <math.h>

#define UART_ID uart0
#define BAUD_RATE 19200
#define DATA_BITS 8
#define STOP_BITS 1
#define PARITY UART_PARITY_NONE

#define DEBUG true

// These are the major and minor version numbers for firmware. You must set these.
uint8_t firmware_version_major=1;
uint8_t firmware_version_minor=2;

void PTT(bool tx)
{
	// Operate PTT
	if (tx)
		gpio_put(GPIO10_Out5, 0);   // In RX, release PTT
	else
		gpio_put(GPIO10_Out5, 1);   // Apply PTT
}

// Translate a frequency code to an HR500 band code. Out-of-band codes are mapped to
// 0 (Unknown), not the nearest band. That way the HR500 will refuse to transmit
// when far out-of-band.
uint8_t fcode2hr50_band(uint8_t frequency_code) {
	uint8_t hr50_band = 0;

	//  Band         F1           F2    Code1  Code2      Decode1      Decode2
	//   160     1.800000     2.000000     71     72     1.845712     1.968962
	if (frequency_code >= 71 && frequency_code <= 72) {
		hr50_band = 10;
	//    80     3.500000     4.000000     81     83     3.522876     4.009073
	} else if (frequency_code >= 81 && frequency_code <= 83) {
		hr50_band = 9;
	//    60     5.300000     5.430000     87     88     5.192032     5.538736
	} else if (frequency_code >= 87 && frequency_code <= 88) {
		hr50_band = 8;
	//    40     7.000000     7.300000     92     92     7.173053     7.173053
	} else if (frequency_code == 92) {
		hr50_band = 7;
	//    30    10.100000    10.150000     97     97     9.909932     9.909932
	} else if (frequency_code == 97) {
		hr50_band = 6;
	//    20    14.000000    14.350000    102    103    13.691069    14.605307
	} else if (frequency_code >= 102 && frequency_code <= 103) {
		hr50_band = 5;
	//    17    18.068000    18.168000    106    106    17.730897    17.730897
	} else if (frequency_code == 106) {
		hr50_band = 4;
	//    15    21.000000    21.450000    109    109    21.525374    21.525374
	} else if (frequency_code == 109) {
		hr50_band = 3;
	//    12    24.890000    24.990000    111    111    24.496124    24.496124
	} else if (frequency_code == 111) {
		hr50_band = 2;
	//    10    28.000000    29.700000    113    114    27.876872    29.738385
	} else if (frequency_code >= 113 && frequency_code <= 114) {
		hr50_band = 1;
	//     6    50.000000    54.000000    122    123    49.877428    53.208055
	//} else if (frequency_code >= 122 && frequency_code <= 123) {
	//	hr50_band = 0;
	}
	return hr50_band;
}

uint8_t response[256] = "";
bool response_ok = false;
bool response_ready = false;

void clear_response() {
	response[0] = '\0';
	response_ready = false;
	response_ok = false;
}

void uart_puts_log(uart_inst_t *uart, const char *s) {
	clear_response();
	uart_puts(uart, s);
#if DEBUG
	printf("sent: %s\n", s);
#endif
}

// RX interrupt handler
void on_uart_rx() {
    while (uart_is_readable(UART_ID)) {
        uint8_t ch = uart_getc(UART_ID);
        size_t len = strlen(response);
        
//        if (response_ready == true || len >= 255) {
        if (len >= 255) {
#if DEBUG
            printf("discarding: %s\n", response);
#endif
            // Throw away the old response and start again
            clear_response();
        }

        if (len < 255) {
            // Always add characters to the response until the buffer is full
            strncat(response, &ch, 1);
        }

        if (ch == ';' || len >= 254) {
            // Stop adding characters to the response if ';' is encountered or the buffer is full
            response_ok = true;
            response_ready = true;
			printf("Response OK & Ready\n");
#if DEBUG
            if (len >= 254) {
                printf("Buffer is full\n");
            }
#endif
        }
#if DEBUG
		if (response_ready == true) {
			if (response_ok) {
				printf("good: %s\n", response);
			} else {
				printf("bad: %s\n", response);
			}
		}
#endif		
    }
}

void hr50_change_band(uint8_t hr50_band) {
    char cmd[30];
    sprintf(cmd, "HRBN%d;", hr50_band);
    uart_puts_log(UART_ID, cmd);

	sleep_ms(500);

    char cmd_response[30];
    sprintf(cmd_response, "HRBN;");
    uart_puts_log(UART_ID, cmd_response);

    // Wait for the response
    for (int timeout_ms = 0; timeout_ms < 1000; timeout_ms += 10) {
        sleep_ms(10);  // Adjust the delay as needed

        // Check if a response is ready
        if (response_ready) {
			printf("Response Ready\n");
            // Check if the response is in the expected format "HRBN#"
            if (response_ok && strstr(response, "HRBN") != NULL) {
				printf("Response OK\n");
                // Extract the band number from the response
                int received_band = atoi(response + 4);

                // Compare the received band with hr50_band
                if (received_band == hr50_band) {
                    printf("HRBN command successful. Received band: %d\n", received_band);
                } else {
                    printf("HRBN command failed. Received band: %d, Expected band: %d\n", received_band, hr50_band);
                }
            } else {
                printf("HRBN command failed. Unexpected response: %s\n", response);
            }

            // Clear the response
            clear_response();
            break;
        }
    }
}
//void hr50_change_freq(uint64_t hr50_freq) {
//	char cmd[30];
//	sprintf(cmd, "FA%011d;", hr50_freq);
//	uart_puts_log(UART_ID, cmd);
//}

#define RESPONSE_BAD 0
#define RESPONSE_GOOD 1
#define RESPONSE_NOT_READY 3

uint8_t handle_serial_response(char *expected_response, char *next_command[2]) {
	uint8_t status = RESPONSE_BAD;
	if (response_ready == true) {
#if DEBUG
		printf("response: %s\n", response);
#endif
		if (response_ok) {
			if (strstr(response, expected_response) != NULL) {
				status = RESPONSE_GOOD;
				for (int i = 0; i < 2; i++) {
					if (strlen(next_command[i]) > 0) {
						uart_puts_log(UART_ID, next_command[i]);
					}
				}
			}
		}
		clear_response();
	} else {
		status = RESPONSE_NOT_READY;
	}
	return status;
}
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

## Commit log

2022-04-28 Changed the register numbers for write I2C.
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2022-05-14 Added the KiCad and source files.
    [HL2IOBoard.csv, HL2IOBoard.kicad_pcb, HL2IOBoard.sch]
2022-05-15 Add gerber files to KiCad/gerber.
    [HL2IOBoard-B_Cu.gbl, HL2IOBoard-B_Fab.gbr, HL2IOBoard-B_Mask.gbs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]
2023-03-28 Change the PCB to version 1.4 (Rev E) to replace the unavailable SSOP part with the SOIC TBD62381AFWG,EL.
    [HL2IOBoard-B_Cu.gbl, HL2IOBoard-B_Cu.gbr, HL2IOBoard-B_Fab.gbr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]
2023-03-30 Change gerber file format to that requested by Makerfabs.
    [HL2IOBoard-B_Cu.gbl, HL2IOBoard-B_Mask.gbs, HL2IOBoard-B_Paste.gbp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]
2023-04-04 Add new source directories n2adr_*. Small mods to schematic and BOM.
2023-05-13 Update README.md
    Add board test procedure.
2023-05-17 Updated pictures to board version 1.4.
2023-06-22 Update README.md. Add a table of I2C registers.
2023-06-26 Update README.md for read registers and antenna tuner.
2023-06-26 An I2C read now reads any register. Add code for an Icom AH-4 antenna tuner.
2023-07-13 Change the antenna tuner register to 7.
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2023-07-13 Move register names to i2c_registers.h.
2023-07-13 Add register, renumber antenna tuner register.
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2023-08-30 Add direct GPIO access. Add Xiegu band volts.
2023-09-12 Add the IO board control program.
    [HL2IOBoard.kicad_pcb, HL2IOBoard.kicad_sch]
2023-09-15 Change to PCB.
    [HL2IOBoard.kicad_pcb]
2023-09-19 Add files for the end plates.
    [HL2IO_endcap-B_Cu.gbl, HL2IO_endcap-B_Cu.gbr, HL2IO_endcap-B_Mask.gbr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]
2023-10-18 Add a description of the 3-pin addition to HL2 main board.
2023-11-02 Initial version of IO Board firmware to support the Hardrock-50 amplifier.
2023-12-08 Add a test for the antenna tuner protocol.
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2024-01-06 Fixed Indentation i2c_registers.h
2024-02-11 Change 2x25 connector J1 from 13.59 to 11.05 mm insulation height.
    [HL2IOBoard.kicad_sch]
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2024-03-14 Changed IcomAh4 START line to J4 pin 7
2025-05-11 Changed icom_ah4.c to fix a bug in the bad tune notification and add documentation. Slight change to frequency_code.c. Add directory w5eim.
    [icom_ah4.c, main.c]
2025-05-14 I put back the old code in icom_ah4.c because it was working fine. The new code to fix the "bug" works but has slightly less noise immunity.
    [icom_ah4.c]
2026-09-26 dl4jc_juma: firmware for a JUMA PA-100D
    Band switching and status readback for a JUMA PA-100D, and its RS-928
    clone, over the amplifier's RS-232 port. The path is the one m0hpf_spe
    takes for an SPE Expert - Pico UART, a MAX3232, the amplifier's own
    command set - but the JUMA differs in three ways that shape the firmware:
    - It is silent until asked. The SPE polls the transceiver; the JUMA
    answers '=R' and nothing else, so the Pico has to be the master.
    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
2026-09-26 dl4jc_juma: a second detection path, and the I2C bridge's one caller
    Some SDR software will not send the transmit frequency to a board it has
    not recognised. deskHPSDR looks for the PCA9536 at I2C 0x41 and expects
    four bytes of 0xF1 - which a real IO board answers in hardware, with or
    without firmware running - and failing that reads register 33 from the
    Pico at 0x1D and expects 0xEF.
    So register 33 now answers 0xEF. On an IO board this changes nothing,
    0x41 has already done the job; it is for a board built without the
    PCA9536, which is the case the comment beside that code has in mind:
    "so you can use N2ADRs firmware code base for your own projects without
    buying the IO Board". Register 34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
    [juma_gui.py, juma_theme.py, main.cpp]
2026-09-26 dl4jc_juma: the numbers from an hour of it running
    187 rounds without a retry was a short and lucky run, and quoting it
    understated how often the bridge drops a read. An hour of continuous use
    gives 97 retries in 3152 rounds - 3.1 %, in line with the one-in-25 of
    the earlier measurements - and no wrong value reached the display.
    The same hour is the better evidence for the wiring: not one unparseable
    line from the amplifier and not one lost byte, at 115200 through a
    shifter on the Pico's own pins.
2026-09-27 dl4jc_juma: no flash writes on the I2C bus, and port 1025
    Regenerated from esp32-juma v1.28.0-13-g350d9f3. Four changes, all of them
    made upstream of this folder:
    The mode is no longer kept in flash. An erase runs with interrupts off for
    tens of milliseconds, the Pico cannot serve its I2C slave during that, and
    the RP2040 then holds SCL low. The HL2's master has no timeout and no bus
    recovery, and the filter board is on that same expansion bus with its own
    address - so one erase in the wrong moment can take the bus down and stop
    the filter relays. Seen here, and only a power cycle of the HL2 cleared it.
    REG_JUMA_SAVED (0x5E) is retired with it.
    The tools talk to port 1025, as n2adr_ioboard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
    [juma_gui.py, juma_link.py, main.cpp]
2026-09-27 dl4jc_juma: instrumentation before the endurance run
    Regenerated from esp32-juma v1.28.0-16-gebd114c. The window writes the link
    coming and going to its log with a wall-clock time, instead of only to a
    label in the window that nobody watches for hours. And listing serial ports
    can no longer raise: on macOS it goes through IOKit by ctypes, which
    PyInstaller cannot follow into a bundle, and a failure there would have
    stopped the search for a cable before the network route was ever tried.
    Neither changes what goes on the wire. The run that follows has to have
    exactly one changed variable in it, and that one is already spent on the
    flash writes.
    [juma_gui.py, juma_link.py]
2026-09-27 dl4jc_juma: --no-usb means the cable too, and the log names what it tried
    Regenerated from esp32-juma v1.28.0-18-g9c6354f.
2026-09-27 dl4jc_juma: generated from hl2io-juma now
    The Hermes Lite 2 controller moved out of the ESP32 firmware's repository into
    one of its own. Only the provenance note changes here - it points at the place
    corrections belong, which is no longer esp32-juma.
2026-09-27 dl4jc_juma: one command per tick on the HL2's bridge
    The endurance run showed the expansion bus going after 31 minutes of polling
    with the flash writes already gone, while the Pico carried on for another 7.7
    hours - so what costs the bus is on the host side, and it was not the number of
    commands but their shape. A snapshot used to be eight commands back to back,
    and a set the bridge had torn was read again in full, up to 24 in one go.
    n2adr_ioboard.pyw never sends two in a row: one four-byte group per 100 ms
    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
2026-09-27 dl4jc_juma: maintained here now, not generated somewhere else
    This folder used to be assembled by a script in another repository, because the
    parser and the band table were shared with an ESP32 firmware and pointed at by a
    relative path. That repository is for an ESP32 firmware and this is a Pico one,
    so it does not live there any more - and with nowhere left to generate it from,
    the folder is simply the place the work happens. Which is also where it has to
    end up for a pull request.
    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
2026-09-27 dl4jc_juma: the last two files from the folder it was generated from
    crop_shots.py trims the window screenshots the README shows, and the MIT
    licence text belongs beside the code it covers - the project's MIT.txt at the
    root says the same thing for the board's library. Both were left behind by the
    generator, which only ever copied what a build needed.
    The PyInstaller virtual environment for make_app.py moved here too; it is
    ignored, not committed.
2026-09-27 dl4jc_juma: tell a held line from a master that stopped
    The expansion bus has died twice here, and both times it looked the same from
    outside: no register answered, the band stopped following, the filter board
    stopped switching, only a power cycle of the HL2 brought it back. But those are
    two faults, and only one of them could ever be repaired from this board:
    a line is held down - a jam. SCL or SDA stays low and the cure is to clock
    SCL until the stuck device lets go. This board owns
    the pins, so it could do that.
    the master stopped - the gateware waits for something inside itself. The
    lines are idle and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
    [juma_link.py, main.cpp]
2026-09-27 dl4jc_juma: the radio rewrites the frequency 2.5 times a second
    The comment beside 'idle' warned that it cannot prove the bus is gone, because
    IrqHandler only fires on a write and a station parked on one frequency might
    have nothing to write. Measured on a gateware 74.2 with nothing on the bridge:
    wr climbs by about 2.5 a second regardless. So on this radio idle does climb
    when the bus dies - said as a measurement, with the caveat kept for the next
    radio.
    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
2026-09-27 dl4jc_juma: write down the rule, so it is not rediscovered
    The firmware already keeps it - the flash write was the last thing that broke
    it - but nothing said so, and the reason is not obvious from the code. A future
    change that wants to remember a setting, or take a critical section, or busy-wait
    with interrupts masked, has no way of knowing what that costs here.
    What it costs: this Pico is an I2C slave, and a slave that cannot answer in time
    does not fall behind, it pulls SCL low and holds it. That is what I2C asks of it.
    The master at the other end has no timeout and no bus recovery, so once it stops
    it stays stopped - 7.7 hours in the case measured here - and the filter board on
    the sam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
2026-09-28 dl4jc_juma: clock the bus free when a device is holding SDA
    The night answered it. The new pacing stretched the time to failure from 31
    minutes to 6 h 33, but did not prevent it, and the measurement finally says what
    the fault is instead of leaving it to be guessed:
    up=44029 wr=72563 idle=20302 sda=0 scl=1 rep=109862 bad=0 lost=0
    idle matches the log's 'link lost' to the second, wr is frozen so not one write
    is arriving, the Pico has been up 12.2 hours with a flawless link to the
    amplifier - and SDA reads low in 22 of 25 samples. That is the textbook I2C
    deadlock: a device is driving a data bit and waiting for a clock edge that never
    comes, because the master stopped mid-transaction. D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
    [juma_link.py, main.cpp]
2026-09-28 dl4jc_juma: a way into the bootloader while the radio is on
    The button is only sampled at RESET, and plugging in USB does not reset a chip
    that is already powered from the HL2 - so with the radio switched on the Pico
    ignores the button entirely. Which is exactly when you want to reflash it: the
    bus has just deadlocked and a power cycle would throw the evidence away.
    'bootsel' on the USB console calls reset_usb_boot(). The SDK's other route is a
    vendor interface that only a picotool built with USB support can reach, and the
    one the SDK builds for itself is not.
    [main.cpp]
2026-09-28 dl4jc_juma: the ESP32 repository is not called what I called it
    The link said github.com/jcmerg/esp32-juma, which is the local directory name.
    The repository is juma-pa100d-esp32. Same mistake as the one just fixed on the
    other side: a cross-link written from memory instead of from the remote.
2026-09-28 dl4jc_juma: own the parser and the band table, and a way to provoke the fault
    Two changes, both about not depending on something else.
    The parser and the band table came from an ESP32 firmware for the same amplifier
    and were kept byte for byte identical, with tools/sync_shared.py reporting when
    the copy went stale. Two projects, two READMEs - and one of them spent a section
    explaining that four of its six source files were somebody else's. They are this
    project's files now: the script is gone and they are edited here like everything
    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
2026-09-28 dl4jc_juma: the stress tool has to flush every line
    Watched through its log file, the first real run showed the discovery trace and
    nothing else - those lines go to stderr, the measurements go to stdout, and
    stdout redirected to a file buffers in blocks. The test was running correctly
    and looked hung.
    A tool whose whole purpose is to say when something happened cannot hold the
    news until it exits.
    [stress_bridge.py]
2026-09-28 dl4jc_juma: one recovery attempt, and an honest idle
    Two small corrections from what the deliberate deadlock showed.
    RECOVER_MAX was ten. Clocking the bus free does release SDA - it went 0 to 1
    every time - and the master never resumes, so SDA is pulled down again within
    the minute. Nine more attempts at something measured not to work is noise on a
    bus that is already gone, from the only code here that drives it at all. One
    still answers the question worth asking, which is whether the fault is the
    held-line kind. It is a diagnosis, not a repair.
    And idle printed 0 when nothing had ever arrived, which next to wr=0 reads as
    "just seen" - the opposite of what it means, and exactly the state t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
    [main.cpp]

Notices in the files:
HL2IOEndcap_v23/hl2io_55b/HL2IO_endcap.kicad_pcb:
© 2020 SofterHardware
